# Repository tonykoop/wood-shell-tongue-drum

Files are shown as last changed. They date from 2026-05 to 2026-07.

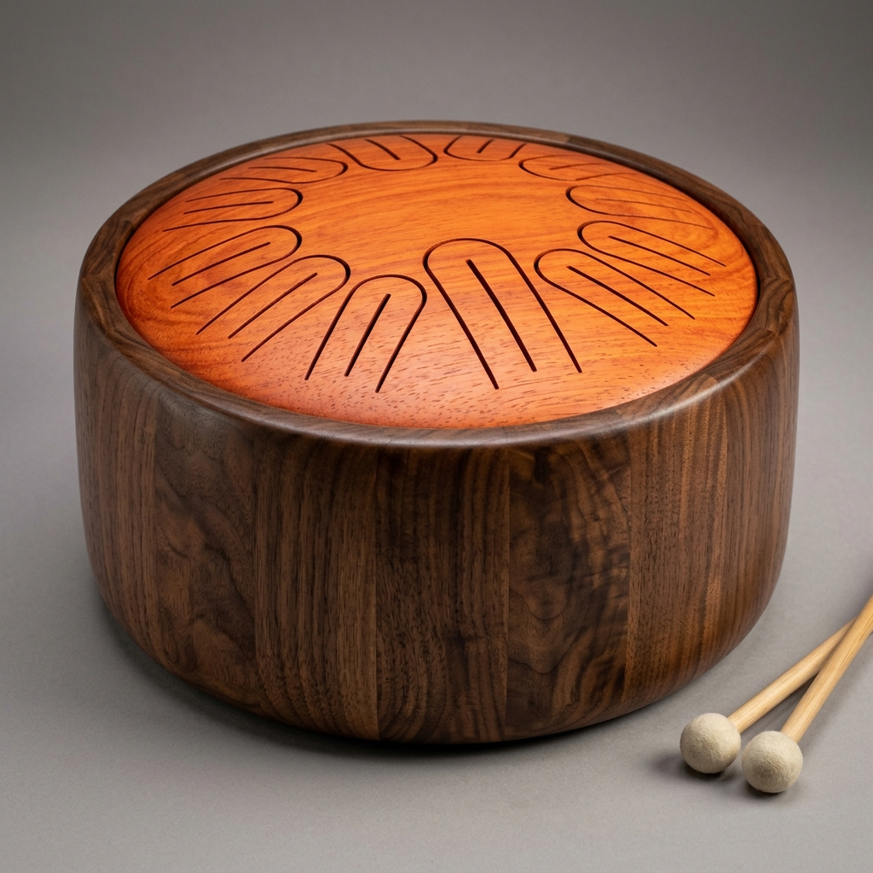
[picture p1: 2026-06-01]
images/hero-render.png

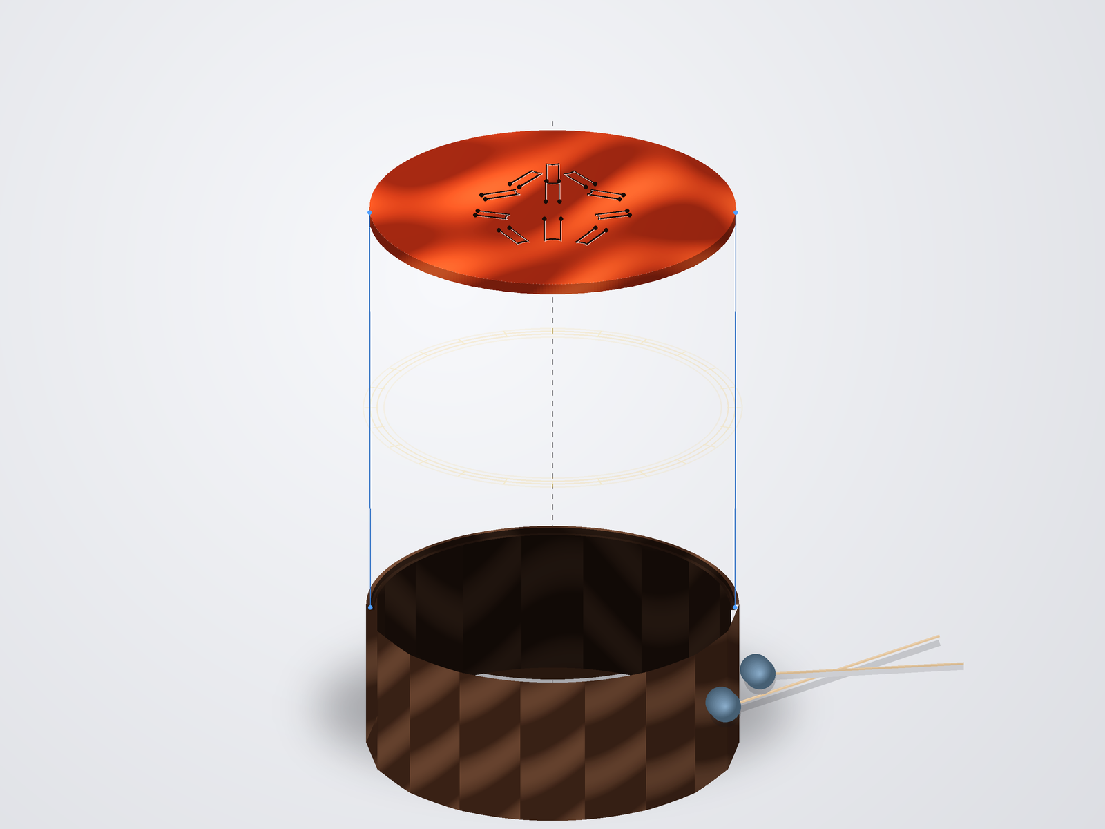
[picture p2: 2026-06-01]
images/exploded-diagram.png

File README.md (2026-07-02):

# Wood Shell Tongue Drum

Status: L2 V5 build-packet candidate

Slit-tongue idiophone with an enclosed wooden resonator. A round-body counterpart to the rectangular-prism wood tongue drum, with **Helmholtz cavity coupling** absent from open designs. Four geometric variants × three size envelopes, all parametric and traceable to a single design table.

Part of the [tonykoop/instrument-maker](https://github.com/tonykoop/instrument-maker) catalogue.

V1 Standard 16″ side section A-A

*V1 Cylinder + Flat Top, Standard 16″ — recommended first prototype. Black Walnut staves, Padauk soundboard, A Kurd 11-tongue field, gu port for Helmholtz tuning. The design table estimates `f_H = 194.6 Hz`, or 0.88 × the A3 ding (220 Hz), which targets the coupled regime but still requires Phase 1 measurement.*

**Current V5 status:** L2 V5 build-packet candidate with pending measurement authority. The design table, packet docs, print packet, and hero SVG are useful for review, but the repo is not build-ready or measured. Tongue tuning, Helmholtz coupling, Padauk material constants, shell response, CAD, DXF, and G-code all remain measurement- or calibration-gated. No Round 2 recovery work added fabricated CAD geometry, DXF coordinates, or new tuning frequencies. See [`v5-readiness.md`](v5-readiness.md), [`tuning-gates.md`](tuning-gates.md), [`validation-loop.csv`](validation-loop.csv), [`visual-output-register.csv`](visual-output-register.csv), and [`explorer.html`](explorer.html).

## What's new in this design

A round-body wood tongue drum with an enclosed cavity is not a commercial category at this depth. Three things distinguish it:

1. **Round body, not rectangular.** Tony's existing rectangular-prism wood tongue drum is the precursor; this design moves the same flat-cantilever physics onto a turned cylinder or hemisphere bowl.
2. **Enclosed Helmholtz cavity.** Open rectangular tongue drums waste cavity volume out the open ends. Closing the bowl puts a Helmholtz resonator under the tongue field — bass extension below the lowest tongue, tunable in the shop via the gu port.
3. **Premium tonewoods, manufacturable scope.** Padauk soundboard for the A4 reference; Black Walnut shell for the bowl. Four variants × three sizes laid out as a coordinated portfolio family rather than four bespoke pieces.

## The matrix

Four geometric variants × three size envelopes = twelve cells. Each cell carries its own chamber volume, Helmholtz frequency, tongue-fit verdict, and risk grade.

| Variant | Body | Top | Risk | Notes |
|---|---|---|---|---|
| V1 | Cylinder (ottoman silhouette) | Flat soundboard | ★★ | Lowest piece-count, most predictable tuning. **Start here.** |
| V2 | Cylinder | Shallow CNC-domed | ★★★ | Steel-tongue-drum aesthetic on a wooden body |
| V3 | Hemisphere bowl | Flat soundboard | ★★ | Tagine / Moroccan-pouf silhouette |
| V4 | Hemisphere bowl | Domed top | ★★★★ | Most steel-tongue-drum-adjacent silhouette in wood |

**Sizes:** Travel 12″ Ø · Standard 16″ Ø (Moroccan-ottoman scale) · Floor Pouf 20″ Ø.

The full Helmholtz/ding ratio matrix is in [`design.md`](design.md) §2.4. Current estimates put three cells in the target coupled band (V1 Standard, V1 Floor Pouf, V3 Standard); V2 cells need a larger-than-preset gu port or a lower cavity/neck correction to reach coupling; V1 Travel sits right at the upper edge of the band.

## Recommended first prototype

**V1 Cylinder + Flat Top, Standard 16″, A Kurd, A3 ding (220 Hz), 11 tongues.** Justification:

- Acoustic predictability — flat-cantilever physics has < 1 % empirical detuning on Tony's prior rectangular drums.
- Design-table Helmholtz ratio targets the coupled band at `f_H/f_ding = 0.88`, pending measured cavity response.
- All 11 A Kurd tongues fit within the 7″ radial cap with 8 % margin.
- Lowest piece-count: 16 staves + 1 disc = 17 wood pieces.
- Dual body-construction paths (stave or segmented) — pick the aesthetic, the physics is the same.
- Previously exercised workflow components — stave glue-up, lathe truing, CNC slit routing — from Tony's existing ashiko, conga, and tongue-drum repos.

Detailed prototype spec (dimensions, tongue length schedule, joint tolerances) in [`design.md`](design.md) §4.

## Acoustic model in one paragraph

The wood shell tongue drum is a 2-DOF coupled oscillator: the cantilever tongue is one resonator, the enclosed air cavity is another, and they share a common boundary (the soundboard). Tongues follow flat-cantilever Euler-Bernoulli `f = K · t / L²`, with `K ≈ 24,438` for Padauk. Domed tongues add a +2.5 % length correction (a starting estimate to be calibrated empirically on the first V2 build). The cavity follows the Helmholtz formula `f_H = (c/2π) · √(A_port / (V · L_neck))`; the gu port is the primary tuning knob — drilled last and step-bored in the shop while measuring `f_H`. Target: `f_H/f_ding ∈ [0.80, 1.20]`. See [`design.md`](design.md) §2 for the full derivation.

## Repo contents

| File / folder | Purpose |
|---|---|
| [`design.md`](design.md) | Governing model, variant blocks, recommended prototype |
| [`wood-shell-tongue-drum-design-table.xlsx`](wood-shell-tongue-drum-design-table.xlsx) | Parametric workbook (190 formulas, 1 sheet) |
| [`family-spec.csv`](family-spec.csv) | Twelve family rows spanning V1-V4 across Travel / Standard / Floor Pouf |
| [`v5-readiness.md`](v5-readiness.md) / [`tuning-gates.md`](tuning-gates.md) / [`validation-loop.csv`](validation-loop.csv) | V5 authority notes, tongue-tuning gates, and empirical validation loop |
| [`visual-output-register.csv`](visual-output-register.csv) / [`explorer.html`](explorer.html) | Visual authority register and root explorer dashboard |
| [`bom.csv`](bom.csv) / [`sourcing.csv`](sourcing.csv) / [`cut-list.csv`](cut-list.csv) / [`validation.csv`](validation.csv) | Manufacturing CSVs |
| [`assembly-manual.md`](assembly-manual.md) | 7-phase build instructions |
| [`supplier-rfq.md`](supplier-rfq.md) | Q2 2026 batch supplier RFQ |
| [`drawing-brief.md`](drawing-brief.md) / [`drawings/`](drawings/) | 9-sheet drawing spec + hero SVG |
| [`visual-bom-brief.md`](visual-bom-brief.md) / [`photo-shotlist.md`](photo-shotlist.md) | Photography briefs |
| [`risks.md`](risks.md) | Red-team pass with verification tests attached |
| [`joinery-configuration-matrix.md`](joinery-configuration-matrix.md) | Practical shell and soundboard joinery comparison for issue `instrument-maker#118` |
| [`resources.md`](resources.md) / [`jig-decision.md`](jig-decision.md) | Public-safe provenance, references, and fixture decisions |
| [`wolfram-starter.wl`](wolfram-starter.wl) | 3-DOF coupled-oscillator notebook starter |
| [`wolfram/`](wolfram/) / [`jigs/`](jigs/) / [`data/`](data/) | Starter folders for notebook notes, fixture docs, and future measurements |
| [`capstone-deck.md`](capstone-deck.md) / [`print-packet.md`](print-packet.md) | Recruiter-facing deck + shop-floor printable packet |
| [`cad/`](cad/) / [`cnc/`](cnc/) | Toolpath plans, jig decisions, laser templates, CAD staging; `cad/wood-shell-tongue-drum.scad` is a parametric shell+soundboard+tongue-layout envelope (`pending_measurement`); `cad/mcp-session-log.md` records provenance |
| [`cnc/jig-and-template-plan.md`](cnc/jig-and-template-plan.md) | Fixture choice matrix for the first prototype and later variants |
| [`site/index.html`](site/index.html) | Build-log static site |
| [`concepts/`](concepts/) | Original concept sheet (ideation, not manufacturable) |
| [`evolution/`](evolution/) | Evolution-pipeline Stage 0 intake: master manifest, design-intent, revision register (Gate A not yet run) |

## Build status

- ✅ Parametric design table (workbook + `design.md` packet)
- ✅ BOM, sourcing, cut list, validation CSVs
- ✅ Assembly manual, supplier RFQ, drawing brief, visual BOM brief, photo shot list
- ✅ Risks register (16 entries across acoustic, structural, ergonomic, supply, fit/finish)
- ✅ Family-spec row set, resources notes, tuning gates, and jig-decision adjuncts
- ✅ Wolfram notebook starter (3-DOF coupled oscillator)
- ✅ CNC/laser/jig decision plan for public review
- ✅ Build-log site (`site/index.html`)
- ✅ Hero side-section preview (`drawings/00-hero-v1-standard.svg`; derived preview only, not fabrication authority)
- ✅ V5 authority register and MCP-session-log stub
- ⏳ Phase 1 prototype: V1 Cylinder · Flat at 16″ Standard
- ⏳ SolidWorks CAD assembly (deferred until first-prototype calibration)
- ⏳ Auto-generated SVG sheets 01–09 from `scripts/generate_drawings.py`
- ✅ Capstone markdown and print-packet PDF generated from the repo sources
- ⏳ Capstone .pptx refresh (requires python-pptx in the local generator environment)

## Prototype Planning Boundary

For current V5 work, treat this repo as a prototype/planning packet: excellent
for design review and first-prototype planning, but not build-ready evidence.
The coupled cantilever-plus-Helmholtz plan is documented, yet the critical
values still need real prototype measurements: Padauk effective K, port end
correction, tongue pitch, chamber response, sustain, and seasonal joint
behavior.

The packet can advance only after the V1 Standard prototype has populated
`validation.csv` and `validation-report.md` with measured Hz, cents error,
Helmholtz response, tuning-pass notes, and post-rest drift.

## Highest-risk unknowns

To be retired by Phase 1 measurements:

1. Curved-cantilever multiplier for our specific dome rise (V2/V4 only; +2.5 % is a starting estimate).
2. Helmholtz end-correction term for slit ports vs circular ports (all variants).
3. Padauk K-constant for our specific stock vs the library value (24,438).
4. Bowl-top rabbet joint long-term durability under seasonal humidity cycling.
5. Player ergonomics on Floor Pouf 20″ (new size class for Tony's catalog).

Full risk register with mitigations and verification tests in [`risks.md`](risks.md).

## Sister repos

- [`tonykoop/tongue-drum`](https://github.com/tonykoop/tongue-drum) — rectangular-prism precursor, validates flat-cantilever physics
- [`tonykoop/steel-tongue-drum`](https://github.com/tonykoop/steel-tongue-drum) — steel cantilever cousin
- [`tonykoop/ceramic-tongue-drum`](https://github.com/tonykoop/ceramic-tongue-drum) — slip-cast cousin
- [`tonykoop/ashiko-drum-workshop`](https://github.com/tonykoop/ashiko-drum-workshop) — segmented bowl reference
- [`tonykoop/conga`](https://github.com/tonykoop/conga) — stave & segmented shell reference
- [`tonykoop/instrument-maker`](https://github.com/tonykoop/instrument-maker) — orchestrating skill, Master Catalog, validate_packet.py

## License

[CC BY 4.0](LICENSE) — see LICENSE for details. The design (workbook, drawings, narrative) is shared under CC BY 4.0; the maker should still apply their own judgment to material selection and shop safety.

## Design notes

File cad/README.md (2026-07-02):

# CAD — Wood Shell Tongue Drum

This folder holds the SolidWorks parametric assembly and any exported neutral-format files (STEP, IGES, STL) for the wood shell tongue drum family.

## Status

**Empty at first commit.** SolidWorks files are produced after the first prototype's measurements are folded back into the workbook so the CAD reflects calibrated, not estimated, dimensions.

**Update 2026-07-01:** `wood-shell-tongue-drum.scad` was added as a parametric
OpenSCAD *planning envelope* (shell + soundboard + tongue position/length
layout reference marks from design.md §4 and drawing-brief.md Sheet 03). It
is `pending_measurement`, does not model slit-routing cut geometry, and does
not replace the SolidWorks assembly plan below.

## Planned contents

```
cad/
├── README.md                    (this file)
├── wood-shell-tongue-drum.SLDASM        — top-level family assembly
├── parts/
│   ├── shell-cylinder.SLDPRT            — V1, V2 body
│   ├── shell-hemisphere.SLDPRT          — V3, V4 body
│   ├── soundboard-flat.SLDPRT           — V1, V3 top
│   ├── soundboard-domed.SLDPRT          — V2, V4 top
│   ├── stave-template.SLDPRT
│   ├── ring-segment-template.SLDPRT
│   └── gu-port-feature.SLDPRT
├── design-table/
│   └── wood-shell-tongue-drum-design-table.xlsx  — symlink to repo root
├── exports/
│   ├── v1-standard-16.step               — for KiCad/Fusion interop
│   ├── v1-standard-16.stl                — for 3D-print prototype shells
│   └── soundboard-tongue-field.dxf       — for laser-cut tongue layout templates
└── sw-reference/
    └── (Pack-and-Go bundles for derived family members)
```

## SolidWorks workflow

The assembly is **driven by the parametric workbook** (`wood-shell-tongue-drum-design-table.xlsx`) at the repo root. Per `references/solidworks-integration.md` in the parent instrument-maker skill, the workflow is:

1. Open `wood-shell-tongue-drum.SLDASM` in SolidWorks.
2. The design table is linked via External Reference. SolidWorks reads the size-preset block (rows 179–195) on rebuild.
3. Change a preset cell in the workbook; rebuild the assembly; geometry updates.
4. Run the `Extract_Dimensions.swp` macro (in `assets/solidworks/` of the parent skill) to dump every dimension to a CSV.
5. Run `python3 scripts/ingest_dimension_csv.py --csv ... --workbook ...` from the parent skill to validate SW dimensions vs Excel design table within ± 0.5 % tolerance.

A MasterLayout pattern (per Tony's standard) keeps geometry coherent across V1 → V4 by sharing the shell-OD, shell-height, and soundboard-thickness sketches.

## Why CAD is deferred

The first prototype is V1 Cylinder + Flat Top, Standard 16″ — a geometry that is fully specified by the workbook formulas and the cut-list dimensions. Stave geometry, lathe truing, and rabbet joint can all be built from the cut-list alone. CAD becomes load-bearing when:

1. We need 3D-surface toolpaths for V2/V4 dome work (fed to Fusion CAM).
2. We want to pre-visualize the segmented bowl ring stack for V3/V4.
3. The polychrome-segment aesthetic requires per-segment color planning.

Until then, the workbook drives the build and CAD ships when its leverage justifies its production cost.

## Cross-references

- Parametric source: [`../wood-shell-tongue-drum-design-table.xlsx`](../wood-shell-tongue-drum-design-table.xlsx)
- Drawing brief (what the SVGs will show): [`../drawing-brief.md`](../drawing-brief.md)
- CNC toolpath plan: [`../cnc/README.md`](../cnc/README.md)
- SolidWorks workflow reference: [`tonykoop/instrument-maker`](https://github.com/tonykoop/instrument-maker) → `references/solidworks-integration.md`

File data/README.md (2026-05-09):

# Data

Measured build data lands here once physical prototypes begin.

## Expected Artifacts

- First-strike pitch logs per tongue.
- Helmholtz port-step measurements.
- Kerf and thickness verification notes.
- Sustain / decay captures.
- Photos or scans of handwritten bench notes that support `validation.csv`.

## Current Status

No measured prototype data exists yet. Until then, `validation.csv` remains a prediction-and-plan surface rather than a completed results table.

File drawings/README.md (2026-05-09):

# Drawings

The current packet ships a single hero SVG and a detailed drawing brief. Full sheet generation is intentionally deferred until the workbook and first-prototype measurements stabilize the family dimensions.

## Present In Repo

- `00-hero-v1-standard.svg` - public-safe side-section hero for the recommended first prototype.

## Planned Sheet Set

- `01-variant-matrix.svg`
- `02-v1-standard-side-section.svg`
- `03-v1-standard-tongue-layout.svg`
- `04-shell-stave-template.svg`
- `05-shell-segment-template.svg`
- `06-rabbet-joint-detail.svg`
- `07-dome-toolpath.svg`
- `08-bowl-segment-stack.svg`
- `09-gu-port-tuning-progression.svg`

## Source Of Truth

See `../drawing-brief.md` for the required dimensions, datums, tolerances, and sheet intent.

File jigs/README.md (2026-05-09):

# Jigs

This folder tracks fixture intent without pretending the physical jigs are already built.

## Required Jigs

1. Stave bevel reference jig for 11.25 degree cylinder staves.
2. Shell glue-up support or caul that preserves roundness through cure.
3. Soundboard layout overlay and hold-down clearance template.
4. Temporary tuning / measurement support that does not damp the tongue field.

## Future Jigs

- Dome flip jig for V2 and V4.
- Hemisphere ring-stack centering fixture for V3 and V4.
- Gu-port drilling locator if repeated family builds justify it.

## Cross-Reference

See `../cnc/jig-and-template-plan.md` for the current decision matrix and validation gates.

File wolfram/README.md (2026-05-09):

# Wolfram

Wolfram-specific notes and future notebook derivatives live here.

## Current Source

- `../wolfram-starter.wl` - starter notebook source for the coupled tongue + cavity model.

## Planned Contents

- Exploratory notebooks for dome-multiplier back-solving.
- Helmholtz port-step plots from measured builds.
- Family comparison plots once Travel / Standard / Floor Pouf data exists.

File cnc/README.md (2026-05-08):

# CNC — Wood Shell Tongue Drum

This folder holds CNC toolpaths, post-processed G-code, fixture STLs, and tool-list files for the wood shell tongue drum family.

For the public review pass, the most important CNC deliverable is the setup logic rather than premature G-code. The first prototype can be built from the workbook, cut list, and manual CAM setup, while later V2/V4 dome work waits for calibrated CAD. The fixture and template choices are tracked in [`jig-and-template-plan.md`](jig-and-template-plan.md).

## Critical CNC operations

| Operation | Variants | Tool | Stock | Stepover / DOC |
|---|---|---|---|---|
| Soundboard tongue slits | All | 1/8″ upcut spiral, 1/4″ shank  | Padauk disc, 0.25″–0.5″ thick | full-depth single pass at 100 ipm feed |
| Soundboard OD profile cut | All | 1/4″ compression, 1/4″ shank | Padauk disc, oversize blank | 0.250″ DOC, multi-pass |
| Dome 3D surfacing — convex top| V2, V4 | 3/4″ ball-end, 1/2″ shank | Padauk glue-up blank, 1.5″ thick | 0.05″ stepover, 0.25″ DOC |
| Dome 3D surfacing — concave bottom | V2, V4  | 3/4″ ball-end, 1/2″ shank | flip-jig with datum pins | 0.05″ stepover, 0.25″ DOC |
| Bowl 3D surfacing — exterior  | V3, V4 (CNC alt) | 3/4″ ball-end, 1/2″ shank  | Black Walnut glue-up blank, 5″ thk | 0.05″ stepover, 0.50″ DOC |
| Bowl 3D surfacing — interior  | V3, V4 (CNC alt) | 3/4″ ball-end, 1/2″ shank  | flip-jig with datum pins | 0.05″ stepover, 0.50″ DOC |

## Tool list

All tools listed in `bom.csv` under tooling rows. Critical tools:

- `SLIT-BIT-UPCUT-1-8` — Amana 46202 1/8″ solid carbide upcut spiral. Buy 3 (one breaks per shell).
- `BALLEND-3-4` — Amana 46377 3/4″ ball nose, 1/2″ shank. One bit good for 3+ dome surfaces if kept clean.

## Laser/template plan

| Template | Tool | Material | Purpose | Public-review status |
|---|---|---|---|---|
| Soundboard tongue layout | Laser | 1/8″ MDF or chipboard | Physical overlay to verify tongue spacing before CNC routing | Required before first cut |
| Vacuum gasket / tape map | Laser | 1/16″ rubber sheet or kraft template | Keeps hold-down clear of slit kerfs and tongue tips | Required before first cut |
| Stave numbering labels | Laser or printer | Masking tape / paper | Keeps 16-stave grain order stable through glue-up | Nice-to-have |
| Gu-port tuning card | Laser or printer | Cardstock | Measurement log by port diameter; taped to the bench during step drilling | Required for validation |

## Tongue-slit toolpath spec

The tongue field on the recommended V1 Standard 16″ prototype has 11 slits in the A Kurd zigzag-ascending layout (see `drawing-brief.md` §03 for radial coordinates).

**Fixture:** soundboard disc held face-up on a 16″ MDF backing board with double-sided tape OR vacuum hold-down. Datum: disc center to spindle home.

**Cut order:** ding first (centered slit), then tongues 1, 2, 3, … in radial order. Cutting from inside-out minimizes stress accumulation.

**Cut depth:** through the soundboard thickness + 0.030″ to ensure clean break-through into the spoilboard. On 0.375″ Padauk: cut depth = 0.405″.

**Feed/speed:** 100 ipm feed at 18,000 RPM with 1/8″ upcut spiral. Validate on a poplar test cut first.

**Tongue-base relief:** the slit terminus is a 1/8″-radius half-circle at the tongue base (eyelet detail). This relieves stress concentration and gives a defined free length. The radius matches the bit diameter — single-axis plunge then retract.

**Slit width:** 1/8″ kerf (single pass with the 1/8″ bit). Holding ± 0.005″ kerf width is critical; verify with feeler gauge on a test cut.

## Dome 3D-surfacing toolpath spec (V2, V4)

Dome blank: 17″ × 17″ × 1.5″ Padauk glue-up, 3 plies of 0.5″.

**Coordinate system:** Z-zero on the top of the blank; X/Y origin at the blank center.

**Surface model:** parabolic dome with rise per size preset (Standard: 0.75″). Equation in Fusion / SolidWorks: `z = rise × (1 - (r/R)^2)` where `R = OD/2` and `r = sqrt(x² + y²)`.

**Stepover:** 0.05″. Adaptive scallop control around the rim where the slope is steepest.

**Two-sided machining:**
1. Machine convex top first; allow the bottom datum pins to remain unprofiled.
2. Flip-jig the blank into a fixture with three datum pins located 1″ inside the 16″ rim circle.
3. Machine concave bottom matching the rabbet rim profile.

**Surface finish target:** ≤ 32 µin Ra. Verify with a comparator block; if scallop steps are visible, reduce stepover to 0.03″.

## Pre-built G-code files

```
cnc/
├── README.md                    (this file)
├── tongue-slits-v1-standard.nc  — recommended first prototype slit field
├── tongue-slits-v1-travel.nc    — 12" Travel size
├── tongue-slits-v1-floor.nc     — 20" Floor Pouf size
├── soundboard-od-profile.nc     — disc cut to OD with rabbet allowance
├── dome-convex-v2-standard.nc   — V2 Standard 16" dome top
├── dome-concave-v2-standard.nc  — V2 Standard 16" dome bottom
├── dome-convex-v4-standard.nc   — V4 Standard 16" dome top (same as V2)
└── fixtures/
    ├── flip-jig-datum-pins.stl  — 3D-print fixture for dome flip
    ├── soundboard-vacuum-mat.dxf — laser-cut vacuum gasket pattern
    └── tongue-field-jig.stl     — workholding for tongue-tuning at the bench
```

## Status

**G-code files are intentionally deferred at first public review.** They are emitted from the SolidWorks / Fusion CAD models once the first prototype's measurements have calibrated the workbook formulas. Building the V1 Standard prototype from the cut list and manual CAM setup is the recommended fast-track to first measurements.

## Cross-references

- Tongue lengths: [`../design.md`](../design.md) §4
- Tool spec: [`../bom.csv`](../bom.csv) (tooling rows)
- CAD source: [`../cad/README.md`](../cad/README.md)
- Drawings: [`../drawing-brief.md`](../drawing-brief.md)

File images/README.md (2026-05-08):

# Images

Photographs of the wood shell tongue drum prototype, build process, and finished pieces. Populated against [`../photo-shotlist.md`](../photo-shotlist.md).

## Status

**Empty at first commit** — no physical prototype exists yet. The hero side-section drawing in `../drawings/00-hero-v1-standard.svg` carries the visual weight of the documentation until Phase 1 prototype photography begins.

## Naming convention

`<SHOT-ID>_<short-slug>.jpg` (e.g., `HERO-001_v1-std-finished.jpg`).

Shot IDs are defined in `../photo-shotlist.md`. As builds complete, each Required entry's Status is updated to Captured and the file path is dropped into the shot-list table.

## Resolution

- Capture: 4000 × 6000 minimum (≥ 24 MP).
- Web export (for `../site/index.html`): 2000 × 3000 JPEG, ~85 % quality.
- Print export (for `../print-packet.pdf`): full resolution, embedded via `../scripts/generate_capstone_docs.py`.

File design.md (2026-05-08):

# Wood Shell Tongue Drum — Parametric Design Sheet

**Owner:** Tony Koop · Heifer Zephyr Instruments
**Family:** Slit-tongue idiophone with enclosed wooden resonator (round-body)
**Members:** four geometric variants (V1–V4) × three size envelopes (Travel 12″, Standard 16″, Floor Pouf 20″)
**Status:** Design v1 — formulas parametric in `wood-shell-tongue-drum-design-table.xlsx`; no physical prototype yet
**Recommended first prototype:** **V1 Cylinder + Flat Top, Standard 16″, A Kurd**

---

## 1. Intent

This is the round-body counterpart to Tony's existing rectangular-prism wood tongue drum. A wooden shell — cylinder or hemisphere — capped by a tonewood soundboard with CNC-cut slit tongues, tuned to a chosen scale, is a modern instrument category that does not exist commercially in this round-body × dome-top × premium-tonewood format. The enclosed cavity adds **Helmholtz resonance** that an open rectangular tongue drum cannot offer — warm bass coupling beneath the lowest tongue.

The sheet treats this as a *family with four variants* rather than as four separate designs. All twelve cells (4 variants × 3 sizes) are driven by the same shared inputs: shell OD, shell height, soundboard thickness/wood, gu-port diameter, dome rise. Change one preset cell in the workbook and every dimension in the matrix updates.

| ID  | Body | Top | Notes |
|-----|---|---|---|
| V1  | Cylinder | Flat | Lowest piece-count, most predictable tuning. **Start here.** |
| V2  | Cylinder | Domed | Steel-tongue-drum aesthetic on a wooden body |
| V3  | Hemisphere bowl | Flat | Tagine / Moroccan-pouf silhouette; bowl as parabolic reflector |
| V4  | Hemisphere bowl | Domed | Most steel-tongue-drum-adjacent silhouette in wood; near-spherical |

| Size | OD (in) | Height (in) | Soundboard (in) | Tongue width (in) | Target ding | Ding f (Hz) |
|---|---|---|---|---|---|---|
| Travel | 12 | 5 | 0.250 | 1.00 | D4 (MIDI 62)| 293.66 |
| Standard | 16 | 8 | 0.375 | 1.25 | A3 (MIDI 57)| 220.00 |
| Floor Pouf | 20 | 10 | 0.500 | 1.50 | D3 (MIDI 50)| 146.83 |

(All values in this document are computed from the workbook formulas, not pasted by hand. If you change the workbook, regenerate the BOM and validation CSVs.)

---

## 2. Governing acoustic model

The wood shell tongue drum is a **two-degree-of-freedom coupled oscillator**: the cantilever tongue is one resonator, the enclosed air cavity is another, and they share a common boundary (the soundboard).

### 2.1 Tongue — flat cantilever (Euler–Bernoulli)

For a slit tongue of length `L` (in) and thickness `t` (in) in wood with cantilever K-constant `K` (imperial composite):

```
f = K · t / L²              (flat top, Variants 1 and 3)
L = √( K · t / f )
```

Tony's material library (workbook §A, rows 19–25) records measured / literature K-constants for shop tonewoods:

| Wood | E (GPa) | ρ (kg/m³) | K (cantilever) | Tone | Rating |
|---|---|---|---|---|---|
| Padauk | 11.0 | 745 | 24,438 | warm, rich, sustain| ★★★★★ |
| Wenge | 15.8 | 870 | 27,103 | bright, punchy | ★★★★★ |
| Cherry | 10.3 | 560 | 27,275 | balanced sweet mid | ★★★★  |
| Black Walnut  | 11.6 | 610 | 27,734 | full, mellow | ★★★★  |
| Hard Maple | 12.6 | 705 | 26,887 | bright sustain | ★★★★  |
| Mahogany | 10.1 | 590 | 26,314 | warm, full bass | ★★★★  |
| W. Red Cedar  |  7.7 | 370 | 29,013 | light, guitar-like | ★★★ |

Padauk K = 24,438 is the lowest in the library and therefore yields the longest tongues for a given pitch — the design defaults to Padauk because it is most permissive of fitting low pitches in a given shell radius.

### 2.2 Tongue — curved cantilever (V2, V4)

A tongue cut into a domed soundboard is stiffer than a flat tongue. To preserve pitch we apply an empirical length correction:

```
L_curved = L_flat · 1.025         (+2.5 % for shallow domes, dome rise ≤ 6 % of OD)
```

This is a **starting estimate**, not a measured constant. The dominant uncertainty in V2 and V4 is whether 1.025 holds for our specific dome rise. Validation protocol: tap-tune one tongue at the design length, measure with a tuner, back-solve the actual factor, then apply to the remaining ten tongues. Treat the +2.5 % multiplier as *the empirical-learning loop's first measurement*.

### 2.3 Cavity — Helmholtz resonator

For an enclosed chamber of volume `V` (in³) with port area `A_port` (in²) and effective neck length `L_neck` (in):

```
f_H = (c / 2π) · √( A_port / (V · L_neck) )           with c = 13,552 in/s
```

Chamber volume formulas, by variant:

| Variant | Body shape | Cavity volume formula |
|---|---|---|
| V1 | Cylinder, flat top | `V = π · r² · H` |
| V2 | Cylinder + dome | `V = π · r² · H + (2/3) · π · r² · h_dome` |
| V3 | Hemisphere, flat | `V = (2/3) · π · r³` |
| V4 | Hemisphere + dome  | `V = (2/3) · π · r³ + (2/3) · π · r² · h_dome` |

Effective neck length:

| Top type | `L_neck` |
|---|---|
| Flat | soundboard thickness `t` |
| Domed | `t + h_dome / 2` |

The **Helmholtz target** is `f_H ≤ f_ding` — the cavity should resonate at or below the lowest tongue, so it acts as a bass extension rather than a competing pitch. Coupling falls into one of three regimes:

- `f_H / f_ding < 0.8` — free bass extension; cavity reinforces below the ding (good for floor pouf).
- `0.8 ≤ f_H / f_ding ≤ 1.2` — coupled regime; cavity and ding share modal energy (the design target).
- `f_H / f_ding > 1.2` — cavity sits above the ding; cavity will fight the ding rather than support it. **Mistuned high** — lower `f_H` by reducing effective port area, adding a removable restrictor/liner, lengthening the neck, or increasing the chamber volume.

The **gu port diameter** is the primary tuning knob. Because `f_H ∝ sqrt(A_port)`, opening the port raises the Helmholtz frequency; reducing effective area or increasing neck length lowers it. The port is drilled last, deliberately undersized, and opened up incrementally with a step bit while measuring `f_H` (gentle puff at the port, microphone above). This is the same field-tuning method used on Hapi-style steel tongue drums.

### 2.4 Computed Helmholtz / ding ratios (current presets)

Each cell below is `f_H` (Hz) computed from the formulas above with the current size-preset inputs, and the ratio against `f_ding` for that size. Bold cells sit in the coupled regime (0.8 ≤ ratio ≤ 1.2) — that is the buildable matrix.

| Variant | Travel 12″ (D4 ding 293.66 Hz) | Standard 16″ (A3 ding 220.00 Hz) | Floor Pouf 20″ (D3 ding 146.83 Hz) |
|---|---|---|---|
| V1 | 321.5 Hz · ratio **1.09** (tight) | **194.6 Hz · ratio 0.88** | **144.7 Hz · ratio 0.99** |
| V2 | 220.1 Hz · ratio 0.75 | 133.5 Hz · ratio 0.61 (under-coup) | 99.1 Hz · ratio 0.67 (under-coup) |
| V3 | 359.5 Hz · ratio 1.22 (over) | **238.3 Hz · ratio 1.08** | 177.2 Hz · ratio 1.21 (over, edge)  |
| V4 | 244.2 Hz · ratio 0.83 | 161.1 Hz · ratio 0.73 | 119.5 Hz · ratio 0.81 |

Reading the matrix: **V1 Standard 16″ and V1 Floor Pouf 20″ are in the sweet spot**; V3 Standard 16″ is also coupled. V2 cells are systematically under-coupled because the dome adds neck length without proportional volume — they will need a *larger* effective gu port than the preset 2.5″, a shorter effective neck, or a revised dome cavity model to lift `f_H`. V1 Travel 12″ is right at the upper edge of the coupled band.

### 2.4.1 Gu-port tuning direction

| Condition | Field symptom | Corrective direction | First shop action |
|---|---|---|---|
| `f_H/f_ding < 0.80` | Cavity too low / under-coupled | Raise `f_H` | Enlarge gu port in 0.25″ steps; if already at structural max, reduce neck length or revise chamber volume |
| `0.80 ≤ f_H/f_ding ≤ 1.20` | Coupled | Hold | Stop drilling; record final port diameter and environment |
| `f_H/f_ding > 1.20` | Cavity too high | Lower `f_H` | Install removable restrictor/liner, lengthen neck with a port sleeve, or increase chamber volume on the next build |

For the Standard 16″ V2 preset, the 2.5″ port predicts 133.5 Hz (`0.61 × ding`). A first-order diameter solve puts the lower coupled edge near 3.3″ and the `0.95 × ding` target near 3.9″, so the V2/V4 validation build should treat the port as a measured design variable, not a fixed decorative hole.

These values are **derived estimates**, not measured. They will shift once the first prototype is tuned and the per-family corrections database is populated.

### 2.5 Tongue-fit cap

For each size, the longest tongue (the ding) cannot exceed the radial fit cap:

```
L_cap = OD/2 − 1″                  (1″ reserved for ding-strike clearance and rim)
```

| Size | Cap (in) | V1/V3 ding length (in) | V2/V4 ding length (in) | Verdict |
|---|---|---|---|---|
| Travel 12″  | 5.00 | 4.56 (D4) | 4.68 (D4) | Fits — 9 % margin |
| Standard 16″| 7.00 | 6.45 (A3) | 6.62 (A3) | Fits — 8 % margin |
| Floor Pouf  | 9.00 | 9.12 (D3) | 9.35 (D3) | **Doesn't fit** |

Floor Pouf D3 ding overhangs by 0.12″ on flat tops and 0.35″ on domed tops. **Mitigation:** raise the ding to D♯3 (one semitone, MIDI 51, 155.6 Hz → flat L = 8.86″, fits with 0.14″ margin) OR thin the soundboard from 0.5″ → 0.4375″ (drops L to 8.53″, clean 0.47″ margin) OR substitute Cedar (K = 29,013 → flat L = 8.34″, 0.66″ margin). Cedar is the recommended fix because the soundboard span across 20″ wants stiffness against deflection, and Cedar's lower density lets the same thickness still bear the span.

---

## 3. Variant blocks — manufacturing and acoustic notes

Each block extends the workbook's §C–§F by spelling out the *manufacturing path* implied by the geometry.

### V1 — Ottoman Cylinder, Flat Top  ★ RECOMMENDED FIRST BUILD

**Body construction:** stave-built or segmented cylinder. The two paths are equally valid:

- **Stave shell**: 16 staves at 11.25° miter (180/16). Rip from 4/4 stock, joint edges, band-clamp glue-up around an MDF cylinder mold. Lathe-true OD/ID after cure (≥ 24 h). Wall thickness after turning: 5/8″–3/4″.
- **Segmented shell** (used when polychrome inlay is desired): 8 rings × 12 segments at 15° miter. Stack rings on a lazy-susan jig for glue-up. Diamond pattern with Walnut + Maple + Cherry accents reads beautifully on the Ottoman 16″ size.

**Top construction:** flat tonewood disc, CNC-cut to OD and edge-rabbeted ¼″ deep into the shell rim. Slits routed *before* glue-up so the tongues vibrate without router stress. Disc diameter = shell OD; thickness from preset.

**Tongue physics:** standard flat cantilever. Empirical detuning ≤ 1 % observed on Tony's prior rectangular drums — trust the model.

**Risk / Difficulty:** ★★ — proven flat-cantilever physics + well-trodden stave/segmented bowl method. Lowest risk in the matrix.

### V2 — Ottoman Cylinder, Domed Top

**Body construction:** same as V1.

**Top construction:** glue-up blank (3 plies × ~0.5″ = 1.5″ thick), flatten on jointer, then 3D-surface a parabolic dome (rise = preset 0.75″ on Standard) on the CNC. Bottom contour matches OD rim. Tongue slits cut afterward in one of two ways: (a) 1/8″ upcut spiral on a B-axis sled that tracks the dome curvature (preferred — preserves the dome face) or (b) flatten a sacrificial fixture under the dome to support tongue ends, then route slits with a regular 3-axis pass.

**Tongue physics:** curved cantilever stiffer than flat. The +2.5 % length correction is built into the workbook. Validate empirically: tap-tune ONE tongue and back-fit the multiplier *before* cutting all 11.

**Risk / Difficulty:** ★★★ — adds dome-surfacing risk and curved-cantilever uncertainty. Prototype the dome in poplar before committing Padauk.

### V3 — Hemisphere Bowl, Flat Top

**Body construction:** segmented (ring-stack of decreasing diameters approximating a hemisphere) or thick-glue-up CNC-carved hemisphere. Either path requires lathe-true rim flatness — the bowl-to-soundboard joint is acoustically critical.

**Top construction:** flat soundboard disc (same as V1). The shell rim must be precisely circular and planar — turn the rim true on the lathe *after* segment glue-up. Rabbet for the board is ¼″ deep.

**Tongue physics:** same flat cantilever as V1. The bowl shape doesn't affect tongue physics, only the Helmholtz coupling and projection pattern (the bowl acts as a parabolic reflector, projecting tongue energy upward through the slits).

**Risk / Difficulty:** ★★ — bowl turning is straightforward at 12–16″; > 18″ needs a lathe with ≥ 10″ swing over bed.

### V4 — Hemisphere Bowl, Domed Top

**Body construction:** glued bowl (segmented or stave) + glue-up dome blank, both 3D-surfaced on the CNC. Half-lap or rabbet joinery at the rim. Final assembly clamps with a custom radius caul.

**Top construction:** same dome workflow as V2.

**Tongue physics:** curved cantilever +2.5 % correction (same as V2). The flat → curved physics shift is the dominant uncertainty in V4; budget extra prototype tongues.

**Risk / Difficulty:** ★★★★ — highest piece-count + highest empirical tuning risk. Most beautiful result; **build last**.

---

## 4. Recommended first prototype — V1 Cylinder + Flat Top, Standard 16″

This is the **strongly recommended starting build**. Justification:

1. **Acoustic predictability.** Flat-cantilever physics has < 1 % empirical detuning on Tony's prior rectangular drums; the dome correction in V2/V4 is unmeasured.
2. **Helmholtz already coupled.** Standard 16″ V1 sits at `f_H / f_ding = 0.88` — inside the coupled band by design, with the gu port (2.5″) as the in-shop tuning knob if the measured ratio drifts.
3. **All 11 tongues fit cleanly.** Longest tongue (A3 ding) = 6.45″ vs the 7″ radial cap → 8 % margin. No risk of running out of soundboard.
4. **Lowest piece-count.** 16 staves + 1 disc = 17 wood pieces. Compare V4 segmented-bowl-plus-dome at 96+ pieces.
5. **Dual-path body construction.** If staves don't inspire the maker, the same shell can be built segmented for polychrome aesthetics (see V1 body construction notes).
6. **Validated workflow components.** Stave glue-up, lathe truing, CNC slit routing — all are skills exercised on Tony's existing ashiko, conga, and tongue-drum repos.

**Specific prototype build configuration:**

| Parameter | Value |
|---|---|
| Shell OD | 16.00″ |
| Shell height | 8.00″ |
| Shell wood | Black Walnut, 4/4 stock, 16 staves at 11.25° miter |
| Wall thickness | 0.625″ finished (after lathe truing) |
| Soundboard wood | Padauk (K = 24,438) |
| Soundboard thk | 0.375″ (3/8″) |
| Disc diameter | 16.00″ (rabbet ¼″ deep × ⅜″ wide into shell rim) |
| Scale | A Kurd (A3, B3, C4, D4, E4, F4, G4, A4, B4, C5, D5) |
| Ding | A3 (220.00 Hz), centered |
| Number of tongues | 11 (1 ding + 10 in zigzag-ascending pattern) |
| Slit kerf width | 0.125″ (1/8″ CNC upcut spiral) |
| Tongue width | 1.25″ |
| Gu port Ø | 2.5″ initial; final size set by Helmholtz tuning |
| Predicted f_H | 194.6 Hz (0.88 × ding) |

**Tongue length schedule** (Padauk 0.375″, A Kurd transposed from workbook §A reference scale):

| # | Note | MIDI | Freq (Hz) | L (in) | L (mm) |
|---|---|---|---|---|---|
| Ding | A3 | 57 | 220.00 | 6.454  | 163.93 |
| 1 | E4 | 64 | 329.63 | 5.273  | 133.93 |
| 2 | F4 | 65 | 349.23 | 5.123  | 130.12 |
| 3 | G4 | 67 | 392.00 | 4.835  | 122.81 |
| 4 | A4 | 69 | 440.00 | 4.564  | 115.92 |
| 5 | B4 | 71 | 493.88 | 4.308  | 109.41 |
| 6 | C5 | 72 | 523.25 | 4.185  | 106.30 |
| 7 | D5 | 74 | 587.33 | 3.950  | 100.33 |
| 8 | E5 | 76 | 659.26 | 3.728  |  94.70 |
| 9 | G5 | 79 | 783.99 | 3.419  |  86.84 |
| 10 | A5 | 81 | 880.00 | 3.227  |  81.97 |

(These are *cut lengths* of the slit, not the kerf. The CNC pocketing geometry — radial slit + perpendicular tongue-base relief — is detailed in `drawing-brief.md` and `cnc/README.md`.)

---

## 5. Build sequence — phases across the family

Phases are designed so each one produces a finished, playable instrument *and* a measurement that informs the next phase. This is the empirical-learning loop running across the four-variant matrix.

| Phase | Build | What it teaches |
|---|---|---|
| 1 | **V1 Standard 16″** ★ HERE | Shell stave construction, soundboard rabbet joint, gu-port tuning, Helmholtz coupling — all in one go. Confirms `f_H` model against measurement. |
| 2 | V2 Standard 16″ (same shell) | Curved-cantilever +2.5 % correction. Reuse Phase-1 cylinder shell — only the soundboard changes. Quantifies the dome correction factor. |
| 3 | V3 Standard 16″ | Hemisphere-bowl construction independent of dome work. Now we know flat-top + bowl independently. |
| 4 | V4 (Standard 16″ or Floor 20″) | Combine learnings. Premium tonewoods, signature Heifer Zephyr finish. |
| 5 | V1 Travel 12″ | Tightest tongue-fit margins; build last when the formulas are calibrated to your shop. |

This sequence delivers four distinct portfolio instruments while progressively retiring acoustic risk. Each phase's measurements feed back into `validation.csv` and the per-family corrections in the workbook.

---

## 6. Critical joints and tolerances

| Joint | Tolerance | Why |
|---|---|---|
| Shell rim flatness | ± 0.005″ TIR | Bowl-to-soundboard joint is the primary air seal (Helmholtz Q) |
| Soundboard rabbet fit | 0.005″ slip-fit  | Tight enough for PVA bond, loose enough to avoid prying |
| Stave miter angle | 11.25° ± 0.1° | A 0.5° error compounds over 16 staves to a 8° total deviation |
| Slit kerf width | 0.125″ ± 0.005″  | Wider kerfs lower tongue Q (energy leaks through the kerf) |
| Tongue length (per cut) | + 0.030″ initial | Cut long; file to pitch with a sanding bar (file shortens → raises pitch) |
| Gu port concentricity | ± 0.025″ | Off-center port shifts effective neck length and `f_H` |
| Wall thickness uniformity  | ± 0.030″ | A wedge-shaped wall makes the cavity asymmetric — kills bass |

---

## 7. Open questions and assumptions (red-team flagged in `risks.md`)

The design table is parametric, but the following are **derived estimates** that need first-prototype measurements to harden:

- **Padauk K = 24,438** is from the workbook's material library, derived from textbook E and ρ values. Not measured on Tony's specific stock.
- **Curved-cantilever +2.5 %** correction is a starting estimate from cylinder-shell theory at small radii. The actual factor for our specific dome rise (0.75″ on Standard) is unmeasured.
- **Wall thickness** of 0.625″ is conventional but un-tuned — Helmholtz Q depends on wall stiffness.
- **Bowl-top joint type.** Three options compete (rabbet flush, lap step, cork gasket). Rabbet flush is the working assumption; the others are validation B/C plans if the rabbet leaks.
- **Slit kerf cap of 50 % of soundboard area** is a structural rule of thumb, not a measured failure threshold.
- **Effective neck length on V1 = soundboard thickness alone.** This ignores the air "plug" oscillating just below the slit. The end correction is small for tongue-drum kerfs (kerfs are slits, not circular ports), and we're absorbing the error into the 0.88-ratio safety margin. If `f_H` measures 5–10 % low on first prototype, this is the likely cause.

---

## 8. Cross-references

- **Workbook**: [`wood-shell-tongue-drum-design-table.xlsx`](wood-shell-tongue-drum-design-table.xlsx) — single sheet, 249 rows, 190 formulas. Blue cells are inputs; everything else recomputes.
- **Concept sheet**: [`concepts/round-body-variants_concept-sheet.png`](concepts/round-body-variants_concept-sheet.png) — visual layout of all twelve cells.
- **BOM, sourcing, cut list, validation**: see the four CSVs at repo root.
- **Risks**: see [`risks.md`](risks.md) for the red-team pass with verification tests attached.
- **Wolfram exploration**: see [`wolfram-starter.wl`](wolfram-starter.wl) for the 3-DOF coupled oscillator (tongue + shell + air cavity) starter.
- **Sister repos**: [`tongue-drum/`](https://github.com/tonykoop/tongue-drum) (rectangular-prism precursor) · [`steel-tongue-drum/`](https://github.com/tonykoop/steel-tongue-drum) (steel cantilever cousin) · [`ceramic-tongue-drum/`](https://github.com/tonykoop/ceramic-tongue-drum) (slip-cast cousin) · [`ashiko-drum-workshop/`](https://github.com/tonykoop/ashiko-drum-workshop) (segmented bowl reference) · [`conga/`](https://github.com/tonykoop/conga) (stave & segmented shell reference).
- **Catalog**: [`tonykoop/instrument-maker`](https://github.com/tonykoop/instrument-maker) — orchestrating skill and Master Catalog.

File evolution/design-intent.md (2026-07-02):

# Design Intent — wood-shell-tongue-drum rev A

- Master CAD: `cad/wood-shell-tongue-drum.scad` (sha256: d701a846f44329a595398b690165ab07ec964187416711c5692dd0064e37fa7a), driven by `wood-shell-tongue-drum-design-table.xlsx` (sha256: 411ed770bbc4f5b99388d1c6949b29f59cefa4d90490531f7d634721a3a819e8)
- Function: V1 Cylinder + Flat Top, Standard 16" — a slit-tongue idiophone with an enclosed wooden resonator (Black Walnut stave shell, Padauk soundboard). A two-DOF coupled oscillator: 11 A-Kurd cantilever tongues (flat-cantilever Euler-Bernoulli, `f = K·t/L^2`) coupled to a Helmholtz cavity (`f_H = (c/2pi)*sqrt(A_port/(V*L_neck))`) via the gu port, targeting `f_H/f_ding ∈ [0.80, 1.20]` (design.md §2, §4).
- Environment: indoor idiophone; struck tongues, seasonal wood movement affects the rabbet joint and cavity behavior (risks.md).
- Target qty: 1 (prototype, first of a 4-variant x 3-size family). Deadline: TBD. Budget/unit ceiling: TBD.

## Critical dimensions (carry tolerances)

| Feature | Nominal | Tolerance | Why critical | Source |
| --- | --- | --- | --- | --- |
| Shell OD / height | 16.00 in / 8.00 in | ± 0.020 in default | sets cavity volume for Helmholtz coupling | design.md §4 build table |
| Wall thickness (finished) | 0.625 in | after lathe truing, 0.625-0.75 in range | cavity volume, structural rigidity | design.md §4 / §5.15 |
| Soundboard thickness | 0.375 in (Padauk) | rabbet 0.005 in slip-fit | tongue stiffness (K=24,438 for Padauk), soundboard resonance | design.md §4 |
| Tongue lengths (11, A Kurd schedule) | 6.454 in (ding) down to 3.227 in | slot-cut, caliper-checked pre-glue-up | sets each tongue's pitch | design.md §4 tongue length schedule |
| Tongue position grid (r, theta) | zigzag-ascending, r ≤ 6.5 in | "derived estimates," refined by SolidWorks placement | ergonomic two-handed reach, ≥1.0 in wall clearance on 16in shell | drawing-brief.md Sheet 03 position grid |
| Gu port diameter | 2.5 in initial | tuned in shop via step-drill | primary Helmholtz tuning knob | design.md §4 (position not yet specified — TBD) |

## Incidental (free for DFM)

- Shell finish/patina, stave vs. segmented construction choice (aesthetic-equivalent per README "dual body-construction paths"), brand mark placement.

## Must-nots (DFM may never violate)

- Do not cut tongue slits before the CNC pocketing geometry (slit + tongue-base relief) is reviewed against drawing-brief.md/cnc/README.md — cut geometry is explicitly out of scope of the current CAD envelope.
- Gu port must be drilled LAST, deliberately undersized, then step-bored while measuring f_H in shop (design.md) — never pre-drilled to a fixed size.
- Do not treat the +2.5% domed-tongue length correction (V2/V4) as validated — it is a starting estimate pending Phase 1 calibration (design.md "Highest-risk unknowns" #1).
- Soundboard rabbet fit (0.005 in slip-fit) and gu port concentricity (±0.025 in) are load-bearing tolerances for tuning accuracy — do not loosen without re-deriving f_H sensitivity (design.md §5 tolerance table).

## Material intent

- Shell: Black Walnut, 4/4 stock, 16 staves at 11.25° miter.
- Soundboard: Padauk (K ≈ 24,438), 3/8 in.
- Acceptable subs: none recorded for the V1 Standard prototype (spec-first).
- Forbidden: none recorded.

## Stage status

Stage 0 intake complete 2026-07-01. Gate A (Alpha shop compile) NOT yet run — no concessions logged, nothing presented as shippable.

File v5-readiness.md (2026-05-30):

# V5 Readiness Notes - Wood Shell Tongue Drum

Current status: `L2 V5 build-packet candidate`.

Authority is limited to review and prototype planning until measurement closes the gates below. The repo contains useful packet material, a workbook, a hero SVG, print/capstone outputs, and planning folders, but it does not contain measured prototype evidence, calibrated CAD, fabrication DXF, or released G-code.

Do not describe this repo as build-ready, measured, validated, repeatable, or L3 until the Phase 1 prototype data is captured and folded back into the packet. Round 2 recovery did not add fabricated CAD geometry, DXF coordinates, or tuning frequencies.

## Authority Chain

| Artifact | Role | Authority posture |
| --- | --- | --- |
| `wood-shell-tongue-drum-design-table.xlsx` | parametric design source | `pending_measurement`; unmeasured design-table scaffold |
| `design.md` | governing model and first-prototype rationale | design intent and derived estimates |
| `family-spec.csv` | variant matrix | planning matrix; every row says no measured prototype data |
| `validation.csv` | target and measurement protocol | measurement plan; measured fields are empty |
| `drawings/00-hero-v1-standard.svg` | hero side-section preview | derived preview, not fabrication release |
| `concepts/round-body-variants_concept-sheet.png` | concept sheet | concept-only visual support |
| `cad/README.md` | CAD staging plan | CAD deferred until measurements |
| `cad/mcp-session-log.md` | external-tool provenance stub | records that no MCP/CAD authoring session exists yet |
| `cnc/README.md` | CNC and G-code staging plan | G-code deferred until measurements |
| `tuning-gates.md` | L1/L2 tuning gate surface | measurement plan; no added target frequencies |

## Measurement-Required Claims

- Padauk K constant for the specific stock.
- First tongue pitch and back-solved material correction.
- V1 Standard A Kurd tongue field tuning, including cents error and environment.
- Helmholtz cavity response, gu-port end correction, and coupling ratio.
- Shell rim flatness, wall thickness uniformity, and air seal.
- Slit kerf width, tongue Q/sustain, and stress-relief performance.
- Seasonal movement at the bowl-top rabbet joint.
- Player ergonomics for the 20 inch Floor Pouf size.

## V5 Blockers

| Gate | Needed evidence | Current status |
| --- | --- | --- |
| Phase 1 prototype | V1 Standard build with measured tongue/cavity data | missing |
| CAD authority | SolidWorks/STEP/STL derived from calibrated workbook | deferred |
| Fabrication DXF | tongue layout and fixture DXF tied to calibrated CAD/design table | deferred |
| G-code | machine-specific files generated from calibrated CAD/CAM | deferred |
| Visual authority register | concept/preview artifacts recorded as non-authority or pending measurement | added |
| MCP/CAD provenance | `cad/mcp-session-log.md` says whether external tools created artifacts | stubbed; no tool sessions |
| Explorer | root HTML dashboard for current gates | added |

## Promotion Rule

The current safe promotion is L2 only. L3 requires `validation.csv` and `validation-loop.csv` to contain Phase 1 measurements, then CAD/DXF/CNC files must be regenerated from the calibrated workbook and recorded in `visual-output-register.csv` with fabrication authority.

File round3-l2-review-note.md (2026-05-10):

# Round 3 L2 Review Note

This repo already contains a validator-clean root-mode packet. Round 3 keeps it
at L2 because the core coupled-resonator claims still need measured prototype
data:

- Padauk tongue K behavior for the actual stock.
- Helmholtz frequency after the real shell, gu port, and end correction exist.
- Tongue/cavity coupling strength and sustain.
- Finish and humidity movement after rest.

Acoustic basis: `instrument-maker-v4/references/new-instruments-v4.md` section
`Wood Shell Tongue Drum` defines the governing model as cantilever tongue plus
Helmholtz shell chamber and gives the 0.85 to 1.15 coupling target. The same
packet cites `references/acoustic-models.md` for cantilever and Helmholtz
formulas.

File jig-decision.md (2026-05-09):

# Jig Decision

## Decision

Use a staged jig package that matches the recommended first prototype:

1. A stave-bevel reference jig for the 16-stave cylinder shell.
2. A shell glue-up and lathe-truing support path that keeps the rim round and measurable.
3. A laser-cut tongue-layout overlay plus spoilboard hold-down template for the Padauk soundboard.
4. A gu-port logging card and optional three-pin dome flip jig for later V2/V4 work.

## Why

The first public-safe upgrade pass needs reviewable setup logic without pretending that finished CAM or calibrated CAD already exist. The jig set above keeps the V1 Standard build low-risk while still feeding measurements forward into the later dome and hemisphere variants.

## Required Fixtures

- Stave bevel jig referenced from the stave centerline so both bevels stay symmetric.
- MDF cylinder caul or equivalent glue-up support that keeps the shell round within the tolerance band in `validation.csv`.
- Soundboard spoilboard and hold-down clearance template that avoid tape or vacuum under moving tongues.
- Temporary measurement support that leaves the gu port and underside accessible during puff-test and tuning.

## Deferred Fixtures

- Three-pin dome flip jig becomes mandatory only after the V1 shell and flat-top tuning loop are measured.
- Hemisphere ring-stack centering fixtures are useful for V3/V4, but they are not the first blocker for close-ready packet quality.

## Rejected Options

- Publishing build-ready G-code before the first Padauk test cut and kerf check.
- Freehand port drilling without the measurement log card.
- Treating the dome multiplier as fixed before a single dome tongue is back-solved from measured pitch.

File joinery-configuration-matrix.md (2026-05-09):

# Joinery Configuration Matrix

Practical joinery comparison for tongue-drum shells and shell-to-top interfaces. This is a focused planning document for `tonykoop/instrument-maker#118`, using the wood-shell tongue drum family as the most relevant testbed.

## Scope

Tongue drums ask two different joinery questions:

1. How should the shell body itself be built?
2. How should the vibrating top or soundboard be captured without killing the acoustic seal or making service impossible?

The table below compares joinery types against those two jobs, not just generic woodworking aesthetics.

## Matrix

| Joint | Best fit in tongue-drum work | Tooling level | Strength | Airtight-seal potential | Serviceability | Curve / shell compatibility | Recommended use in this family | Notes |
| --- | --- | --- | --- | --- | --- | --- | --- | --- |
| Butt joint | Fast rectangular box shells, temporary prototypes, internal-block builds | low | low by itself | low unless backed up | medium | poor for curved shells | only for quick box-drone or sacrificial test bodies | Too dependent on fasteners or internal cleats to be a public-ready main shell strategy. |
| Rabbeted butt joint | Box shells, end-cap capture, shell-to-top seat | low to medium | medium | high when fit is controlled | medium | good for top capture, weak for curved wall segmentation | **primary top-capture strategy** for `wood-shell-tongue-drum` | Best balance of manufacturability and airtight seal for the soundboard interface. |
| Finger / box joint | Rectangular wooden tongue drums, laser/CNC flat-pack bodies | medium | high | medium | low | poor for round shells | best for `tongue-drum`, not for the round-body shell here | Excellent for orthogonal box bodies; awkward and visually noisy on stave cylinders. |
| Through dovetail | Premium rectangular shells, heirloom box builds | high | high | medium | low | poor for curved shells | showcase-only option for rectilinear tongue-drum variants | Strong and beautiful, but slower and less parameter-friendly than finger joints for repeated packet builds. |
| Sliding dovetail | Captured divider, rail, or removable ring in a straight-walled body | high | high | medium | medium | poor to medium | niche use for internal baffle or rail, not main shell closure | More relevant if a tongue drum gains an internal removable shelf or rail system. |
| Splined miter | Premium polygon shells, decorative rectangular shells, clean external corners | medium to high | medium to high | medium | low | medium for segmented polygon shells | secondary option for segmented shell experiments | Better visual polish than finger joints, but less forgiving than staves for a first round-body prototype. |
| Dowel / Domino / floating-tenon reinforced butt joint | Panel shells, ring laminations, hidden reinforcement in box or polygon bodies | medium | medium to high | medium | low | medium | useful reinforcement path for polygonal or faceted experimental shells | Good when you want cleaner exterior lines than finger joints but easier setup than dovetails. |
| Tongue-and-groove panel capture | Capturing a backer, removable panel, or floating non-vibrating panel | medium | medium | medium to high | high if designed removable | medium | useful for service panels, not the vibrating top in this family | Better for removable access or non-primary panels than for a tuned soundboard. |

## Read by shell type

| Shell type | Best joinery candidates | Why |
| --- | --- | --- |
| Rectangular wood tongue drum | finger / box joint, rabbeted butt, splined miter | Orthogonal panels reward repeatable edge joinery and easy clamping. |
| Stave cylinder | edge-beveled stave glue-up plus rabbeted top capture | The wall is really a many-sided coopered shell; the top joint is the separate load-bearing question. |
| Segmented bowl / hemisphere | ring stack or segmented shell plus rabbeted top capture | Bowl geometry wants ring/segment logic; the top still benefits from an airtight captured seat. |
| Experimental polygon shell | splined miter or floating-tenon reinforced butt | Clean external faces with moderate repeatability, if the maker wants a more faceted look. |

## Recommendation for `wood-shell-tongue-drum`

For the current family, keep the shell and top decisions separate:

- Shell body: stave cylinder for V1 and V2, segmented bowl or ring-stack for V3 and V4.
- Vibrating top capture: rabbeted butt-style seat at the rim remains the first-prototype default.

That split is why the packet keeps returning to the rabbet joint. The top joint has to do more than hold parts together; it has to preserve cavity seal, locate the soundboard repeatably, and survive tuning vibrations without adding a complicated service burden.

## Practical shortlist

If Tony wants one joinery path per tongue-drum family for first builds:

- `tongue-drum` rectangular family: finger / box joint
- `wood-shell-tongue-drum` round-body family: stave or segmented shell plus rabbeted top capture
- premium later experiment: splined-miter polygon shell or hidden floating-tenon shell

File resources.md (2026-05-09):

# Resources

## Local Packet Sources

- `wood-shell-tongue-drum-design-table.xlsx` - workbook source for the 4-variant x 3-size family.
- `design.md` - governing model, family matrix, and recommended prototype logic.
- `validation.csv` - predicted targets plus the measurement plan that retires the current unknowns.
- `drawing-brief.md` and `cnc/jig-and-template-plan.md` - manufacturable review surface before full CAD exists.

## Instrument-Maker References Used

- `instrument-maker/skills/v4/instrument-maker-v4/references/new-instruments-v4.md` - family definition for the wood shell tongue drum.
- `instrument-maker/skills/v4/instrument-maker-v4/references/acoustic-models.md` - cantilever and Helmholtz formulas plus empirical-correction guard rules.
- `instrument-maker/skills/v4/instrument-maker-v4/references/manufacturing-and-cnc.md` - router, lathe, fixture, and shop-planning guidance.
- `instrument-maker/skills/v4/instrument-maker-v4/references/sourcing-and-production.md` - BOM, RFQ, validation, and packet-language standards.
- `instrument-maker/skills/v4/instrument-maker-v4/references/solidworks-integration.md` - honest SolidWorks handoff expectations for when CAD becomes load-bearing.

## Sister Repos

- `tongue-drum` - canonical cantilever-idiophone reference and DoE tuning precedent.
- `steel-tongue-drum` - steel cantilever cousin with the same broad tuning workflow but different material constants.
- `ceramic-tongue-drum` - vessel-style cousin that shares the cavity-coupling logic while changing the material pipeline.
- `conga` and `ashiko-drum-workshop` - shell-construction references for stave and segmented drum bodies.

## Public-Safe Notes

- This repo is planning-grade documentation, not a claim of a measured or commercially proven product.
- Current Helmholtz ratios, dome multipliers, and K constants should be read as derived estimates until prototype data lands in `data/` and `validation.csv`.
- Supplier facts, prices, and stock should be re-checked at purchase time.

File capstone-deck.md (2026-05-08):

# Wood Shell Tongue Drum Capstone
- Public-ready design packet for a round-body wooden slit-tongue idiophone
- Repo: `wood-shell-tongue-drum`
- Refreshed: 2026-05-08

---

# Project Intent
- Build a reviewable public repo for a wood-shell tongue drum family before the first physical prototype.
- Stress idiophone tuning, Helmholtz coupling, CNC/laser planning, jig decisions, and measured validation.
- Recommended first build: V1 Cylinder + Flat Top, Standard 16 in, A Kurd, A3 ding.

---

# Why This Is A Strong Candidate
- It extends Tony's rectangular `tongue-drum` work into a round enclosed resonator.
- The first prototype is practical: 16 walnut staves, one Padauk soundboard disc, CNC tongue slits, step-drilled gu port.
- The later V2/V4 dome variants create a visible portfolio story after V1 calibrates the physics.

---

# Governing Model
- Tongues: fixed-free cantilever, `f = K * t / L^2`.
- Default soundboard: Padauk, `K = 24438`, 0.375 in thick on the Standard 16 in build.
- Cavity: Helmholtz resonator, `f_H = (c / 2pi) * sqrt(A_port / (V * L_neck))`.
- Target coupling: `0.80 <= f_H/f_ding <= 1.20`.

---

# Prototype Tuning
- Scale: A Kurd, 11 tongues from A3 through A5.
- A4 is the sanity check: if measured A4 misses by more than 5 cents, back-solve the actual Padauk K constant.
- Tongues are cut 0.030 in long, then tuned by tip filing while logging cents error.
- Success target: all tongues within +/- 5 cents after settling and finish.

---

# Helmholtz Coupling
- V1 Standard predicts `f_H = 194.6 Hz`, or `0.88 * A3 ding`.
- Opening the gu port raises `f_H`; a restrictor/liner or longer neck lowers it.
- V2 Standard is under-coupled at the 2.5 in preset, so its validation build treats port size as a measured variable.
- Every port diameter step gets logged in `validation.csv`.

---

# CNC And Laser Plan
- CNC: 1/8 in upcut spiral for tongue slits; 1/4 in compression for OD profile; 3/4 in ball-end for later dome surfacing.
- Laser templates: tongue overlay, vacuum/tape clearance map, stave labels, gu-port log card.
- Public review artifact: `cnc/jig-and-template-plan.md` explains fixture choices before G-code exists.
- G-code is intentionally deferred until V1 measurements calibrate the workbook and hold-down strategy.

---

# Jig Decisions
- Shell: 16-stave walnut cylinder with 11.25 degree bevels.
- Glue-up: MDF cylinder caul plus band clamp.
- Lathe: waste-block faceplate plus soft expansion plug.
- Soundboard: MDF spoilboard, laser-cut hold-down clearance template, CNC center datum.
- Dome variants: three-pin flip jig only after V1 validates the flat model.

---

# Manufacturing Packet
- `design.md`: model, variant matrix, recommended prototype, tongue schedule.
- `bom.csv`, `sourcing.csv`, `cut-list.csv`: materials, suppliers, rough/final stock.
- `assembly-manual.md`: seven-phase build sequence and tuning loop.
- `drawing-brief.md`: nine-sheet drawing target, including gu-port tuning progression.

---

# Validation Plan
- Pitch: Korg OT-120 or cents-resolution tuner for every tongue.
- Cavity: microphone + REW/Spectroid puff test at each gu-port step.
- Geometry: rim TIR, wall thickness, soundboard thickness, kerf width, port concentricity.
- Finish drift: re-measure A4 after oil/wax to catch finish bleed into kerfs.

---

# Risk Register
- Acoustic: domed-tongue multiplier and Helmholtz end correction are unmeasured.
- Structural: stave miter drift, rim leaks, and seasonal soundboard movement can reduce sustain.
- Ergonomic: Floor Pouf 20 in is a floor instrument, not a lap instrument.
- Fit/finish: chipped slit edges and oil bleed can move pitch by audible cents.

---

# Public Repo Readiness
- README, design sheet, CSVs, assembly manual, RFQ, risks, Wolfram starter, and site are present.
- Print packet PDF has been regenerated from the current sources.
- `validation-report.md` records the public-readiness pass and remaining human-owned work.
- Remaining blocker for full portfolio polish: physical prototype photos/audio and refreshed PPTX export when python-pptx is available.

---

# Next Build Step
- Cut the V1 Standard soundboard test in poplar or MDF.
- Measure kerf width and A4 predicted pitch behavior.
- Build the walnut shell, seal-test the rim, and step-drill the gu port while logging `f_H`.
- Feed measurements back into `validation.csv` before generating final CAD/G-code.

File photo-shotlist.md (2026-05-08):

# Photo Shot List — Wood Shell Tongue Drum

Generated: 2026-05-07

This shot list feeds the build-log site (`site/index.html`), the printable shop packet, and any future capstone-deck refresh. Real photographs replace SVG placeholders as builds complete. Until prototypes exist, the SVG drawings carry the visual weight of the documentation.

## Required hero and overview

| Shot ID  | Subject | Purpose | Status |
|---|---|---|---|
| HERO-001 | V1 Standard 16″ finished, 3/4 angle, on neutral backdrop | README hero, build-log site cover | Needed |
| HERO-002 | All four variants (V1–V4) at Standard 16″ in a row, soundboards facing camera | Family lineup; print packet cover | Needed (after Phase 4) |
| HERO-003 | Three-size ladder (Travel + Standard + Floor Pouf) of V1 only | Size-progression catalog shot | Needed (after Phase 5) |
| HERO-004 | V1 Standard in-hand with mallets, top-down | Scale and ergonomics | Needed |

## Construction process — V1 Standard (recommended first prototype)

| Shot ID | Subject | Purpose | Status |
|---|---|---|---|
| BUILD-101  | 16 stave blanks rough-cut, fanned out | Stock prep | Needed |
| BUILD-102  | Stave on tilting-arbor jig with 11.25° bevel cut | Miter setup | Needed |
| BUILD-103  | Staves taped flat, edges glued, ready to roll into cylinder | Stave glue-up Phase 1A.3 | Needed |
| BUILD-104  | Cylinder under three ratchet straps, squeeze-out beading | Glue-up clamp | Needed |
| BUILD-105  | Shell mounted on lathe, OD truing pass | Phase 1A.4 | Needed |
| BUILD-106  | Rim rabbet detail, ¼″ × ⅜″, dial indicator showing TIR | Critical-tolerance shot | Needed |
| BUILD-107  | Padauk soundboard disc on CNC, 1/8″ upcut spiral routing tongue slits | Phase 2A; cite slit kerf 0.125″ | Needed |
| BUILD-108  | Slit field complete on soundboard, top-down | Tongue layout reference | Needed |
| BUILD-109  | Rabbet joint dry-fit, soundboard half-engaged | Air-seal demonstration | Needed |
| BUILD-110  | Rabbet joint glued and clamped with cauls | Phase 3.1 | Needed |
| BUILD-111  | Gu-port step-drilling with mic + Korg in frame | Phase 4 — Helmholtz tuning | Needed |
| BUILD-112  | Tongue tuning with sanding bar, Korg OT-120 reading | Phase 5 — final tuning | Needed |

## Domed-top variant (V2 Standard) — additional shots

| Shot ID | Subject | Purpose | Status |
|---|---|---|---|
| DOME-201 | Poplar test blank with dome surfacing complete | De-risk shot | Needed |
| DOME-202 | Padauk dome blank in flip-jig, datum pins visible | CNC workholding | Needed |
| DOME-203 | Domed Padauk top, raking light to show 0.75″ rise | Profile reference | Needed |
| DOME-204 | First-tongue calibration cut, single tongue, before mass-cutting | Curved-cantilever validation | Needed |
| DOME-205 | Korg + tap test on the calibration tongue | Multiplier measurement | Needed |

## Hemisphere-bowl variants (V3, V4) — additional shots

| Shot ID | Subject | Purpose | Status |
|---|---|---|---|
| BOWL-301 | Graduated rings stacked but unglued, showing decreasing-dia profile  | Segmented bowl construction | Needed |
| BOWL-302 | Single ring closed and glued on lazy-susan jig | Per-ring closure | Needed |
| BOWL-303 | Stacked bowl on lathe, profile-truing pass | Lathe-truing the spherical exterior | Needed |
| BOWL-304 | Finished bowl rim with planar TIR check | Rim flatness verification | Needed |

## Detail and material shots

| Shot ID | Subject | Purpose | Status |
|---|---|---|---|
| DETAIL-401 | Stave miter close-up against digital protractor | 11.25° angle reference | Needed |
| DETAIL-402 | Tongue slit terminus geometry, extreme close-up | Slit corner relief | Needed |
| DETAIL-403 | Padauk grain detail on finished soundboard | Material identification | Needed |
| DETAIL-404 | Black Walnut shell exterior with Watco Danish Oil finish, raking | Finish quality | Needed |
| DETAIL-405 | Buna-N O-ring installed in finished gu port | Optional Hapi-style detail | Needed |

## Ergonomic / play context

| Shot ID | Subject | Purpose | Status |
|---|---|---|---|
| PLAY-501 | Player seated, V1 Standard on lap, two-mallet position | Lap-play ergonomics | Needed |
| PLAY-502 | Player at floor with Floor Pouf, both hands striking outer tongues | Floor-play reach | Needed |
| PLAY-503 | Side-by-side: player hands on Standard vs Floor Pouf | Size comparison for ergonomics | Needed |

## Audio reference

Not photo, but live audio recordings should accompany the build-log site:

| Track ID  | Subject | Purpose | Status |
|---|---|---|---|
| AUDIO-001 | Single ding strike, decay to silence | Sustain T60 measurement | Needed |
| AUDIO-002 | Full A Kurd scale played up | Tuning verification | Needed |
| AUDIO-003 | A vs B vs C vs D — same scale, four variants | Variant tonal comparison | Needed (after Phase 4) |
| AUDIO-004 | Cavity puff test recording with visible f_H peak | Helmholtz validation evidence | Needed |

## Status legend

- **Needed** — not yet captured; SVG or sketch placeholder until then.
- **Captured** — file path replaces this entry; image embedded in `site/index.html`.
- **Reshoot** — captured but rejected on quality / framing; queued.

## Photography conventions

- **Backdrop:** kraft butcher paper or off-white seamless for hero shots; raw shop bench OK for build-process shots.
- **Lighting:** one diffused softbox 45° camera-left for hero/detail; ambient shop light + tripod-stable shutter for process.
- **Format:** all photographs landscape 3:2 unless explicitly portrait. Hero is portrait 4:5.
- **Resolution:** 4000 × 6000 minimum at capture; export 2000 × 3000 web JPEG for the site.
- **Naming:** `images/<SHOT_ID>_<short-slug>.jpg` (e.g., `images/HERO-001_v1-std-finished.jpg`).

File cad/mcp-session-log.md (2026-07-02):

# MCP Session Log

Status: provenance stub for V5 L2 recovery.

No MCP, CAD, image, measurement, Illustrator, Photoshop, Blender, OpenSCAD, Fusion, SolidWorks, or physical measurement tool session was available during Round 2 recovery. No CAD geometry, DXF coordinates, tuning frequencies, renders, or measured outputs were generated in this pass.

| session_id | tool | input_authority | outputs | role | authority_result | review_status | notes |
| --- | --- | --- | --- | --- | --- | --- | --- |
| none-2026-05-29-r2 | none | `README.md`; `design.md`; `v5-readiness.md`; `validation.csv`; `validation-loop.csv`; `visual-output-register.csv`; V5 standard reference | none | provenance_stub | pending_measurement | unreviewed | Records absence of external-tool work; future CAD/render sessions must add rows before any artifact claims authority. |
| fable-v5-refresh-2026-07-01 | claude-code (Fable 5) + OpenSCAD CLI | design.md §4 build table, drawing-brief.md Sheet 03 position grid | cad/wood-shell-tongue-drum.scad | cad_authoring | pending_measurement | self_checked | Parametric shell + soundboard envelope, tongue position/length layout reference marks from the 11-tongue A Kurd schedule. Slit-routing cut geometry and gu port placement intentionally out of scope (no cut-path/position source). OpenSCAD render check: pass (openscad -o STL, exit 0). |
| fable-v5-refresh-2026-07-01 | claude-code (Fable 5) | wolfram/wood-shell-tongue-drum-wolfram-model.wl (pre-existing, merged via PR #8) | visual-output-register.csv | packet_refresh | derived_preview | unreviewed | Added missing register row (WL-002) for the pre-existing Wolfram model; source-only, not executed by this pass. |

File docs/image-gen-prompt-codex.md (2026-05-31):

# Wood Shell Tongue Drum Image-Gen Prompts

Concept visualization only; not fabrication authority. Do not infer tongue
lengths, port dimensions, joinery tolerances, or tuning from these prompts.

## Hero Prompt

Photorealistic 3/4 product photograph of a finished round-body wood shell tongue drum, the recommended first prototype: an ottoman-like black walnut stave cylinder with a flat padauk soundboard, a centered ding tongue and surrounding A Kurd style tongue field cut cleanly into the top, and a discreet gu port visible near the lower side or underside. The instrument should feel premium and handmade, with warm walnut staves, reddish padauk top, a crisp rabbeted rim, satin oil finish, and small rubber feet or a low stand for scale. Clean studio background, soft directional product lighting, 50mm lens, high detail, photorealistic.

## In-Context Prompt

Photorealistic scene of the wood shell tongue drum being played in a quiet woodworking studio: the round walnut body sits on a low bench or floor cushion while a player uses soft mallets on the padauk tongue field. Nearby are a tuner, sanding block, wood offcuts, and a small inspection mirror for the gu port, suggesting prototype measurement and tuning without showing labels. Natural window light, warm wood tones, believable hand spacing, calm intimate atmosphere.

## Detail / Macro Prompt

Photorealistic macro close-up of the padauk soundboard tongue field: clean CNC-routed slit tongues with smooth eased edges, a central ding tongue, alternating tongue shapes around the circular top, and the walnut shell rim just visible at the edge. Show fine wood grain, slight end-grain contrast inside the kerfs, a satin finish, and no pitch markings. High-detail macro, shallow depth of field.

## Negative / Avoid

No text, logos, watermarks, steel handpan dimples, impossible tongue cuts, extra mallets, distorted hands, fake note labels, or cutaway dimensions.

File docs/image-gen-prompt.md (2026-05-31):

# Image-Gen Prompts

Concept image only; not fabrication authority. Do not include cut-ready dimensions, hole locations, or toolpaths.

## Hero Prompt

A finished round-body wooden tongue drum standing on a clean neutral studio sweep, photographed at a 3/4 product-photography angle with a ~50mm lens. The body is a turned cylindrical shell with an ottoman silhouette — a stout, low drum roughly the proportions of a small footstool, built from richly figured Black Walnut staves whose vertical grain lines wrap the side wall, finished in a warm hand-rubbed oil-and-wax sheen. The flat circular soundboard cap is a contrasting glowing orange-red Padauk disc, seated flush into the shell rim. The signature feature reads instantly: a field of eleven slim slit-cut tongues routed into the soundboard, one larger central ding tongue surrounded by ten progressively shorter tongues fanned outward left and right in a zigzag-ascending arrangement, each tongue a clean narrow kerf in the wood face. A pair of soft mallets rests beside it for scale, conveying a tabletop / lap-sized instrument. Soft directional studio light rakes gently across the soundboard to catch the tongue slits and the wood grain. High detail, photorealistic, no text labels.

## In-Context Prompt

The same round walnut-and-Padauk tongue drum staged in a warm woodworker's studio, sitting on a workbench among soft natural window light, with a band-clamped stave glue-up, a lathe, and curls of shavings softly blurred in the background. A player's hands hover with mallets just above the orange-red Padauk soundboard, mid-strike on the tongue field, suggesting a calm seated lap-play session. Shallow depth of field isolates the drum, environmental storytelling of a small one-maker shop, golden ambient light. Concept visualization only.

## Detail Prompt

Macro close-up of the soundboard tongue field: the glowing orange-red Padauk top filling the frame, showing the narrow CNC-routed slit kerfs that define the cantilever tongues, the rounded slit-terminus relief at each tongue base, and the tight grain of the tonewood. The central ding tongue and the inner edges of the neighboring fanned tongues are visible, with the flush rabbet seam where the Padauk cap meets the dark walnut shell rim along one side. Raking side light skims across the surface to throw the slit edges into crisp relief and reveal fine surface texture. High detail, no measurements.

## Negative / Avoid

No text, logos, watermarks, or fake maker marks; no dimension callouts or measurement lines; no impossible mechanisms, metal tongues, or steel hand-pan dimpling; anatomically plausible hands if a player is shown.

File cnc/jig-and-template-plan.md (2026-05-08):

# Wood Shell Tongue Drum — Jig And Template Plan

This file makes the manufacturing choices reviewable before CAM exists. The V1 Standard 16 in prototype is deliberately a low-CAD build: flat soundboard, stave shell, laserable templates, and measurements that calibrate the later V2/V4 dome work.

## Decision Matrix

| Build feature | Recommended first-prototype choice | Why | Validation checkpoint |
|---|---|-----|---|
| Shell construction | 16-stave Black Walnut cylinder | Lowest piece count; matches ashiko/conga stave skills; easy to true on lathe | Dry-clamp 4-stave arc; full ring closes within 1/16 in before glue |
| Stave bevel jig | Tilting-arbor table-saw jig referenced from stave centerline | Keeps both bevels symmetric; avoids compounded miter drift | 11.25 deg +/- 0.1 deg per edge; ring closes without clamp force spikes |
| Glue-up form | MDF cylinder caul with band clamp | Stabilizes OD while preserving an open interior for squeeze-out cleanup | Shell remains round within +/- 0.030 in after cure |
| Lathe mount | Waste-block faceplate + soft expansion plug | Keeps shell supported without crushing the rim | Rim TIR <= 0.005 in after truing |
| Soundboard hold-down | MDF spoilboard + laser-cut vacuum/tape clearance template | Keeps tape/vacuum away from tongue free ends and slit kerfs | No tape under moving tongue regions; test pass clears template |
| Tongue routing | CNC 1/8 in upcut spiral, through-cut +0.030 in | Directly controls kerf, tongue length, and stress-relief radius | Kerf 0.125 in +/- 0.005 in on poplar test disc |
| Tongue layout verification | Laser-cut MDF overlay | Cheap check before cutting Padauk; catches radial crowding and rim collisions | Overlay confirms longest A3 tongue has rim clearance |
| Gu-port tuning | Step-drill from pilot while logging f_H at every 0.25 in | Port area is the Helmholtz knob; measured curve validates the model | Stop at 0.80 <= f_H/f_ding <= 1.20; record final diameter |
| V2/V4 dome flip | Three-pin flip jig | Needed only after V1 validates the flat model | Datum repeatability <= 0.010 in on poplar dome blank |

## Laser Outputs

| File to emit | Size | Material | Notes |
|---|---|---|---|
| `soundboard-tongue-overlay-v1-standard.dxf` | 16 in OD | 1/8 in MDF | Shows center datum, rim keep-out, all 11 tongue centerlines, slit endpoints |
| `vacuum-gasket-v1-standard.dxf` | 16 in OD | 1/16 in rubber or kraft template | Hold-down clearance around every tongue and the ding strike area |
| `stave-label-strip.svg` | 16 labels | paper / masking tape | Labels staves 01-16 in grain order before beveling |
| `gu-port-log-card.svg` | 4 x 6 in | cardstock | Port diameter, measured f_H, ratio, environment, action |

## CAM Readiness Gates

- The CNC setup sheet must name machine, controller/post, work coordinate origin, spoilboard strategy, and hold-down.
- Every toolpath must include tool ID, diameter, flute direction, RPM, feed, depth of cut, stepover, and final pass allowance.
- Run a poplar or MDF soundboard test before Padauk; measured slit kerf and A4 pitch prediction go into `validation.csv`.
- Do not publish G-code as build-ready until it has been dry-run above the spoilboard and the first cut photos exist.

## Public Review Notes

The repo is intentionally public-reviewable before final G-code: the review surface is the design table, cut list, fixture logic, drawing brief, and validation plan. G-code becomes public only after the V1 prototype confirms the K constant, Helmholtz end correction, and practical hold-down strategy.

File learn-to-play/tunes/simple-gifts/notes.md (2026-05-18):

# Notes: Simple Gifts (Wood-Shell Tongue Drum)

**Provenance:** Elder Joseph Brackett, Shaker hymn (1848). PD.
Copland's arrangement is NOT used.

**Range check:** E4–D5. The wood drum's warm tone suits the flowing, arching phrase shape.

**Practice tips:**
1. The wood shell creates a shorter sustain than steel — use clean attacks to compensate.
2. The arch shape (ascending then descending) benefits from slight crescendo going up,
   diminuendo coming down.
3. The Bb (b in K:F) will sound especially warm through the wood vessel.

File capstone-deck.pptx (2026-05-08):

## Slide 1

Wood Shell Tongue Drum Capstone

Musical instrument documentation capstone
Build packet: wood-shell-tongue-drum
Generated: 2026-05-07

Wood Shell Tongue Drum Capstone | Slide 1 of 12

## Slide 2

Project Intent

• **Owner:** Tony Koop · Heifer Zephyr Instruments
**Family:** Slit-tongue idiophone with enclosed wooden resonator (round-body)
**Members:** four geometric variants (V1–V4) × three size envelopes (Travel 12″, Standard 16″, Floor Pouf 20″)
**Status:** Design v1 — formulas parametric in `wood-shell-tongue-drum-design-table.xlsx`; no physical prototype yet
**Recommended first prototype:** **V1 Cylinder + Flat Top, Standard 16″, A Kurd**

Wood Shell Tongue Drum Capstone | Slide 2 of 12

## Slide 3

How To Use This Packet

• Start with design.md for intent and assumptions.
• Use bom.csv, sourcing.csv, and cut-list.csv before buying or cutting.
• Use drawing-brief.md and CAD/CNC folders before machining.
• Print the packet for shopping, shop work, and validation.

Wood Shell Tongue Drum Capstone | Slide 3 of 12

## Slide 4

File Map

• design.md: Project intent, catalog metadata, assumptions, and validation plan.
• bom.csv: Starter bill of materials with part categories, quantities, drawing refs, and notes.
• sourcing.csv: Supplier/search tracker with specs, price/date fields, lead time, substitutes, and risks.
• cut-list.csv: Rough/final stock sizes, material, grain/orientation, operations, yield, and offcuts.
• drawing-brief.md: Manufacturing drawing and technical product sketch brief.
• assembly-manual.md: Shop-facing sequence, tools, fixtures, safety, tuning, finishing, and maintenance notes.
• validation.csv: Target/measured values, tolerance, environment, result, and tuning/build action log.
• supplier-rfq.md: Supplier email/request-for-quote starter.

Wood Shell Tongue Drum Capstone | Slide 4 of 12

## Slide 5

Build Workflow

• Design and assumptions
• Source materials and hardware
• Prepare stock, fixtures, and CNC/laser/lathe setup
• Assemble, tune, finish, and validate

Wood Shell Tongue Drum Capstone | Slide 5 of 12

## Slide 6

Sourcing And BOM

• BOM gives part categories and drawing references.
• Sourcing tracks search terms, supplier candidates, price/date, lead time, substitutions.
• Visual BOM brief turns the parts list into a presentation-ready image board.

Wood Shell Tongue Drum Capstone | Slide 6 of 12

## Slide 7

Shop Packet

• Cut list for lumber/sheet/blank planning.
• Assembly manual for away-from-keyboard work.
• Validation sheet for measured dimensions, tuning, pass/fail checks.

Wood Shell Tongue Drum Capstone | Slide 7 of 12

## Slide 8

Drawings, CAD, CNC

• drawing-brief.md defines required views, dimensions, datums, sketch intent.
• cad/ holds models and design tables.
• cnc/ holds CAM, toolpaths, setup sheets, dry-run notes.
• drawings/ holds PDFs, SVGs, DXFs, drawing exports.

Wood Shell Tongue Drum Capstone | Slide 8 of 12

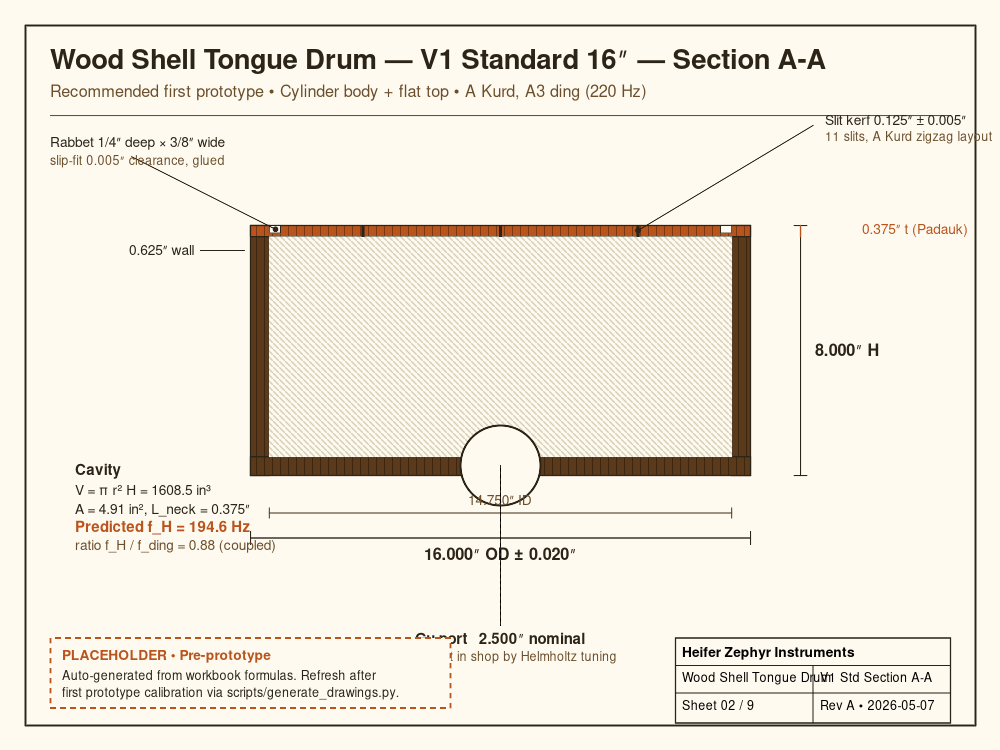
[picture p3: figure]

00-hero-v1-standard.png

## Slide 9

Images And Screenshots

• Add hero render/photo, visual BOM, shop screenshots, drawing previews, validation photos in images/.

Wood Shell Tongue Drum Capstone | Slide 9 of 12

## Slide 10

Validation Plan

• A4 = 440 Hz reference check.
• Tuning targets logged in validation.csv.
• Critical dimensions verified against design sheet and CAD.
• Photos and revision notes after each major step.

Wood Shell Tongue Drum Capstone | Slide 10 of 12

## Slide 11

Open Risks / Decisions

• TBDs in design sheet and BOM.
• Supplier price/availability not yet verified.
• Generated images marked as concept placeholders.
• Empirical corrections await measured prototype data.

Wood Shell Tongue Drum Capstone | Slide 11 of 12

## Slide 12

Next Actions

• Replace TBDs with measured/source-backed values.
• Verify live supplier price and availability before buying.
• Export final drawings and visual BOM images.
• Regenerate this deck and print packet after final edits.

Wood Shell Tongue Drum Capstone | Slide 12 of 12

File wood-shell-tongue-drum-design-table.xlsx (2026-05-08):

Wood Shell Tongue Drum — Hybrid: Wooden Bowl + Cantilever Tongues + Helmholtz Resonance
Combines segmented/stave bowl construction with flat tonewood soundboard · CNC-cut tongue slits · Enclosed chamber for Helmholtz sustain
SHARED DESIGN INPUTS
Shell Outer Diameter (in) | 12.0 | ≈ 30 cm; matches common tongue drum size
Shell Height / Depth (in) | 5.0 | Bowl depth below soundboard rim
Soundboard Thickness (in) | 0.375 | 3/8" — standard for wooden tongue drums
Soundboard Wood | Padauk
Soundboard K (cantilever) | 24438 | From material library below; Padauk = 24,438
Slit Kerf Width (in) | 0.125 | 1/8" CNC upcut spiral bit
Tongue Width (in) | 1.0 | Width affects volume, NOT pitch
Number of Tongues | 11
Scale | D Kurd
Gu Port Diameter (in) | 2.5 | Bottom of bowl; controls Helmholtz bass
Bowl Wood | Black Walnut | Bowl is NOT the soundboard — any attractive hardwood works
SOUNDBOARD MATERIAL LIBRARY — Cantilever K Values (from Tongue Drum sheet)
Wood | E (GPa) | ρ (kg/m³) | K (cantilever) | Tone Character | Rating
Padauk | 11 | 745 | 24438 | Warm, rich, excellent sustain | ★★★★★
Wenge | 15.8 | 870 | 27103 | Bright, punchy attack | ★★★★★
Cherry | 10.3 | 560 | 27275 | Balanced, sweet midrange | ★★★★
Black Walnut | 11.6 | 610 | 27734 | Full, mellow | ★★★★
Hard Maple | 12.6 | 705 | 26887 | Bright, long sustain | ★★★★
Mahogany | 10.1 | 590 | 26314 | Warm, full bass | ★★★★
Western Red Cedar | 7.7 | 370 | 29013 | Light, resonant, guitar-like | ★★★
HELMHOLTZ RESONANCE (Enclosed Bowl Chamber)
Chamber Volume (in³) |  | ≈ 2/3 × π × r² × h (hemisphere)
Port Area (in²)
Neck Length (in)
Helmholtz Freq (Hz) |  | ← Should be below the lowest tongue note for warm bass coupling
Nearest Note
TONGUE LENGTH CALCULATOR — Cantilever: f = K × t / L² → L = √(K × t / f)
Max Tongue Length (in) |  | ← radius minus 1" Ding clearance
# | Note | MIDI | Freq (Hz) | Tongue Length (in) | Length (mm) | Cut Length (in) | Position | Fits?
Ding | D3 | 50 |  |  |  |  | Center
1 | A3 | 57 |  |  |  |  | Center
2 | Bb3 | 58 |  |  |  |  | Center
3 | C4 | 60 |  |  |  |  | Center
4 | D4 | 62 |  |  |  |  | Center
5 | E4 | 64 |  |  |  |  | Center
6 | F4 | 65 |  |  |  |  | Center
7 | G4 | 67 |  |  |  |  | Center
8 | A4 | 69 |  |  |  |  | Center
9 | C5 | 72 |  |  |  |  | Center
10 | D5 | 74 |  |  |  |  | Center
FIT ANALYSIS — Tongue Length vs Shell Radius
Wood tongues are MUCH longer than steel at same pitch. D3 Kurd won't fit any practical shell. Solutions:
Config | D3 Tongue (in) | Max (in) | Tongues Fit | Verdict
D3 Kurd, 3/8" Padauk, 12" | 7.9 | 5 | 2026-04-11 | ❌
D3 Kurd, 3/8" Padauk, 16" | 7.9 | 7 | 2026-07-11 | ⚠️
D4 Kurd, 3/8" Padauk, 12" | 5.6 | 5 | 2026-10-11 | ✅
D4 Kurd, 3/8" Padauk, 14" | 5.6 | 6 | ALL 11 | ✅✅
D4 Kurd, 1/4" Cedar, 12" |  | 5 | ALL 11 | ✅✅
RECOMMENDED: D4 Kurd + 3/8" Padauk + 14" shell (all 11 fit with margin)
KEY INSIGHT: Wood K (~24k) vs Steel K (~32k) means wood tongues are ~30% longer at same pitch.
CONCEPT A: Segmented Bowl + Flat CNC Soundboard
Description | Segmented ring-stack bowl (like Ashiko/Conga) turned on lathe + flat tonewood disc glued on top with CNC-cut tongues
Bowl: Rings | 8 | rings
Bowl: Segments/Ring | 12
Bowl: Miter Angle
Bowl: Total Pieces
Bowl: Wall Thickness | 0.750 | After turning
Bowl: Ring Thickness | 0.750
Soundboard Disc |  | in diam flat disc; glue to bowl rim
Pros | Proven technique (you've built 3 segmented drums); beautiful multi-wood patterns; reliable cantilever physics on flat top
Cons | 96 segments to cut; lathe turning required; heavy
Tools | Table saw + miter sled (segments), wood lathe (turning), CNC router (tongue slits), drill press (Gu port)
CONCEPT B: Stave Shell + Flat CNC Soundboard
Description | Vertical staves ripped at miter angle, glued edge-to-edge around form, turned on lathe + flat tonewood soundboard
Staves: Count | 16
Staves: Miter Angle
Stave Width at Rim |  | in — widest point
Stave Height |  | in — bowl depth + 1" rim overshoot
Stave Thickness | 1.0 | in — turns down to ~3/4" wall
Pros | Only 16 pieces; continuous grain = better acoustics; faster than 96 segments; elegant look
Cons | Each stave must taper from rim width to narrow base; needs interior form or faceplate for turning
Tools | Table saw (rip staves at miter), wood lathe + faceplate, band clamp (glue-up), CNC router (tongue slits)
CONCEPT C: Full Sphere — CNC Carved Hemispheres with Curved Tongues
Description | Two hemispheres CNC-carved from thick glue-ups (split-blank style). Tongue slits CNC-cut or laser-cut into curved top shell.
Top Blank |  | in square glue-up, min 4" thick
Bottom Blank |  | in square glue-up, min 3" thick
CNC Strategy | 3D surfacing: 3/4" ball-end for exterior convex, flip-jig with datum pins for interior concave
Tongue Cutting | CNC with 1/8" upcut spiral on curved surface; OR laser-cut after flattening (experimental)
Wall Thickness | 3/8" at tongue fields; can taper thicker at rim for strength
Tuning Note | Cantilever formula assumes FLAT beam. Curved tongues vibrate differently — expect empirical tuning (file to pitch)
Pros | Closest to steel tongue drum appearance; fully enclosed sphere; most visually striking
Cons | MOST challenging: curved tongue physics are unpredictable; massive CNC time (3D surfacing both sides); waste material
Tools | CNC router (3D surfacing + flip jig + tongue slits), jointer/planer (glue-up prep), flexible epoxy (join halves)
Risk Level | ⚠️ HIGH — Prototype first. Use cheap wood (poplar) for initial test. Tuning will require extensive filing.
CONCEPT COMPARISON
 | A: Segmented | B: Stave | C: CNC Sphere
Difficulty | ★★☆ (proven) | ★★☆ (moderate) | ★★★ (experimental)
Piece Count | 96 segments + 1 disc | 16 staves + 1 disc | 2 blanks (glue-ups)
Lathe Required? | Yes (exterior) | Yes (exterior) | No (CNC only)
CNC Required? | Yes (tongue slits) | Yes (tongue slits) | Yes (everything)
Tuning Reliability | High (flat cantilever) | High (flat cantilever) | Low (curved — empirical)
Est. Material Cost | $40-80 | $30-60 | $60-120
Build Time | 12-16 hours | 8-12 hours | 20-30 hours
Visual Impact | Beautiful patterns | Clean grain | Most striking
Recommendation | ⭐ Start here | Great 2nd build | Ambitious prototype
DESIGN NOTES
1. Wood tongue drums need D4+ Ding on 12-14" shells. D3 Ding requires 16"+ shell or impractically thick soundboard.
2. Thicker soundboard = LONGER tongues (L grows with sqrt of t). Use thinner board with higher-K wood for compact design.
3. The enclosed bowl adds Helmholtz resonance your rectangular box tongue drums don't have — expect noticeably more sustain and bass warmth.
4. For Concepts A & B, the soundboard-to-bowl joint is critical. Use tight-fitting rabbet joint + wood glue for best acoustic transfer.
5. CNC tongue slit layout: use same radial pattern as steel tongue drums (zigzag ascending). Program in SolidWorks parametric table.
6. Gu port: drill through thickest part of bowl bottom. Fit with rubber O-ring (same as Handpan sheet).
7. Concept C: If curved tongues don't produce reliable pitches, consider hybrid — CNC sphere with a FLAT inset panel for tongues.
8. The bowl acts as a parabolic reflector — sound projects upward through the tongue slits. Player hears clear attack; audience hears full resonance.
9. Weight: segmented bowl ~3-5 lbs + soundboard ~1 lb = total 4-6 lbs. Stave = lighter. CNC sphere = heaviest.
10. This is an ORIGINAL DESIGN — no commercial wood shell tongue drums exist at this level. Document everything for your portfolio.
WOLFRAM CLOUD NOTEBOOK SPEC — WOOD SHELL TONGUE DRUM
Hybrid: wooden cylindrical shell + steel tongue plate top — combines wood resonance with steel tongue clarity.
§1 — Origin & Etymology
Hybrid design: combines steel tongue drum (Hapi-style, ~2007) with stave-built wooden shell. Original/contemporary maker scene.
Wolfram items: TimelinePlot[{ancient log drums, 2007 Hapi, 2010s artisan hybrids}].
§2 — Physics
Tongues: steel cantilever, f = K·t/L² with K_steel >> K_wood (steel ~6× higher K). Shorter tongues for same pitch as wood.
Wood shell: resonant cylinder + Helmholtz cavity. Adds warmth, sustain, bass.
Coupling between steel tongue and wood shell: steel modes drive shell modes through clamped boundary.
Wolfram functions: NDEigensystem cantilever steel; NDSolve cylinder modes; cross-spectrum analysis.
§3 — Geometry & Construction
Shell: stave-built or segmented cylinder (similar to ashiko/conga construction but smaller).
Steel top plate with cut tongues bolted/glued onto shell. Plate steel ~2–3 mm thick.
Wolfram items: Manipulate plate thickness + tongue lengths + shell dims → frequencies.
§4 — Animations
Tongue mode Animate on flat steel plate.
Shell-cavity coupling visualization: see how plate vibration drives air column inside shell.
§5 — Executable Cells
kSteel := (1.875^2/(2 π)) Sqrt[200 10^9 /(12·7850)] / 0.0254
fTongueSteel[t_,L_]:=kSteel t / L^2
fShellHelm[A_,V_,Lneck_]:=(c/(2 π)) Sqrt[A/(V Lneck)]
§6 — Wolfram Functions
NDEigensystem, NDSolve, Manipulate, Animate, Periodogram, CloudDeploy, FormFunction.
WOLFRAM EXPLORATIONS — WOOD SHELL TONGUE DRUM
Roadmap-inspired notebook ideas mapped to this instrument.
Coupled physics
→ Helmholtz + Tongue Coupling + Shell Modes (roadmap)
3-DOF coupled oscillator: steel tongue + wood shell + air cavity. Eigenvalue split shows how the wood shell adds a third mode that boosts sustain.
Compare to all-steel tongue drum (Steel Tongue Drum sheet) — same scale, different shell material; which is more sustained?
Design optimization
→ Optimal Shell Size Finder (roadmap: NMinimize)
Given pentatonic scale + steel plate K, find min shell diameter that fits all tongues + leaves room for bolt pattern.
Sound synthesis
AudioGenerator: synthesize wood-shelled vs steel-shelled vs ceramic-shelled tongue drums for the same scale; spectrogram comparison.
ROUND-BODY VARIANT MATRIX — Cylinder × Hemisphere × Flat × Dome × Three Sizes
Extends Concepts A/B/C above with explicit round-body design candidates. Four geometric variants × three size presets = 12 design candidates. Each variant carries its own chamber-volume formula, Helmholtz coupling, and tongue-fit verdict. All values are formulas tied to the SIZE PRESETS block below — change a preset cell and the entire matrix updates.
§B. SIZE PRESETS
Parameter | Travel (12") | Standard (16") | Floor Pouf (20") | Notes
Outer Diameter (in) | 12 | 16 | 20 | Travel matches steel-pan size; Standard ≈ Moroccan ottoman; Floor Pouf ≈ tall lounge piece
Shell Height (in) | 5 | 8 | 10 | Cylinder body height (rim to floor)
Soundboard Thickness (in) | 0.250 | 0.375 | 0.500 | Travel 12 in uses 1/4 in for fit; Standard 16 in 3/8 in; Floor Pouf 20 in 1/2 in for stiffness across span
Soundboard Wood | Padauk | Padauk | Padauk | Cedar (K≈29,013) shortens tongues — use on tight-fit configs
Cantilever K (from library) | 24438 | 24438 | 24438 | Padauk K = 24,438 (see library row 19). Update if wood changes.
Slit Kerf Width (in) | 0.125 | 0.125 | 0.125 | 1/8" CNC upcut spiral — same on all sizes
Tongue Width (in) | 1.000 | 1.250 | 1.500 | Wider tongues = more volume; pitch unchanged
Number of Tongues | 11 | 11 | 11 | Standard 11-note (1 ding + 10 chromatic above) on all sizes
Scale | D Kurd | A Kurd | D Kurd | Match scale to ding fitness — see Variant blocks below
Target Ding Note | D4 | A3 | D3 | Anchor pitch; 12" too small for D3 in wood
Ding MIDI # | 62 | 57 | 50 | D4=62, A3=57, D3=50
Ding Frequency (Hz) |  |  |  | Computed from MIDI #
Bowl/Shell Wood | Black Walnut | Black Walnut | Black Walnut | Bowl is structural — pick attractive hardwood
Gu Port Diameter (in) | 2.000 | 2.500 | 3.000 | Bottom port. Larger Ø → higher Helmholtz freq; tune to lowest tongue.
Dome Rise (in, top variants) | 0.500 | 0.750 | 1.000 | Crown height for Variants 2 & 4. ≈ 4–6% of diameter.
Min Tongue Length Cap (in) |  |  |  | Radial fit cap: radius − 1" Ding-area clearance
§C. VARIANT 1 — Ottoman Cylinder, Flat Top
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

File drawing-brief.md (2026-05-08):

# Drawing Brief — Wood Shell Tongue Drum

The `drawings/` folder ships dimensioned SVGs for the matrix. Each SVG follows Heifer Zephyr's standard title block (lower-right) with: drawing name, sheet number, scale, units, project (Wood Shell Tongue Drum), date, revision, drafter (Tony Koop). All dimensions in inches unless noted; metric equivalents in brackets where helpful.

## Required drawings

| File | Sheet | Title | Notes |
|---|---|---|---|
| `01-variant-matrix.svg` | 1/9 | Variant Matrix V1–V4 × Three Sizes (top-down + side profiles) | Twelve-cell layout matching `concepts/round-body-variants_concept-sheet.png` with overlaid critical dims |
| `02-v1-standard-side-section.svg` | 2/9 | V1 Standard 16″ — Side Section A-A | Recommended first prototype. Shell, soundboard, rabbet joint, cavity, gu port |
| `03-v1-standard-tongue-layout.svg` | 3/9 | V1 Standard 16″ — Tongue Field (A Kurd 11-note) | Top-down soundboard view. Slit centerlines, lengths, position numbering |
| `04-shell-stave-template.svg` | 4/9 | Stave Template — All Sizes (full-size cutting layout) | One stave per size; bevel callouts at 11.25°; centerline marked |
| `05-shell-segment-template.svg` | 5/9 | Segment Template — All Sizes (alt body construction) | 15° miter, 12-per-ring; 8 rings on Std, 6 on Travel, 10 on Floor |
| `06-rabbet-joint-detail.svg` | 6/9 | Bowl-Top Rabbet Joint — Section B-B (3× scale) | ¼″ × ⅜″ rabbet; soundboard slip-fit; glue line; air-seal callout |
| `07-dome-toolpath.svg` | 7/9 | V2/V4 Dome Surfacing — CNC Toolpath Schematic | Convex top + concave bottom; 0.05″ stepover; flip-jig datum pins |
| `08-bowl-segment-stack.svg` | 8/9 | V3/V4 Hemisphere Bowl — Ring Stack Section | 8 rings of decreasing dia; lathe-true profile overlay |
| `09-gu-port-tuning-progression.svg` | 9/9 | Gu Port Tuning — Step-Drill Progression | 0.25″ pilot → step increments → final size; f_H expected at each step |

## Drawing conventions

- **Datums:** shell bottom plane = primary horizontal datum (Z=0); axis of revolution = primary vertical datum.
- **Tolerances:** ± 0.020″ default; tighter where called out (rim flatness ± 0.005″, slit kerf width ± 0.005″, miter angle ± 0.1°).
- **Cross-section hatching:** oak-grain pattern at 45° for wood; cross-hatch at 90° for void/cavity.
- **Title block size:** 4″ × 1.5″ at 1:1 scale.
- **Critical dimensions:** bold, with leader lines pointing to the dimensioned feature. Helmholtz-driving dimensions (cavity volume parameters) are double-boxed.
- **Material color cues** (when polychrome): Walnut = warm brown fill, Maple = pale cream, Cherry = pink-brown, Padauk = orange-red. Used in sheet 5 segment-stack diagrams for the diamond pattern.

## Critical dimensions (must appear on the drawings)

| Dimension | Drawing | Value (Standard 16″ V1) | Tolerance |
|---|---|---|---|
| Shell OD | 02 | 16.000″ | ± 0.020″ |
| Shell ID | 02 | 14.750″ | ± 0.030″ |
| Shell wall thickness | 02 | 0.625″ | ± 0.030″ |
| Shell height | 02 | 8.000″ | ± 0.030″ |
| Soundboard OD | 02, 03  | 16.000″ | ± 0.010″ |
| Soundboard thickness | 02, 03  | 0.375″ | ± 0.005″ |
| Rabbet depth | 02, 06  | 0.250″ | ± 0.005″ |
| Rabbet width | 02, 06  | 0.375″ | ± 0.005″ |
| Tongue length (ding A3) | 03 | 6.454″ | + 0.030″ initial |
| Tongue width | 03 | 1.250″ | ± 0.020″ |
| Slit kerf width | 03 | 0.125″ | ± 0.005″ |
| Gu port diameter (final) | 02, 09  | 2.500″ nominal | tuned in shop |
| Stave miter angle | 04 | 11.25° | ± 0.1° |

## Sheet 03 — tongue layout details

The 11-tongue A Kurd field uses a **zigzag-ascending** pattern: ding centered, then tongues 1, 2, 3, … alternating left and right at progressively greater radii from the ding. This matches steel-tongue-drum convention and gives the player an ergonomic two-handed reach.

Position grid (radial coords, ding = origin):

| # | Note | r (in from ding centerline) | θ (deg) | length (in) |
|---|---|---|---|---|
| Ding | A3 | 0 | — | 6.454 |
| 1 | E4 | 4.0 | 60 | 5.273 |
| 2 | F4 | 4.0 | -60 | 5.123 |
| 3 | G4 | 5.5 | 90 | 4.835 |
| 4 | A4 | 5.5 | -90 | 4.564 |
| 5 | B4 | 6.5 | 120 | 4.308 |
| 6 | C5 | 6.5 | -120 | 4.185 |
| 7 | D5 | 6.0 | 30 | 3.950 |
| 8 | E5 | 6.0 | -30 | 3.728 |
| 9 | G5 | 6.5 | 150 | 3.419 |
| 10 | A5 | 6.5 | -150 | 3.227 |

(These radial coords are derived estimates for the layout drawing; SolidWorks parametric placement against shell radius will refine them. The radii are kept ≤ 6.5″ to leave wall clearance ≥ 1.0″ on the 16″ shell.)

## Status

These SVG files are listed in this brief as the *intended* drawing set. The repo currently ships the brief and the source workbook; SVGs are emitted by `scripts/generate_drawings.py` (in the parent `instrument-maker` skill) reading the workbook as its parametric source. Per the v4 deliverable list, drawings are auto-generated and refreshed when the workbook changes — they are not hand-drawn artifacts.

A placeholder hero drawing — `drawings/00-hero-v1-standard.svg` — ships in this repo at first commit so cross-references resolve. It is replaced in production by sheet 02 above.

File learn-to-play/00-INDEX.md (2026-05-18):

# Wood-Shell Tongue Drum — Starter Songbook

Your wood-shell tongue drum uses a **Ding** center note (D) with tongue fields arranged
around a resonating wood vessel. Size variants:
- **Travel** (12" OD): D4 ding
- **Standard** (16" OD): A3 ding
- **Floor Pouf** (20" OD): D3 ding

This songbook is written for the **Standard** tuning (A3 ding). If you built a different
size, transpose the exercises to match your ding note.

## Recommended scale (D natural minor, A3 ding)
A3 — B3 — C4 — D4 — E4 — F4 — G4 — A4 — and the D ding

The tongue fields follow a D natural minor (Aeolian) arrangement, providing
a rich, warm tone with the wooden shell adding natural warmth.

## Difficulty key
- ★☆☆ — Beginner: ding + nearby fields, slow patterns
- ★★☆ — Intermediate: cross-tongue patterns, wider range
- ★★★ — Advanced: full range, complex rhythmic patterns

## Tunes in this songbook
1. `tunes/ding-patterns/` ★☆☆ — Ding drone exercises and meditation patterns
2. `tunes/forest-walk/` ★★☆ — Forest Walk (original, D minor)
3. `tunes/scarborough-fair/` ★★☆ — Scarborough Fair (D dorian adaptation)
4. `tunes/simple-gifts/` ★★☆ — Simple Gifts (F major, Brackett 1848)
5. `tunes/river-reed-waltz/` ★★★ — River Reed Waltz (original, 3/4, D minor)

## Wood tone note
The wood shell produces a warmer, more muted tone than steel tongue drums.
Let each note bloom fully before moving to the next — the sustain is shorter
than steel, so clean attacks matter more.

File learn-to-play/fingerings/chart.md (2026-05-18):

# Wood-Shell Tongue Drum Layout Reference

The tongue fields are arranged in a circular pattern on the drum head.
The exact layout depends on the builder's configuration, but a typical arrangement:

```
Standard 16" (A3 ding) suggested layout:

        Top (highest fields)
            ┌─────────────┐
          A4            G4
        ┌──────────────────┐
       F4                 E4
        └──────────────────┘
          D4            C4
            └─────────────┘
              Bb3   B3
                ┌─────┐
                │ A3  │  ← DING (center, bottom dome)
                └─────┘

Travel (12", D4 ding): All fields shifted up a fourth
Floor Pouf (20", D3 ding): All fields shifted down an octave
```

## Playing technique (wood vs. steel)
- **Softer mallets work better** on wood than on steel — the wood absorbs harder impacts
  without producing the bright ring of steel.
- **Lower striking force** needed — wood resonates more readily than steel drums.
- **Shorter sustain** — wood damps faster; play each note at the moment you want it heard.
- The ding dome (center) is struck more gently than the tongue fields — a glancing blow
  rather than a full mallet stroke.

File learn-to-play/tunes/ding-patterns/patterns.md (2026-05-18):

# Ding Drone Patterns ★☆☆

Use the ding as a sustained anchor point. Strike it, then add tongue-field notes above it.

## Pattern 1: Ding + fifth (for A3 ding, the fifth is E4)
```
Strike: A (ding)
Wait 2 beats
Strike: E
Wait 2 beats
Repeat
```

## Pattern 2: Ding + scale walk
```
Strike: A (ding)
Then slowly walk up: B C D E F G A
Pause at each note to hear the ding's resonance blend with it
Walk back down
```

## Pattern 3: Call and response
Strike the ding (A3). Listen. Then answer with a single higher note.
Let the ding fade before answering. This is meditation practice, not rhythm.

**Tip:** The ding is not just the lowest note — it is the spiritual anchor of the drum.
In handpan tradition, you return to the ding after each phrase. Use the same concept here.

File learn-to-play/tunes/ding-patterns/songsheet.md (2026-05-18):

# Ding Drone Patterns — Songsheet

**Tempo:** Free  **Meter:** Free  **Difficulty:** ★☆☆

## Three meditative patterns
1. Ding → 5th (A→E): strike ding, wait, play E. Repeat 8×.
2. Ding → scale walk: ding + ascending D minor scale up and down.
3. Call and response: ding "asks," single high note "answers."

**Duration:** 5–10 minutes (as long as feels right)

These patterns are not tunes — they are listening exercises.
The goal is to hear the wood vessel resonate, not to play a melody.

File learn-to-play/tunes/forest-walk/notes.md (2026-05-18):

# Notes: Forest Walk

**Composition:** Original tune written for the wood-shell tongue drum songbook.
MIT licensed — part of the Heifer Zephyr collection.
Designed for A3 ding (Standard 16" model); adapt if using Travel or Floor Pouf sizes.

**Range check:** A3 (ding)–E5 (high field). Uses the full range of the Standard model.

**Practice tips:**
1. Begin alone with the ding pickup — establish the tonal center before the melody starts.
2. Each 4-bar phrase is self-contained: learn them individually before connecting.
3. The D minor arpeggio in phrase 4 (A D F A) can be played as block chords for a final flourish.

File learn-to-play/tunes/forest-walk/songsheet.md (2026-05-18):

# Forest Walk — Songsheet

**Key:** D natural minor  **Tempo:** ♩= 76  **Meter:** 4/4  **Difficulty:** ★★☆
**Range:** A3–E5  **License:** MIT (original — Heifer Zephyr)

## Music
```
X:2 T:Forest Walk M:4/4 L:1/4 Q:1/4=76 K:Dmin
A, | A, C D E | F2 E D | C D E F | D4 |
E F G A | G2 F E | D E F G | A4 |
A c d e | d2 c A | G F E D | A,4 |
A, | A, D F A | c2 A F | D E F D | A,4 |
```

## Character
Four phrases that gradually ascend and return. The opening A3 ding pickup sets a grounded
pace; each phrase rises a step higher before returning to earth. The final phrase is
a D minor arpeggio (A D F A) that resolves back to the ding.

## Notes
- The pickup A3 (A,) is the ding — start with a single confident ding stroke.
- The gradual ascent (phrases 1→3) builds energy; phrase 4 is the resolution.
- At ♩= 76, this should feel like a moderate walking pace — unhurried but forward.

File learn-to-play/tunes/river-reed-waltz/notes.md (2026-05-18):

# Notes: River Reed Waltz

**Composition:** Original waltz for the wood-shell tongue drum, MIT licensed — Heifer Zephyr.
Designed for A3 ding (Standard 16" model). The 3/4 meter suits the gentle rocking of the
wooden vessel's natural sustain.

**Range check:** A3–D5. Full range of the Standard model.

**Practice tips:**
1. The waltz should sway — count 1-2-3 with a slightly emphasized 1 (downbeat).
2. Each phrase ends with a long dotted half note — use this as your breathing point.
3. The transition from phrase 3 (high) to phrase 4 (descending) is the emotional center —
   don't rush the G6 in bar 12; let the audience settle before the descent.

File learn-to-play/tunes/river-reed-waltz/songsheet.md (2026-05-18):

# River Reed Waltz — Songsheet

**Key:** D Aeolian (natural minor)  **Tempo:** ♩= 84  **Meter:** 3/4  **Difficulty:** ★★★
**Range:** A3–D5  **License:** MIT (original — Heifer Zephyr)

## Music
```
X:5 T:River Reed Waltz M:3/4 L:1/8 Q:1/4=84 K:Dmin
A,2 | D4 F2 | A4 G2 | F4 E2 | D6 |
E4 F2 | G4 A2 | c4 A2 | G6 |
A4 c2 | d4 c2 | A4 G2 | F6 |
G4 F2 | E4 D2 | A,4 D2 | D6 |
```

## Character
A gentle waltz in three: rise, peak, resolve. The opening A3 ding provides the bass anchor;
the melody ascends to D5 at the emotional peak, then spirals back to D below.
The 3/4 waltz suits the wood drum's natural lilt and sustain.

## Notes
- Pickup: two-eighth-note A3 (ding) before bar 1 — a gentle greeting.
- The dotted half notes (D6, G6, F6) = 3 beats; let them ring through the full waltz count.
- The "peak" phrase (bars 9–12): A→C→D→C→A→G — the highest point of the piece.

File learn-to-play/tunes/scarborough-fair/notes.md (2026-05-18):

# Notes: Scarborough Fair (Adaptation)

**Provenance:** Traditional English ballad, PD. This is an adaptation for D Aeolian —
the traditional melody is D dorian (with B natural, not Bb). The Bb substitution creates
a subtly different modal character while keeping the melody recognizable.

**Range check:** C4–D5. Well within the Standard model's range.

**Practice tips:**
1. The 3/4 waltz pulse should breathe — never rush the spaces between notes.
2. The pickup A (bar 1) enters gently — don't overpower the opening.
3. The Bb substitution (for dorian B natural) is heard most clearly in bars 2 and 10.

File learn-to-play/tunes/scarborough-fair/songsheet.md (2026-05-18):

# Scarborough Fair — Songsheet (Wood-Shell Tongue Drum)

**Key:** D natural minor  **Tempo:** ♩= 72  **Meter:** 3/4  **Difficulty:** ★★☆
**Range:** C4–D5  **Source:** Traditional English, PD

## Music
```
X:3 T:Scarborough Fair (D Aeolian) M:3/4 L:1/4 Q:1/4=72 K:Dmin
A | d A F | D3/2 E/ F | E2 C | D3 |
F G A | c2 A | G2 F | A3 |
(repeat for each verse)
```

## Adaptation note
The traditional Scarborough Fair is in D dorian (with B natural). This arrangement
adapts it to D natural minor (with Bb where B would appear), which fits the D Aeolian
wood tongue drum. The modal shift makes the tune slightly darker and more melancholic —
appropriate for the instrument's warm wooden tone.

**Provenance:** Traditional English ballad, public domain. Freshly arranged for D Aeolian —
no Simon & Garfunkel arrangement rights used.

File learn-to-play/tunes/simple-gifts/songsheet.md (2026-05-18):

# Simple Gifts — Songsheet (Wood-Shell Tongue Drum)

**Key:** F major  **Tempo:** ♩= 84  **Meter:** 4/4  **Difficulty:** ★★☆
**Range:** E4–D5  **Source:** Elder Joseph Brackett, Shaker hymn (1848), PD

## Music
```
X:4 T:Simple Gifts M:4/4 L:1/8 Q:1/4=84 K:F
f4 f2 g2 | a4 f4 | a4 b2 c'2 | d'8 |
d'2 c'2 a2 c'2 | d'4 f4 | c'4 a2 f2 | g8 |
(Bb = b in K:F)
```

## Notes
- F major shares all notes with D natural minor — perfectly suited to this drum.
- The warm, woody tone of the instrument suits the simple, humble character of this Shaker hymn.
- The tied final note (f8-) should bloom for 4 full beats.

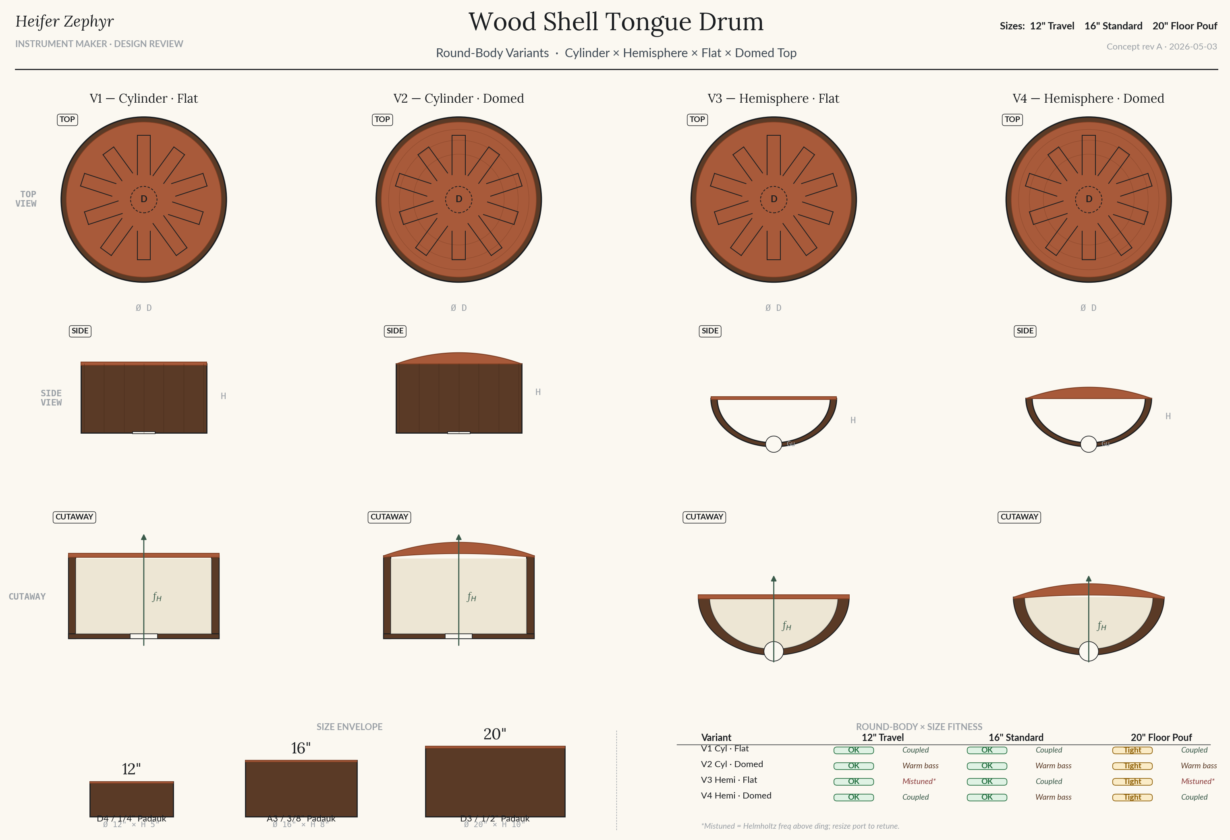
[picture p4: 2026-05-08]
concepts/round-body-variants_concept-sheet.png

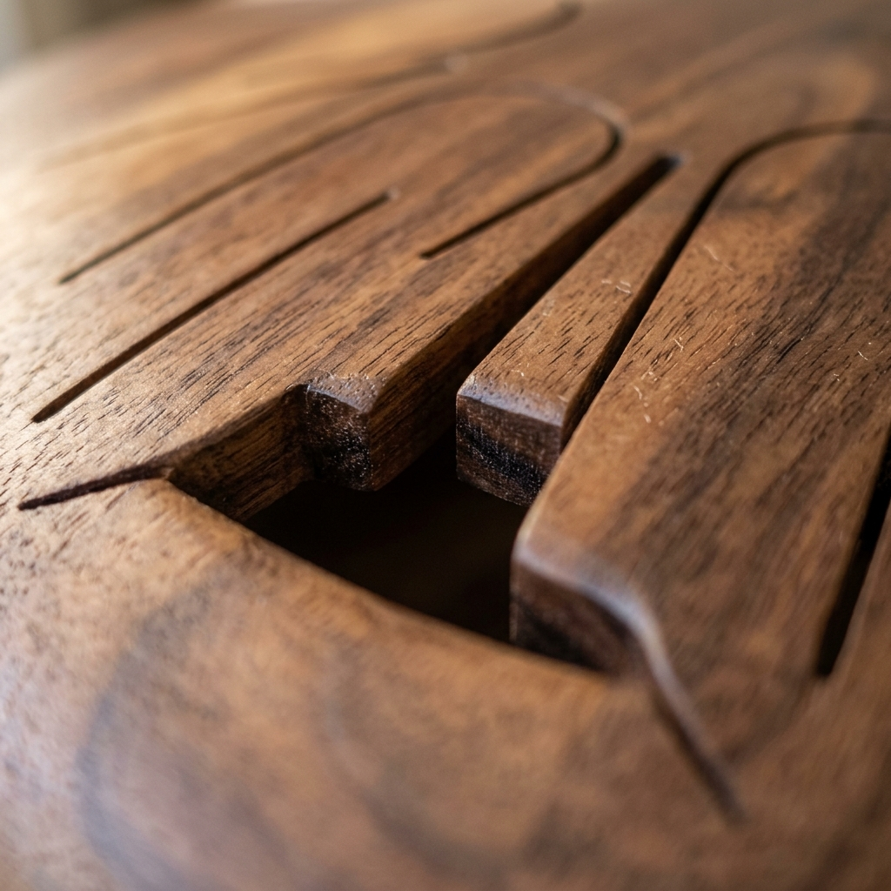
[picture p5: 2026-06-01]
images/macro/tongue-field.png

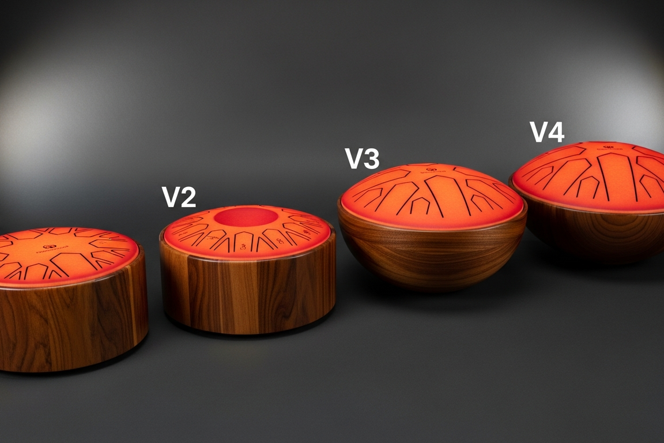
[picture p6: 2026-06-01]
images/family-group.png

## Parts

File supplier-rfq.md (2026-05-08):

# Supplier RFQ — Wood Shell Tongue Drum (Q2 2026 batch)

Heifer Zephyr Instruments is producing a wood shell tongue drum series across four manufacturing variants (V1–V4) and three sizes (Travel 12″, Standard 16″, Floor Pouf 20″). The recommended first prototype is **V1 Cylinder + Flat Top, Standard 16″** — that build is the priority for this RFQ. Variants V2–V4 are queued for sequential phases and should be quoted alongside but not necessarily shipped together.

Verified pricing date for all line items: **2026-05-07**. All prices are starting-point estimates; supplier confirmation requested before commit.

## Lumber

| Need | Quantity (per drum) | Specification |
|---|---|---|
| Black Walnut, 4/4, S2S, FAS | ~3 BdFt (Standard 16″) | Edge-jointable for stave glue-up; clear grain |
| Black Walnut, 4/4, S2S, FAS | ~5 BdFt (segmented bowl) | Bulk segment grade; 12-segment ring stack |
| Padauk, 4/4 or 1/2, S4S | ~1 BdFt | Soundboard thickness controls tongue length — hold 3/8″ ± 1/64″ on Standard. Quartersawn preferred for bend stability. |
| Padauk, 4/4 boards (3 ea, glue-up) | ~3 BdFt (V2/V4 dome only)  | For glue-laminated dome blank; 1.5″ total thickness |
| Western Red Cedar, 1/2 quartersawn | ~1 BdFt (Floor Pouf alt) | Soundboard alternate for D3 ding fit on Floor Pouf 20″ |
| Poplar, 1× boards | ~3 BdFt (V2/V4 prototype)  | Cheap test stock for dome surfacing rehearsal |

**Preferred suppliers:** Bell Forest Products (primary), Cook Woods (segment blanks). Local pickup acceptable if equivalent grade.

## Tooling

For shop and CNC tooling. Most are one-time buys; the 1/8″ upcut spirals are consumables (one breaks per shell).

| Item | Qty | Source |
|---|-----|---|
| Solid carbide upcut spiral 1/8″ × 1/4″ shank | 3 | Amana 46202 (preferred) |
| Ball-end mill 3/4″ × 1/2″ shank (V2/V4 dome surfacing) | 1 | Amana 46377 |
| Rabbeting bit set with bearing kit, 1/4″ shank | 1 | Rockler |
| Step drill bit, 1/4″–3″ in 1/4″ increments | 1 | Irwin Unibit (Amazon) |

## Hardware and consumables

| Item | Qty (per drum) | Notes |
|---|---|---|
| Titebond III wood glue, 16 oz | 1 (shared 2 drums) | Waterproof; 4000 psi shear |
| Watco Danish Oil, natural, qt | 1 (shared 4 drums) | 3-coat finish |
| Renaissance Wax, 65 ml | 1 (shared 4 drums) | Final shell finish |
| Sandpaper assortment 80/120/220/320/400/600 grit | 1 set | Local hardware store |
| Buna-N O-ring (sized to gu port) | 1 | Optional Hapi-style port lining |
| Adhesive felt floor-protection pads, 1″ dia | 4 | Local hardware |
| Hemp rope, 1/2″, 4 ft | 1 (Std/Floor)  | Optional carry handle |

## Skin/heads

**N/A** — this is a slit-tongue idiophone, not a membrane drum. No skins required. (Distinguishes this design from the conga and ashiko families which use mule or LP heads.)

## Acoustic test gear (one-time shop equipment)

These are workshop instruments, not per-drum consumables. Listed for budget transparency.

| Item | Qty | Notes |
|---|-----|---|
| Korg OT-120 wide-range chromatic tuner | 1 | Already owned |
| Microphone + REW software for Helmholtz | 1 | Phone + free Spectroid app acceptable |

## Lead-time summary

| Category | Typical lead time |
|---|---|
| Lumber (Bell Forest) | 5 days |
| Lumber (Cook Woods) | 4 days |
| Tooling (Amana, Rockler)| 2–3 days |
| Hardware (McMaster) | 2 days |
| Local hardware | same-day |

Critical path for first prototype: lumber + slit bits. Order both at start of Phase 1; tooling can be ordered immediately on project kickoff.

## Quote request

Please confirm:

1. Current per-board-foot price on Black Walnut 4/4 FAS (we want clear, edge-jointable stock — figured grade is *not* required for this design and adds cost without acoustic benefit).
2. Padauk availability in 3/8″ thickness *as a stock item*. If only 4/4 is stocked, we will glue / resaw — quote both options.
3. Lead-time guarantees for Q2 2026.
4. Volume-discount thresholds — we may run multiple drums (V1 first, V2 reuses the same shell) over the next 12 months.

Heifer Zephyr Instruments
Tony Koop
[github.com/tonykoop/wood-shell-tongue-drum](https://github.com/tonykoop/wood-shell-tongue-drum)

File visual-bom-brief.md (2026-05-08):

# Visual BOM — Photo shotlist for the BOM hero plate

A Visual BOM lays out every part for one drum on a flat surface against a clean backdrop and labels the parts with quantities, IDs, and final cost. The result is a single hero-style photograph that serves as the cover image for the build-log site, the printable shop packet, and the recruiter-facing deck.

## Hero shot — V1 Standard 16″ (recommended first prototype)

**Frame:** top-down, 4:5 portrait orientation, shop-tabletop or seamless butcher-paper backdrop (warm neutral — kraft or off-white).

**Lighting:** one diffused softbox at 45° camera-left, slight bounce-fill from camera-right.

**Layout** (top-down grid, parts arranged left-to-right by build phase):

```
Row 1 — Body
  [16 stave blanks fanned in a circle]   [shell after lathe-turning, set on rim]   [rabbet detail close-up]

Row 2 — Soundboard
  [Padauk disc with slit pattern routed]  [1/8" upcut spiral bit]  [tongue length schedule card]

Row 3 — Tuning hardware (sparse)
  [step drill bit]  [Buna-N O-ring]  [Korg OT-120 tuner]

Row 4 — Finish + accessory
  [Watco Danish Oil]  [Renaissance Wax]  [pair of mallets]  [felt foot pads]
```

Caption: `Wood Shell Tongue Drum — V1 Cylinder + Flat Top, Standard 16″ — Heifer Zephyr Instruments — Total BOM ~$XXX`. Plug the actual rolled-up sum from `bom.csv` extended_cost column for V1+Standard rows.

## Detail shots — shared across variants

1. **Stave miter** — close-up of one stave edge showing 11.25° bevel against a digital protractor. Side-lit to emphasize the angle.
2. **Tongue slit** — extreme close-up of one slit-and-tongue, top-down, showing kerf width and the slit terminus geometry. Side-lit.
3. **Rabbet joint** — section view of the rabbet with the soundboard half-engaged. Highlights the air-seal surfaces.
4. **Gu port** — bottom view of the shell with the step-drilled port; ruler in frame for scale.
5. **Bowl ring stack** (V3/V4 only) — one of the graduated rings photographed flat against the backdrop, showing 12-segment construction with the 15° miters.
6. **Domed soundboard** (V2/V4 only) — 3/4 angle showing the dome rise on the Padauk blank after CNC surfacing; light raking across the curve to show the parabolic profile.

## Variant comparison shot (after Phases 1–4)

After all four variants are built, one final group shot:

- V1, V2, V3, V4 in a row at Standard 16″ size, soundboards facing camera, 3:2 landscape orientation.
- Backdrop: dark-gray seamless or wood floor.
- Lighting: two softboxes at 45° each side, slightly above eye level.
- Caption: `Heifer Zephyr Wood Shell Tongue Drum — V1 → V4 Family — All Standard 16″, A Kurd`.

This becomes the hero on the build-log site (`site/index.html`) once all four variants ship.

## Process / progression montage

A 4 × 2 grid of in-shop process shots illustrating the build sequence:

1. Stave glue-up under ratchet straps
2. Lathe-truing the OD
3. CNC routing the tongue slits in Padauk soundboard
4. Rabbet joint assembly with cauls
5. Gu-port step-drilling with mic + tuner in frame
6. Tongue tuning with sanding bar and Korg
7. Final finish — Danish Oil application
8. Hero shot of the finished V1 Standard

This montage anchors the build-log site mid-page and serves as the printable packet's "build workflow" foldout.

## Constraints

- All photographs must show **the actual instrument and parts**, not concept renders. The concept sheet in `concepts/` is for ideation; the BOM hero is for documentation.
- Dimensions in caption text must match `bom.csv` and `cut-list.csv` exactly. Any drift is a packet-validation failure.
- No props that aren't part of the BOM. Parts should look like a clean inventory, not a styled lifestyle shot.
- Shot list updates: as builds complete, replace each Required cell with a real path (`images/IMG-XXXX.jpg`) and mark Status = Captured.

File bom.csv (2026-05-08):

part_id | description | variant | size | quantity | unit | unit_cost_usd | extended_cost_usd | critical | notes
SHELL-STAVE-WALNUT-T | Black Walnut stave, 4/4 stock, 6.5in length | V1+V2 | Travel 12in | 16 | each | 3.00 | 48.00 | Y | Rip from 4/4; bevel 11.25 deg both edges; sand inside to 220
SHELL-STAVE-WALNUT-S | Black Walnut stave, 4/4 stock, 9.5in length | V1+V2 | Standard 16in | 16 | each | 4.50 | 72.00 | Y | Rip from 4/4; bevel 11.25 deg both edges. Recommended first prototype.
SHELL-STAVE-WALNUT-F | Black Walnut stave, 4/4 stock, 11.5in length | V1+V2 | Floor Pouf 20in | 16 | each | 5.50 | 88.00 | Y | Rip from 4/4; bevel 11.25 deg both edges
SHELL-SEG-WALNUT-T | Black Walnut segment blank, 4/4 stock, 4 in piece | V1+V2 (alt) | Travel 12in | 96 | each | 0.50 | 48.00 | N | Alt body: 8 rings x 12 segments, 15 deg miter. Skip if building stave.
SHELL-SEG-WALNUT-S | Black Walnut segment blank, 4/4 stock, 5 in piece | V1+V2 (alt) | Standard 16in | 96 | each | 0.65 | 62.40 | N | Alt body: 8 rings x 12 segments. Skip if building stave.
SHELL-SEG-WALNUT-F | Black Walnut segment blank, 4/4 stock, 6 in piece | V1+V2 (alt) | Floor Pouf 20in | 96 | each | 0.80 | 76.80 | N | Alt body: 10 rings x 12 segments. Skip if building stave.
BOWL-SEG-WALNUT-T | Black Walnut segment blank, 4/4 stock (graduated rings) | V3+V4 | Travel 12in | 72 | each | 0.55 | 39.60 | N | 6 rings of decreasing dia for hemisphere
BOWL-SEG-WALNUT-S | Black Walnut segment blank, 4/4 stock (graduated rings) | V3+V4 | Standard 16in | 96 | each | 0.65 | 62.40 | N | 8 rings of decreasing dia for hemisphere
BOWL-SEG-WALNUT-F | Black Walnut segment blank, 4/4 stock (graduated rings) | V3+V4 | Floor Pouf 20in | 120 | each | 0.80 | 96.00 | N | 10 rings of decreasing dia for hemisphere
BOWL-BLANK-WALNUT-T | Black Walnut glue-up blank for CNC bowl, 13x13x4 in | V3+V4 (alt) | Travel 12in | 1 | each | 85.00 | 85.00 | N | Alt body: 4x 1in plies. CNC 3D-surface inside and outside.
BOWL-BLANK-WALNUT-S | Black Walnut glue-up blank for CNC bowl, 17x17x5 in | V3+V4 (alt) | Standard 16in | 1 | each | 140.00 | 140.00 | N | Alt body: 5x 1in plies. CNC 3D-surface inside and outside.
BOWL-BLANK-WALNUT-F | Black Walnut glue-up blank for CNC bowl, 21x21x6 in | V3+V4 (alt) | Floor Pouf 20in | 1 | each | 210.00 | 210.00 | N | Alt body: 6x 1in plies. CNC 3D-surface inside and outside.
SOUNDBOARD-PADAUK-T | Padauk soundboard disc, 12.25 in OD, 0.25 in | V1+V3 | Travel 12in | 1 | each | 42.00 | 42.00 | Y | CNC-cut to OD. Slits routed before glue-up.
SOUNDBOARD-PADAUK-S | Padauk soundboard disc, 16.25 in OD, 0.375 in | V1+V3 | Standard 16in | 1 | each | 68.00 | 68.00 | Y | CNC-cut to OD. Slits routed before glue-up. Recommended first prototype.
SOUNDBOARD-PADAUK-F | Padauk soundboard disc, 20.25 in OD, 0.5 in | V1+V3 | Floor Pouf 20in | 1 | each | 98.00 | 98.00 | Y | CNC-cut to OD. Slits routed before glue-up. Consider Cedar substitute for D3 fit margin.
SOUNDBOARD-CEDAR-F-ALT | Western Red Cedar soundboard disc, 20.25 in OD, 0.5 in | V1+V3 alt | Floor Pouf 20in | 1 | each | 55.00 | 55.00 | N | Alternate to Padauk for tight D3 ding fit (K=29013 shortens tongues)
DOMEBLANK-PADAUK-T | Padauk dome glue-up blank, 13x13 in, 1.5 in thick (3 plies x 0.5) | V2+V4 | Travel 12in | 1 | each | 75.00 | 75.00 | Y | 3D-surface 0.5 in dome rise on CNC; +2.5% tongue length correction
DOMEBLANK-PADAUK-S | Padauk dome glue-up blank, 17x17 in, 1.5 in thick (3 plies x 0.5) | V2+V4 | Standard 16in | 1 | each | 125.00 | 125.00 | Y | 3D-surface 0.75 in dome rise on CNC; +2.5% tongue length correction
DOMEBLANK-PADAUK-F | Padauk dome glue-up blank, 21x21 in, 1.5 in thick (3 plies x 0.5) | V2+V4 | Floor Pouf 20in | 1 | each | 180.00 | 180.00 | Y | 3D-surface 1 in dome rise on CNC; +2.5% tongue length correction
DOMEBLANK-POPLAR-S | Poplar dome blank for prototype validation, 17x17 in, 1.5 in | V2+V4 proto | Standard 16in | 1 | each | 32.00 | 32.00 | N | Cheap test blank to dial in dome surfacing before Padauk
GUE-TITEBOND3 | Titebond III wood glue, 16oz | All | All | 2 | bottle | 18.00 | 36.00 | Y | Waterproof; 4000 psi shear. Rated for tongue-drum service.
RABBET-BIT-RBR | Rabbeting router bit set with bearing kit, 1/4 in shank | V1+V3 build | All | 1 | set | 42.00 | 42.00 | N | For shell rim rabbet. One-time tooling buy.
SLIT-BIT-UPCUT-1-8 | Solid carbide upcut spiral bit, 1/8 in, 1/4 in shank | All | All | 3 | each | 16.00 | 48.00 | Y | For tongue slits. Buy 3 (one breaks per shell). 1/4 in shank for CNC router collet.
BALLEND-3-4 | Ball-end mill, 3/4 in, 1/2 in shank | V2+V4 | All | 1 | each | 38.00 | 38.00 | Y | For dome 3D-surfacing on CNC
GU-STEPBIT-3 | Step drill bit, 1/4 to 3 in, 1/4 in increments | All | All | 1 | each | 28.00 | 28.00 | Y | For incremental gu-port enlargement during Helmholtz tuning
ORING-RUBBER-25 | Rubber O-ring, 2.5 in ID, 1/8 in cross-section | V1+V3 | Standard 16in | 1 | each | 2.50 | 2.50 | N | Optional gu-port lining for cleaner tone (Hapi-style)
ORING-RUBBER-30 | Rubber O-ring, 3 in ID, 1/8 in cross-section | V1+V3 | Floor Pouf 20in | 1 | each | 3.00 | 3.00 | N | Optional gu-port lining
ORING-RUBBER-20 | Rubber O-ring, 2 in ID, 1/8 in cross-section | V1+V3 | Travel 12in | 1 | each | 2.00 | 2.00 | N | Optional gu-port lining
FELT-FOOT-PADS | Adhesive felt floor-protection pads, 1 in dia | All | All | 4 | each | 0.50 | 2.00 | N | Mount under bowl/cylinder bottom edge
HANDLE-ROPE-S | Hemp rope, 0.5 in, for carry handle | All | Standard 16in+ | 4 | ft | 2.50 | 10.00 | N | Pass through two 0.5 in holes drilled in bowl side; knot inside
FINISH-DANISH-OIL | Watco Danish Oil, natural, qt | All | All | 1 | each | 28.00 | 28.00 | N | 3 coats, 24h between
FINISH-WAX-CARNAUBA | Renaissance Wax, 65ml | All | All | 1 | each | 18.00 | 18.00 | N | Final coat on shell exterior
SANDPAPER-SET | Sandpaper assortment 80/120/220/320/400/600 grit | All | All | 1 | set | 32.00 | 32.00 | N
TUNER-KORG-OT120 | Korg OT-120 wide-range tuner | All | All | 1 | each | 180.00 | 180.00 | N | Shop tool. Already owned in Tony's shop. Listed for cost transparency.
MALLET-SET | Tongue drum mallets, soft rubber heads, pair | All | All | 1 | set | 18.00 | 18.00 | N | Player accessory, included with finished drum

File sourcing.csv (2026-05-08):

part_id | supplier | supplier_url | sku_or_search | lead_time_days | moq | verified_price_date | price_volatility | required_spec | search_terms | notes
SHELL-STAVE-WALNUT-S | Bell Forest Products | bellforestproducts.com | black walnut 4/4 S2S FAS | 5 | 1 BdFt | 2026-05-07 | low | 4/4 S2S FAS black walnut, edge-jointable | black walnut 4/4 turning blanks | Recommended supplier for shell stock
SHELL-STAVE-WALNUT-T | Bell Forest Products | bellforestproducts.com | black walnut 4/4 S2S FAS | 5 | 1 BdFt | 2026-05-07 | low | 4/4 S2S FAS black walnut | black walnut 4/4
SHELL-STAVE-WALNUT-F | Bell Forest Products | bellforestproducts.com | black walnut 4/4 S2S FAS | 5 | 1 BdFt | 2026-05-07 | low | 4/4 S2S FAS black walnut | black walnut 4/4
SHELL-SEG-WALNUT-S | Cook Woods | cookwoods.com | black walnut 4/4 turning blanks | 4 | 1 | 2026-05-07 | low | Bulk segment-grade walnut blanks | walnut turning blanks 4/4 | Alt source for segmented body
BOWL-SEG-WALNUT-S | Cook Woods | cookwoods.com | black walnut 4/4 turning blanks | 4 | 1 | 2026-05-07 | low | Graduated-diameter ring blanks | walnut turning blanks 4/4
BOWL-BLANK-WALNUT-S | Cook Woods | cookwoods.com | black walnut 8/4 thick stock | 10 | 1 | 2026-05-07 | medium | 5x 1in plies for CNC bowl glue-up | walnut 8/4 thick | CNC bowl alt path; verify thickness availability
SOUNDBOARD-PADAUK-S | Bell Forest Products | bellforestproducts.com | padauk 3/8 figured S4S | 5 | 1 BdFt | 2026-05-07 | medium | Padauk 3/8 in thickness, FAS, edge-quartersawn preferred | padauk 4/4 S4S | Critical: thickness controls tongue length. Verify 3/8 in. Quartersawn improves bend stability.
SOUNDBOARD-PADAUK-T | Bell Forest Products | bellforestproducts.com | padauk 1/4 S4S | 5 | 1 BdFt | 2026-05-07 | medium | Padauk 1/4 in thickness, FAS | padauk thin stock
SOUNDBOARD-PADAUK-F | Bell Forest Products | bellforestproducts.com | padauk 1/2 S4S | 5 | 1 BdFt | 2026-05-07 | medium | Padauk 1/2 in thickness, FAS | padauk 1/2 in
SOUNDBOARD-CEDAR-F-ALT | Old Growth Music | oldgrowthmusic.com | western red cedar soundboard 1/2 quartersawn | 7 | 1 | 2026-05-07 | medium | WRC 1/2 in quartersawn, A grade | western red cedar soundboard 1/2 | Alt for D3 ding fit on Floor Pouf
DOMEBLANK-PADAUK-S | Bell Forest Products | bellforestproducts.com | padauk 4/4 boards (3 boards required) | 5 | 1 BdFt | 2026-05-07 | medium | 3x 1/2in boards, edge-jointable | padauk 4/4 S4S | Glue 3 plies to make dome blank thicker than 1.5 in
DOMEBLANK-POPLAR-S | Lowe's | lowes.com | poplar 1x12 board (3 boards) | 1 | 1 | 2026-05-07 | low | 3x poplar boards 1x12x18in | poplar 1x12 | Cheap test stock for dome surfacing rehearsal
GUE-TITEBOND3 | Rockler | rockler.com | Titebond III 16oz | 2 | 1 | 2026-05-07 | low | PVA wood glue, waterproof, 4000 psi shear | Titebond III
RABBET-BIT-RBR | Rockler | rockler.com | rabbeting router bit set with bearing kit | 2 | 1 | 2026-05-07 | low | 1/4 in shank, multi-bearing rabbet kit | rabbeting bit set
SLIT-BIT-UPCUT-1-8 | Amana Tool | amanatool.com | 46202 1/8in upcut spiral | 3 | 1 | 2026-05-07 | low | Solid carbide, 1/8 in, 1/4 in shank, upcut spiral | Amana 46202 1/8 upcut
BALLEND-3-4 | Amana Tool | amanatool.com | 46377 3/4 ball nose | 3 | 1 | 2026-05-07 | low | 3/4 in ball nose, 1/2 in shank, solid carbide | Amana 46377 3/4 ball nose
GU-STEPBIT-3 | Amazon | amazon.com | Irwin Unibit step drill 1/4 to 3 in | 2 | 1 | 2026-05-07 | low | Step bit covering 0.25 to 3 in in 1/4 in increments | step drill bit 1/4 to 3 in
ORING-RUBBER-25 | McMaster-Carr | mcmaster.com | 9452K42 Buna-N O-ring 2-1/2 ID 1/8 thick | 2 | 1 | 2026-05-07 | low | Buna-N O-ring 2.5 ID, 1/8 cross | O-ring 2.5 in ID 1/8
ORING-RUBBER-20 | McMaster-Carr | mcmaster.com | 9452K38 Buna-N O-ring 2 ID 1/8 thick | 2 | 1 | 2026-05-07 | low | Buna-N O-ring 2 ID, 1/8 cross | O-ring 2 in ID 1/8
ORING-RUBBER-30 | McMaster-Carr | mcmaster.com | 9452K46 Buna-N O-ring 3 ID 1/8 thick | 2 | 1 | 2026-05-07 | low | Buna-N O-ring 3 ID, 1/8 cross | O-ring 3 in ID 1/8
HANDLE-ROPE-S | Knot and Rope Supply | knotandrope.com | hemp rope 1/2 in 25 ft hank | 3 | 1 | 2026-05-07 | low | Natural hemp rope, 1/2 in dia | hemp rope 1/2 in
FELT-FOOT-PADS | Hardware store | local | felt floor-protection pads | 1 | 1 | 2026-05-07 | low | Adhesive 1 in felt circles | felt furniture pads 1 in
FINISH-DANISH-OIL | Rockler | rockler.com | Watco Danish Oil natural quart | 2 | 1 | 2026-05-07 | low | Penetrating oil finish, natural color | Watco Danish Oil natural quart
FINISH-WAX-CARNAUBA | Rockler | rockler.com | Renaissance Wax 65ml | 2 | 1 | 2026-05-07 | low | Microcrystalline wax for final finish | Renaissance Wax
SANDPAPER-SET | Hardware store | local | sandpaper assortment 80-600 grit | 1 | 1 | 2026-05-07 | low | Mixed grits 80/120/220/320/400/600 | sandpaper assortment
MALLET-SET | Hapi Drum | hapidrum.com | silicone tongue drum mallet pair | 5 | 1 | 2026-05-07 | low | Soft rubber/silicone heads, 8 in shaft | tongue drum mallets pair

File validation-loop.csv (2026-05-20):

check_id | packet_artifact | readiness_before | prediction_source | target | tolerance | method | measured_result | status | next_action | evidence | source_status
vl001 | wood-shell-tongue-drum-design-table.xlsx | L1_packet | design table formulas | parametric family inputs drive tongue lengths shell dimensions and Helmholtz estimates | formula/source audit required | Audit workbook cells against design.md and family-spec.csv before CAD release | TBD | measurement_required | Re-run formula audit before deriving CAD/DXF/G-code | design.md | needs_current_check
vl002 | validation.csv | L1_packet | design.md section 4 | V1 Standard A Kurd tongue field lands within tuning band after first build | +/- 30 cents per tongue | Measure each tongue with Korg OT-120 or equivalent and record cents error | TBD | measurement_required | Build V1 Standard prototype and populate measured_value/cents_error/environment fields | validation.csv | measurement_required
vl003 | validation.csv | L1_packet | Padauk library K constant | actual Padauk K for the selected stock matches or updates 24438 | +/- 5 percent | Cut calibration tongue then back-solve K_actual = f * L^2 / t | TBD | measurement_required | Measure the A4 calibration tongue before cutting the remaining tongue field | design.md | measurement_required
vl004 | validation.csv | L1_packet | Helmholtz formula in design.md | V1 Standard cavity response stays in coupled regime f_H/f_ding 0.80-1.20 | 0.80-1.20 ratio | Port puff or swept-sine microphone test above the soundboard | TBD | measurement_required | Record measured f_H and final gu-port diameter after step drilling | validation.csv | measurement_required
vl005 | design.md | L1_packet | derived dome correction | V2/V4 curved-cantilever multiplier is calibrated before cutting all domed tongues | measured multiplier required | Tap-test one domed prototype tongue and back-fit multiplier | TBD | measurement_required | Do not cut a full V2/V4 tongue field until multiplier is measured | risks.md | measurement_required
vl006 | cad/README.md | L1_packet | CAD staging plan | CAD assembly reflects calibrated workbook values | file required after calibration | Compare CAD dimensions to workbook after Phase 1 measurements | TBD | blocked | Generate SolidWorks/STEP/STL only after Phase 1 calibration | cad/README.md | missing_artifact
vl007 | cnc/README.md | L1_packet | CNC staging plan | DXF/G-code is derived from calibrated CAD/CAM, not concept imagery | file required after calibration | Review CAM source and machine-specific post before release | TBD | blocked | Defer DXF/G-code release until CAD and measurement calibration exist | cnc/README.md | missing_artifact
vl008 | drawings/00-hero-v1-standard.svg | L1_packet | design table derived preview | hero SVG remains documented as preview and not hidden fabrication authority | register passes | Run validate_visual_authority.py on visual-output-register.csv | TBD | measurement_required | Keep visual register current when drawings or concept images change | visual-output-register.csv | needs_current_check
vl009 | assembly-manual.md | L1_packet | shop build plan | shell rim flatness wall thickness and air seal meet the measurement gates | measurement_required | Dial indicator, calipers, and low-pressure leak/smoke test | TBD | measurement_required | Measure shell before final soundboard glue-up | validation.csv | measurement_required
vl010 | risks.md | L1_packet | seasonal movement risk | rabbet joint survives humidity cycling without leaks or pitch drift | cycle test required | Rest/tune/recheck after humidity cycle and record drift | TBD | measurement_required | Add Phase 1 post-rest drift notes to validation-report.md | risks.md | measurement_required

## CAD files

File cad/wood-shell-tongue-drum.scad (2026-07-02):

// Wood Shell Tongue Drum parametric master — V1 Cylinder + Flat Top,
// Standard 16" envelope: shell + soundboard + tongue LAYOUT reference marks.
//
// Authority: pending_measurement. NOT fabrication authority until reviewed
// against a measured prototype (see visual-output-register.csv CAD-001 and
// cad/mcp-session-log.md). This is a planning envelope: cad/README.md
// explains CAD is deliberately deferred until Phase 1 measurements are
// folded back into the workbook.
//
// SCOPE BOUNDARY (per instrument-maker skill "hand-refined, tuning-sensitive
// regions" rule): this models the shell/soundboard ENVELOPE and the tongue
// POSITION/LENGTH layout (thin reference marks on the soundboard) from the
// design.md position grid. It does NOT model the actual slit-routing cut
// geometry (kerf path, tongue-base relief pocket, U-shaped slot) — that is
// explicitly out of scope until CNC pocketing geometry is reviewed
// (drawing-brief.md Sheet 03, cnc/README.md). The gu port is a documented
// parameter only; design.md does not give a (r, theta) position for it in
// the schedule, so it is NOT placed geometrically here (would be an invented
// dimension) — see gu_port_dia_in comment below.
//
// Dimension sources (do not edit values without updating the source record):
//   - shell OD/height/wall thickness, soundboard thickness/diameter, gu port
//     diameter: design.md §4 "Recommended first prototype" build table
//   - tongue count/lengths, radial position grid (r, theta): design.md §4
//     tongue length schedule + drawing-brief.md Sheet 03 position grid
//     ("derived estimates for the layout drawing" per drawing-brief.md —
//     SolidWorks parametric placement against shell radius will refine them)
//   - tongue width, slit kerf width: design.md §4 build table
//
// Units: inches (packet's native shop unit for this build table).

/* [Shell] */
shell_od_in         = 16.00;  // design.md §4 "Shell OD"
shell_height_in     = 8.00;   // design.md §4 "Shell height"
wall_thickness_in   = 0.625;  // design.md §4 "Wall thickness" (finished, after lathe truing)
floor_thickness_in  = wall_thickness_in; // ASSUMPTION: bottom floor equals wall thickness; not
                                          // separately specified in design.md (stave + lathe-turned
                                          // closed bowl construction — "16 staves + 1 disc = 17 pieces").

/* [Soundboard] */
soundboard_dia_in   = 16.00;  // design.md §4 "Disc diameter" (= shell OD)
soundboard_thk_in   = 0.375;  // design.md §4 "Soundboard thk"
rabbet_depth_in     = 0.25;   // design.md §4 "rabbet ¼in deep"
rabbet_width_in     = 0.375;  // design.md §4 "× ⅜in wide"

/* [Gu port — parameter only, NOT placed: no (r,theta) in design table] */
gu_port_dia_in      = 2.5;    // design.md §4 "Gu port Ø" — initial; final size set by Helmholtz tuning in shop

/* [Tongue field — A Kurd, 11 tongues, zigzag-ascending] */
tongue_width_in     = 1.25;   // design.md §4 "Tongue width"

/* [Render quality] */
$fn = 96;

// ---------------------------------------------------------------------------
// Tongue position/length schedule — drawing-brief.md Sheet 03 position grid
// [id, note, r_in, theta_deg, length_in]
// theta measured from the ding centerline per drawing-brief.md; ding itself
// has no theta (r=0, centered) so it is handled as a special case below.
// ---------------------------------------------------------------------------

tongue_schedule = [
    ["Ding", "A3", 0.0,   0,   6.454],
    ["1",    "E4", 4.0,  60,   5.273],
    ["2",    "F4", 4.0, -60,   5.123],
    ["3",    "G4", 5.5,  90,   4.835],
    ["4",    "A4", 5.5, -90,   4.564],
    ["5",    "B4", 6.5, 120,   4.308],
    ["6",    "C5", 6.5,-120,   4.185],
    ["7",    "D5", 6.0,  30,   3.950],
    ["8",    "E5", 6.0, -30,   3.728],
    ["9",    "G5", 6.5, 150,   3.419],
    ["10",   "A5", 6.5,-150,   3.227],
];

// ---------------------------------------------------------------------------
// Derived geometry
// ---------------------------------------------------------------------------

shell_or_in   = shell_od_in / 2;
shell_ir_in   = shell_or_in - wall_thickness_in;
soundboard_r_in = soundboard_dia_in / 2;

// ---------------------------------------------------------------------------
// Shell — hollow stave cylinder, closed floor (lathe-turned bowl form)
// ---------------------------------------------------------------------------

module shell() {
    difference() {
        cylinder(h = shell_height_in, r = shell_or_in);
        translate([0, 0, floor_thickness_in])
            cylinder(h = shell_height_in, r = shell_ir_in); // open cavity above the floor
    }
}

// ---------------------------------------------------------------------------
// Soundboard — flat disc, rabbet-seated on the shell rim
// ---------------------------------------------------------------------------

module soundboard() {
    translate([0, 0, shell_height_in - rabbet_depth_in])
        cylinder(h = soundboard_thk_in, r = soundboard_r_in);
}

// ---------------------------------------------------------------------------
// Tongue layout reference marks — position + length ONLY, not cut geometry.
// Rendered as thin raised bars on top of the soundboard so the layout is
// visually distinct from the (unmodeled) actual routed slit.
// ---------------------------------------------------------------------------

marker_thickness_in = 0.03; // visual reference only, not a real dimension

module tongue_marker(r_in, theta_deg, length_in) {
    // Marker's near end sits at radius r_in from center, extending outward
    // along the radial (theta) direction by length_in.
    rotate([0, 0, theta_deg])
        translate([r_in, -tongue_width_in / 2, shell_height_in - rabbet_depth_in + soundboard_thk_in])
            cube([length_in, tongue_width_in, marker_thickness_in]);
}

module tongue_field() {
    for (t = tongue_schedule) {
        note = t[0];
        r_in = t[2];
        theta_deg = t[3];
        length_in = t[4];
        if (note == "Ding") {
            // Ding is centered at the soundboard origin; drawn along theta=0.
            translate([-length_in / 2, -tongue_width_in / 2, shell_height_in - rabbet_depth_in + soundboard_thk_in])
                cube([length_in, tongue_width_in, marker_thickness_in]);
        } else {
            tongue_marker(r_in, theta_deg, length_in);
        }
    }
}

// ---------------------------------------------------------------------------
// Top-level assembly
// ---------------------------------------------------------------------------

module wood_shell_tongue_drum_master() {
    shell();
    soundboard();
    tongue_field();
}

wood_shell_tongue_drum_master();

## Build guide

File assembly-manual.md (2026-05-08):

# Wood Shell Tongue Drum — Assembly Manual

Covers all four manufacturing variants (V1, V2, V3, V4) across three sizes (Travel 12″, Standard 16″, Floor Pouf 20″). Steps shared across variants are written once with branching notes where they diverge. Read `design.md` first — this manual assumes you have the parametric workbook open for size-specific dimensions and the recommended first prototype is **V1 Cylinder + Flat Top, Standard 16″, A Kurd**.

---

## Phase 0 — Shop preparation

1. Acclimate stock 2 weeks in the shop (60–70 °F, 40–55 % RH). Padauk and Black Walnut both move with seasonal humidity; soundboard cup or warp will scrap a tongue field that was previously in tune.
2. Joint and plane stock to nominal dimensions ± 0.005″.
3. Verify your saw kerf width with a test cut. The cut-list assumes a known kerf — measure yours before sizing rough stock.
4. Check the lathe — main spindle runout < 0.003″ TIR, tailstock alignment within 0.005″. A round shell amplifies any mounting wobble.
5. Verify CNC router calibration: a stock-thickness probe and tool-length probe both within ± 0.002″. Tongue slits depend on consistent depth.

---

## Phase 1A — Cylinder shell (V1, V2)

The cylinder is the *recommended* body for the first prototype. Two construction paths share Phases 1A.4 onward.

### 1A.1 Stave path (preferred for first build)

1. Rough-cut 16 staves to outline + 1/8″ on each side. Stock dimensions per `cut-list.csv` (Standard 16″: 9.5″ × 3.5″ × 0.875″).
2. Bevel both edges to 11.25° using a tilting-arbor jig referenced off the stave centerline (NOT off either edge — the stave is symmetric only when freshly ripped). Test on a sacrificial board first; verify the assembled circle closes by dry-clamping 4 staves and checking the included angle.
3. Sand the inside face to 220 grit. The inside is permanent and not turnable after glue-up.

### 1A.2 Segmented path (alternative for polychrome aesthetic)

1. Rough-cut 96 segments (8 rings × 12 segments) at 15° miter on a table-saw miter sled.
2. Stack rings on a lazy-susan jig for sequential glue-up. Each ring closes independently before stacking.
3. Diamond / 5-10-5 species patterns (Walnut + Maple + Cherry) read beautifully on 16″ Ottoman size — see `drawing-brief.md` §08 for layout templates.

### 1A.3 Stave glue-up (path A)

1. Lay all 16 staves flat on a tarp, edges touching, in their final order. Tape across all joints with strong masking tape.
2. Roll the assembly into a tube. Apply a thin even bead of Titebond III to every edge.
3. Re-roll, close to a full cylinder.
4. Wrap with three nylon ratchet straps OR run two large hose clamps. Do not over-tighten — squeeze-out should bead, not gush.
5. Stand the tube on a flat plate (¾″ MDF works) and check for end-square with a framing square. Adjust strap tension to pull any out-of-round into round.
6. Cure 24 hours.

### 1A.4 Lathe truing (both paths converge)

1. Mount a faceplate to a 3″ waste block. Glue the waste block to a ¼″ ply disk slightly larger than the shell ID.
2. Slide the shell over the disk; insert a soft-rubber expansion plug at the open end with the tailstock for support.
3. Turn the OD true to the design diameter (e.g., 16.00″ for Standard). Wall thickness target: 0.625″ finished.
4. Reverse-mount and turn the rim end. The rim must be planar (± 0.005″ TIR) — this is the airtight bond surface for the soundboard.
5. Cut a ¼″-deep × ⅜″-wide rabbet in the inside of the rim, sized to receive the soundboard disc (see `cut-list.csv` row S-DISC-01 for the disc dimensions).

---

## Phase 1B — Hemisphere bowl (V3, V4)

Pick one of two construction paths. Segmented is recommended for the first hemisphere build.

### 1B.1 Segmented bowl path

1. Rough-cut graduated rings per `cut-list.csv` rows S-BOWL-RING-01 through S-BOWL-RING-08 (Standard 16″: 8 rings of decreasing diameter from 16″ at the rim to ~3″ at the apex).
2. Glue each ring closed on the lazy-susan jig before stacking.
3. Stack rings with a centering jig (a vertical dowel through ring centers) and glue with Titebond III. Cure 24 h between layers.
4. Mount the assembled bowl on a faceplate with a thick waste block.
5. Lathe-true the outside to a parabolic profile (within 1/16″ of true sphere is acceptable — the lathe finishes any micro-step). Lathe-true the rim flat (± 0.005″ TIR).

### 1B.2 CNC-carved bowl path (alternative; high material waste)

1. Glue up a thick blank: 5 plies of 1″ Black Walnut for Standard 16″.
2. CNC 3D-surface the outside convex profile with a ¾″ ball-end bit; 0.05″ stepover for ≤ 32 µin surface finish.
3. Flip-jig the blank with datum pins; 3D-surface the inside concave profile.
4. Trim rim flat on a router table or lathe; verify ± 0.005″ TIR.

---

## Phase 2 — Soundboard (variant-dependent)

### 2A — Flat soundboard (V1, V3)

1. Cut Padauk disc to OD per `cut-list.csv` (Standard 16″: 16.25″ rough → 16.00″ final).
2. Mark the tongue layout on the *inside* face of the disc. Use the layout template in `cnc/README.md`.
3. CNC-route the tongue slits with a 1/8″ upcut spiral. Cut from inside face. Tongue lengths from `design.md` §4 — cut LONG by 0.030″ for tuning margin.
4. Sand the soundboard to 320 grit. **Do not break the slit edges** — chip damage causes pitch shifts that are difficult to recover.
5. Apply Watco Danish Oil to the *outside* face only. Three coats, 24 h between. Inside cavity stays unfinished (sealing the cavity damps the bass).

### 2B — Domed soundboard (V2, V4)

1. Glue up a 3-ply blank per `cut-list.csv` row S-DOME-BLANK (Standard 16″: 3 × 0.5″ Padauk = 1.5″ thick × 17″ × 17″).
2. **Rehearse on poplar first.** Cut a poplar test blank with the same dome profile (S-DOME-CNC-PROTO). Verify the toolpath produces a clean parabolic surface with no scallop steps before committing the Padauk blank.
3. 3D-surface the convex top with a ¾″ ball-end bit, 0.05″ stepover. Dome rise per size preset (Standard: 0.75″).
4. Flip the blank into a flip-jig with datum pins. 3D-surface the concave underside (matches OD rim for clean rabbet seat).
5. **Validate the curved cantilever multiplier.** Cut ONE tongue at the predicted length × 1.025 multiplier. Tap-test, measure pitch with a Korg OT-120. Back-solve the actual multiplier (`L_measured² × f / (K × t)` returns the new multiplier). Apply this measured multiplier to the remaining 10 tongue layouts before any further cutting.
6. Cut the remaining 10 tongues with the validated multiplier. Cut LONG by 0.030″ for tuning margin.
7. Sand and finish per Phase 2A steps 4–5.

---

## Phase 3 — Bowl-top assembly

The bowl-to-soundboard joint is **acoustically critical**: an air leak here destroys the Helmholtz Q. Any of three joint geometries can work; the rabbet is the working assumption.

### 3.1 Rabbet joint (preferred)

1. Verify the shell rim rabbet (cut in Phase 1A.4 / 1B): ¼″ deep × ⅜″ wide, ± 0.005″.
2. Verify the soundboard slip-fits into the rabbet with 0.005″ clearance — tight enough for a PVA bond, loose enough that you don't pry the rim apart on insertion.
3. Apply a uniform thin bead of Titebond III in the rabbet. Drop the soundboard in flush.
4. Apply two cauls (top and bottom) with band clamps OR a vacuum bag. Cure 24 h.

### 3.2 Lap step joint (backup)

If the rabbet leaks under puff-test (Phase 6), step-lap a thin (1/16″) Padauk veneer overlapping the rabbet seam from inside. Glue with Titebond III.

### 3.3 Cork gasket (last-resort backup)

If both rabbet and lap-step leak, install a 1/16″ cork ring in the rabbet under the soundboard. Compresses for an airtight seal but adds compliance that may damp the Helmholtz Q.

---

## Phase 4 — Gu-port tuning

The gu port is your primary Helmholtz tuning knob. It is drilled **last** and **deliberately undersized**, then opened up incrementally while measuring `f_H`. Opening the port raises `f_H`; adding a restrictor/liner or lengthening the port neck lowers `f_H`.

1. Drill a ¼″ pilot hole through the shell/bowl bottom, centered (verify ± 0.025″).
2. Place a small microphone above the port. Puff gently across the port edge (like blowing across a bottle top). Record the resonance frequency in REW or Spectroid.
3. Use a step-drill to enlarge the port in ¼″ increments. Re-measure `f_H` at each step. Stop when `f_H ≈ 0.88 × f_ding` (Standard 16″ V1: target ≈ 195 Hz).
4. **If the cavity is high** (ratio > 1.2 before the port reaches the target diameter): stop drilling. Lower `f_H` with a removable restrictor, port sleeve, longer effective neck, or revised chamber volume on the next build.
5. **If the cavity is low** (ratio < 0.8 even at the maximum safe port diameter): the chamber/neck model is under-predicting the port area required. Document the measured curve, do not keep enlarging into the rim margin, and re-evaluate the V2/V4 cavity model.

Optional: install a Buna-N O-ring in the finished port (BOM rows ORING-RUBBER-*) for a Hapi-style cleaner tone. Not required.

---

## Phase 5 — Tongue tuning

Tongues are cut LONG. Each one is tuned by filing the tongue tip (which shortens the effective length, *raising* the pitch). You cannot lower a tongue's pitch by filing — if a tongue measures sharp of target by more than 50 cents at first cut, that tongue is scrap.

1. Set up the drum on a soft surface (foam, blanket).
2. Strike each tongue at its tip with a soft mallet. Record pitch with a Korg OT-120 (or a phone tuner with cents resolution).
3. Compare to `validation.csv` predicted column.
4. For tongues > 5 cents flat: do nothing yet (let the tongue settle for 48 h after cutting before tuning).
5. For tongues > 5 cents sharp: file the tongue tip with a flat sanding bar (320 grit). Test pitch every 3–4 strokes. Each 0.030″ removed from the tip raises pitch by ~10–15 cents.
6. For tongues > 30 cents flat after 48 h settling: file the *underside* of the tongue at the base (thinning the cantilever lowers stiffness, which lowers pitch). This is a recovery move; ideally tongues are cut long enough to never need it.
7. Final tuning: ± 5 cents of target on all 11 tongues.
8. Document final measurements in `validation.csv`.

---

## Phase 6 — Validation and acceptance

Run the full validation loop before declaring the build complete:

| Check | Tool | Acceptance band |
|---|---|---|
| All 11 tongues to target | Korg OT-120 | ± 5 cents per tongue |
| Helmholtz coupling ratio | mic + spectrum | 0.80 ≤ f_H/f_ding ≤ 1.20 |
| Bowl-top airtight seal | smoke or vacuum test | no visible leakage at rabbet |
| Bearing-edge planarity | dial indicator | ± 0.005″ TIR |
| Wall thickness uniformity | calipers, 8 points | ± 0.030″ from nominal |
| Soundboard thickness uniformity| calipers, 9-pt grid | ± 0.005″ |
| Slit kerf width | feeler gauge, 5-pt | 0.125″ ± 0.005″ |
| Sustain T60 | REW software | 1.5 s ≤ T60 ≤ 4.0 s |
| A4 = 440.0 Hz sanity | tongue 4 measurement | within 5 cents of 440 Hz |

Record measured values in `validation.csv`. If A4 measures off > 5 cents, back-compute the actual K-constant of your specific stock (`K_actual = f × L² / t`) and update the per-family corrections database.

---

## Phase 7 — Finish and presentation

1. Apply 3 coats Watco Danish Oil to the shell exterior (24 h between coats).
2. Apply Renaissance Wax to the shell exterior (final coat, buffed).
3. Apply 3 coats Watco Danish Oil to the soundboard *outside* face only.
4. Adhere felt foot pads to the shell bottom (4 pads at 90° spacing).
5. Optional: install hemp carry handle (Standard size and above).
6. Photograph per `photo-shotlist.md`.
7. Tag the drum with maker plate (interior) and update the catalog entry in the master workbook.

---

## Branching summary

| Phase | V1 (Cyl + Flat) | V2 (Cyl + Dome) | V3 (Hemi + Flat) | V4 (Hemi + Dome) |
|---|---|---|---|---|
| 1 | 1A — cylinder | 1A — cylinder | 1B — bowl | 1B — bowl |
| 2 | 2A — flat | 2B — dome | 2A — flat | 2B — dome |
| 3 | 3.1 rabbet | 3.1 rabbet | 3.1 rabbet | 3.1 rabbet |
| 4 | 2.5″ port | larger measured port or sleeve experiment | 2.5″ port | larger measured port or sleeve experiment |
| 5 | flat tuning | flat + dome correction | flat tuning | flat + dome correction |
| 6 | full validation | full validation + dome multiplier check | full validation | full validation + dome multiplier check |
| 7 | standard finish | standard finish | standard finish  | standard finish  |

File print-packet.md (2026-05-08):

# Wood Shell Tongue Drum Capstone Print Packet

Generated: 2026-05-08
Packet folder: `wood-shell-tongue-drum`

## File Map

| File | Purpose |
| --- | --- |
| `design.md` | Project intent, catalog metadata, assumptions, and validation plan. |
| `bom.csv` | Starter bill of materials with part categories, quantities, drawing refs, and notes. |
| `sourcing.csv` | Supplier/search tracker with specs, price/date fields, lead time, substitutes, and risks. |
| `cut-list.csv` | Rough/final stock sizes, material, grain/orientation, operations, yield, and offcuts. |
| `drawing-brief.md` | Manufacturing drawing and technical product sketch brief. |
| `assembly-manual.md` | Shop-facing sequence, tools, fixtures, safety, tuning, finishing, and maintenance notes. |
| `validation.csv` | Target/measured values, tolerance, environment, result, and tuning/build action log. |
| `supplier-rfq.md` | Supplier email/request-for-quote starter. |
| `visual-bom-brief.md` | Art direction for an image-forward visual BOM. |
| `wolfram-starter.wl` | Wolfram starter for physics, optimization, visualization, and validation. |
| `README.md` | Project artifact. |
| `photo-shotlist.md` | Project artifact. |
| `risks.md` | Project artifact. |
| `validation-report.md` | Project artifact. |

## design.md

Project intent, catalog metadata, assumptions, and validation plan.

# Wood Shell Tongue Drum — Parametric Design Sheet

**Owner:** Tony Koop · Heifer Zephyr Instruments
**Family:** Slit-tongue idiophone with enclosed wooden resonator (round-body)
**Members:** four geometric variants (V1–V4) × three size envelopes (Travel 12″, Standard 16″, Floor Pouf 20″)
**Status:** Design v1 — formulas parametric in `wood-shell-tongue-drum-design-table.xlsx`; no physical prototype yet
**Recommended first prototype:** **V1 Cylinder + Flat Top, Standard 16″, A Kurd**

---

## 1. Intent

This is the round-body counterpart to Tony's existing rectangular-prism wood tongue drum. A wooden shell — cylinder or hemisphere — capped by a tonewood soundboard with CNC-cut slit tongues, tuned to a chosen scale, is a modern instrument category that does not exist commercially in this round-body × dome-top × premium-tonewood format. The enclosed cavity adds **Helmholtz resonance** that an open rectangular tongue drum cannot offer — warm bass coupling beneath the lowest tongue.

The sheet treats this as a *family with four variants* rather than as four separate designs. All twelve cells (4 variants × 3 sizes) are driven by the same shared inputs: shell OD, shell height, soundboard thickness/wood, gu-port diameter, dome rise. Change one preset cell in the workbook and every dimension in the matrix updates.

| ID  | Body | Top | Notes |
|-----|---|---|---|
| V1  | Cylinder | Flat | Lowest piece-count, most predictable tuning. **Start here.** |
| V2  | Cylinder | Domed | Steel-tongue-drum aesthetic on a wooden body |
| V3  | Hemisphere bowl | Flat | Tagine / Moroccan-pouf silhouette; bowl as parabolic reflector |
| V4  | Hemisphere bowl | Domed | Most steel-tongue-drum-adjacent silhouette in wood; near-spherical |

| Size | OD (in) | Height (in) | Soundboard (in) | Tongue width (in) | Target ding | Ding f (Hz) |
|---|---|---|---|---|---|---|
| Travel | 12 | 5 | 0.250 | 1.00 | D4 (MIDI 62)| 293.66 |
| Standard | 16 | 8 | 0.375 | 1.25 | A3 (MIDI 57)| 220.00 |
| Floor Pouf | 20 | 10 | 0.500 | 1.50 | D3 (MIDI 50)| 146.83 |

(All values in this document are computed from the workbook formulas, not pasted by hand. If you change the workbook, regenerate the BOM and validation CSVs.)

---

## 2. Governing acoustic model

The wood shell tongue drum is a **two-degree-of-freedom coupled oscillator**: the cantilever tongue is one resonator, the enclosed air cavity is another, and they share a common boundary (the soundboard).

### 2.1 Tongue — flat cantilever (Euler–Bernoulli)

For a slit tongue of length `L` (in) and thickness `t` (in) in wood with cantilever K-constant `K` (imperial composite):

```
f = K · t / L²              (flat top, Variants 1 and 3)
L = √( K · t / f )
```

Tony's material library (workbook §A, rows 19–25) records measured / literature K-constants for shop tonewoods:

| Wood | E (GPa) | ρ (kg/m³) | K (cantilever) | Tone | Rating |
|---|---|---|---|---|---|
| Padauk | 11.0 | 745 | 24,438 | warm, rich, sustain| ★★★★★ |
| Wenge | 15.8 | 870 | 27,103 | bright, punchy | ★★★★★ |
| Cherry | 10.3 | 560 | 27,275 | balanced sweet mid | ★★★★  |
| Black Walnut  | 11.6 | 610 | 27,734 | full, mellow | ★★★★  |
| Hard Maple | 12.6 | 705 | 26,887 | bright sustain | ★★★★  |
| Mahogany | 10.1 | 590 | 26,314 | warm, full bass | ★★★★  |
| W. Red Cedar  |  7.7 | 370 | 29,013 | light, guitar-like | ★★★ |

Padauk K = 24,438 is the lowest in the library and therefore yields the longest tongues for a given pitch — the design defaults to Padauk because it is most permissive of fitting low pitches in a given shell radius.

### 2.2 Tongue — curved cantilever (V2, V4)

A tongue cut into a domed soundboard is stiffer than a flat tongue. To preserve pitch we apply an empirical length correction:

```
L_curved = L_flat · 1.025         (+2.5 % for shallow domes, dome rise ≤ 6 % of OD)
```

This is a **starting estimate**, not a measured constant. The dominant uncertainty in V2 and V4 is whether 1.025 holds for our specific dome rise. Validation protocol: tap-tune one tongue at the design length, measure with a tuner, back-solve the actual factor, then apply to the remaining ten tongues. Treat the +2.5 % multiplier as *the empirical-learning loop's first measurement*.

### 2.3 Cavity — Helmholtz resonator

For an enclosed chamber of volume `V` (in³) with port area `A_port` (in²) and effective neck length `L_neck` (in):

```
f_H = (c / 2π) · √( A_port / (V · L_neck) )           with c = 13,552 in/s
```

Chamber volume formulas, by variant:

| Variant | Body shape | Cavity volume formula |
|---|---|---|
| V1 | Cylinder, flat top | `V = π · r² · H` |
| V2 | Cylinder + dome | `V = π · r² · H + (2/3) · π · r² · h_dome` |
| V3 | Hemisphere, flat | `V = (2/3) · π · r³` |
| V4 | Hemisphere + dome  | `V = (2/3) · π · r³ + (2/3) · π · r² · h_dome` |

Effective neck length:

| Top type | `L_neck` |
|---|---|
| Flat | soundboard thickness `t` |
| Domed | `t + h_dome / 2` |

The **Helmholtz target** is `f_H ≤ f_ding` — the cavity should resonate at or below the lowest tongue, so it acts as a bass extension rather than a competing pitch. Coupling falls into one of three regimes:

- `f_H / f_ding < 0.8` — free bass extension; cavity reinforces below the ding (good for floor pouf).
- `0.8 ≤ f_H / f_ding ≤ 1.2` — coupled regime; cavity and ding share modal energy (the design target).
- `f_H / f_ding > 1.2` — cavity sits above the ding; cavity will fight the ding rather than support it. **Mistuned high** — lower `f_H` by reducing effective port area, adding a removable restrictor/liner, lengthening the neck, or increasing the chamber volume.

The **gu port diameter** is the primary tuning knob. Because `f_H ∝ sqrt(A_port)`, opening the port raises the Helmholtz frequency; reducing effective area or increasing neck length lowers it. The port is drilled last, deliberately undersized, and opened up incrementally with a step bit while measuring `f_H` (gentle puff at the port, microphone above). This is the same field-tuning method used on Hapi-style steel tongue drums.

### 2.4 Computed Helmholtz / ding ratios (current presets)

Each cell below is `f_H` (Hz) computed from the formulas above with the current size-preset inputs, and the ratio against `f_ding` for that size. Bold cells sit in the coupled regime (0.8 ≤ ratio ≤ 1.2) — that is the buildable matrix.

| Variant | Travel 12″ (D4 ding 293.66 Hz) | Standard 16″ (A3 ding 220.00 Hz) | Floor Pouf 20″ (D3 ding 146.83 Hz) |
|---|---|---|---|
| V1 | 321.5 Hz · ratio **1.09** (tight) | **194.6 Hz · ratio 0.88** | **144.7 Hz · ratio 0.99** |
| V2 | 220.1 Hz · ratio 0.75 | 133.5 Hz · ratio 0.61 (under-coup) | 99.1 Hz · ratio 0.67 (under-coup) |
| V3 | 359.5 Hz · ratio 1.22 (over) | **238.3 Hz · ratio 1.08** | 177.2 Hz · ratio 1.21 (over, edge)  |
| V4 | 244.2 Hz · ratio 0.83 | 161.1 Hz · ratio 0.73 | 119.5 Hz · ratio 0.81 |

Reading the matrix: **V1 Standard 16″ and V1 Floor Pouf 20″ are in the sweet spot**; V3 Standard 16″ is also coupled. V2 cells are systematically under-coupled because the dome adds neck length without proportional volume — they will need a *larger* effective gu port than the preset 2.5″, a shorter effective neck, or a revised dome cavity model to lift `f_H`. V1 Travel 12″ is right at the upper edge of the coupled band.

### 2.4.1 Gu-port tuning direction

| Condition | Field symptom | Corrective direction | First shop action |
|---|---|---|---|
| `f_H/f_ding < 0.80` | Cavity too low / under-coupled | Raise `f_H` | Enlarge gu port in 0.25″ steps; if already at structural max, reduce neck length or revise chamber volume |
| `0.80 ≤ f_H/f_ding ≤ 1.20` | Coupled | Hold | Stop drilling; record final port diameter and environment |
| `f_H/f_ding > 1.20` | Cavity too high | Lower `f_H` | Install removable restrictor/liner, lengthen neck with a port sleeve, or increase chamber volume on the next build |

For the Standard 16″ V2 preset, the 2.5″ port predicts 133.5 Hz (`0.61 × ding`). A first-order diameter solve puts the lower coupled edge near 3.3″ and the `0.95 × ding` target near 3.9″, so the V2/V4 validation build should treat the port as a measured design variable, not a fixed decorative hole.

These values are **derived estimates**, not measured. They will shift once the first prototype is tuned and the per-family corrections database is populated.

### 2.5 Tongue-fit cap

For each size, the longest tongue (the ding) cannot exceed the radial fit cap:

```
L_cap = OD/2 − 1″                  (1″ reserved for ding-strike clearance and rim)
```

| Size | Cap (in) | V1/V3 ding length (in) | V2/V4 ding length (in) | Verdict |
|---|---|---|---|---|
| Travel 12″  | 5.00 | 4.56 (D4) | 4.68 (D4) | Fits — 9 % margin |
| Standard 16″| 7.00 | 6.45 (A3) | 6.62 (A3) | Fits — 8 % margin |
| Floor Pouf  | 9.00 | 9.12 (D3) | 9.35 (D3) | **Doesn't fit** |

Floor Pouf D3 ding overhangs by 0.12″ on flat tops and 0.35″ on domed tops. **Mitigation:** raise the ding to D♯3 (one semitone, MIDI 51, 155.6 Hz → flat L = 8.86″, fits with 0.14″ margin) OR thin the soundboard from 0.5″ → 0.4375″ (drops L to 8.53″, clean 0.47″ margin) OR substitute Cedar (K = 29,013 → flat L = 8.34″, 0.66″ margin). Cedar is the recommended fix because the soundboard span across 20″ wants stiffness against deflection, and Cedar's lower density lets the same thickness still bear the span.

---

## 3. Variant blocks — manufacturing and acoustic notes

Each block extends the workbook's §C–§F by spelling out the *manufacturing path* implied by the geometry.

### V1 — Ottoman Cylinder, Flat Top  ★ RECOMMENDED FIRST BUILD

**Body construction:** stave-built or segmented cylinder. The two paths are equally valid:

- **Stave shell**: 16 staves at 11.25° miter (180/16). Rip from 4/4 stock, joint edges, band-clamp glue-up around an MDF cylinder mold. Lathe-true OD/ID after cure (≥ 24 h). Wall thickness after turning: 5/8″–3/4″.
- **Segmented shell** (used when polychrome inlay is desired): 8 rings × 12 segments at 15° miter. Stack rings on a lazy-susan jig for glue-up. Diamond pattern with Walnut + Maple + Cherry accents reads beautifully on the Ottoman 16″ size.

**Top construction:** flat tonewood disc, CNC-cut to OD and edge-rabbeted ¼″ deep into the shell rim. Slits routed *before* glue-up so the tongues vibrate without router stress. Disc diameter = shell OD; thickness from preset.

**Tongue physics:** standard flat cantilever. Empirical detuning ≤ 1 % observed on Tony's prior rectangular drums — trust the model.

**Risk / Difficulty:** ★★ — proven flat-cantilever physics + well-trodden stave/segmented bowl method. Lowest risk in the matrix.

### V2 — Ottoman Cylinder, Domed Top

**Body construction:** same as V1.

**Top construction:** glue-up blank (3 plies × ~0.5″ = 1.5″ thick), flatten on jointer, then 3D-surface a parabolic dome (rise = preset 0.75″ on Standard) on the CNC. Bottom contour matches OD rim. Tongue slits cut afterward in one of two ways: (a) 1/8″ upcut spiral on a B-axis sled that tracks the dome curvature (preferred — preserves the dome face) or (b) flatten a sacrificial fixture under the dome to support tongue ends, then route slits with a regular 3-axis pass.

**Tongue physics:** curved cantilever stiffer than flat. The +2.5 % length correction is built into the workbook. Validate empirically: tap-tune ONE tongue and back-fit the multiplier *before* cutting all 11.

**Risk / Difficulty:** ★★★ — adds dome-surfacing risk and curved-cantilever uncertainty. Prototype the dome in poplar before committing Padauk.

### V3 — Hemisphere Bowl, Flat Top

**Body construction:** segmented (ring-stack of decreasing diameters approximating a hemisphere) or thick-glue-up CNC-carved hemisphere. Either path requires lathe-true rim flatness — the bowl-to-soundboard joint is acoustically critical.

**Top construction:** flat soundboard disc (same as V1). The shell rim must be precisely circular and planar — turn the rim true on the lathe *after* segment glue-up. Rabbet for the board is ¼″ deep.

**Tongue physics:** same flat cantilever as V1. The bowl shape doesn't affect tongue physics, only the Helmholtz coupling and projection pattern (the bowl acts as a parabolic reflector, projecting tongue energy upward through the slits).

**Risk / Difficulty:** ★★ — bowl turning is straightforward at 12–16″; > 18″ needs a lathe with ≥ 10″ swing over bed.

### V4 — Hemisphere Bowl, Domed Top

**Body construction:** glued bowl (segmented or stave) + glue-up dome blank, both 3D-surfaced on the CNC. Half-lap or rabbet joinery at the rim. Final assembly clamps with a custom radius caul.

**Top construction:** same dome workflow as V2.

**Tongue physics:** curved cantilever +2.5 % correction (same as V2). The flat → curved physics shift is the dominant uncertainty in V4; budget extra prototype tongues.

**Risk / Difficulty:** ★★★★ — highest piece-count + highest empirical tuning risk. Most beautiful result; **build last**.

---

## 4. Recommended first prototype — V1 Cylinder + Flat Top, Standard 16″

This is the **strongly recommended starting build**. Justification:

1. **Acoustic predictability.** Flat-cantilever physics has < 1 % empirical detuning on Tony's prior rectangular drums; the dome correction in V2/V4 is unmeasured.
2. **Helmholtz already coupled.** Standard 16″ V1 sits at `f_H / f_ding = 0.88` — inside the coupled band by design, with the gu port (2.5″) as the in-shop tuning knob if the measured ratio drifts.
3. **All 11 tongues fit cleanly.** Longest tongue (A3 ding) = 6.45″ vs the 7″ radial cap → 8 % margin. No risk of running out of soundboard.
4. **Lowest piece-count.** 16 staves + 1 disc = 17 wood pieces. Compare V4 segmented-bowl-plus-dome at 96+ pieces.
5. **Dual-path body construction.** If staves don't inspire the maker, the same shell can be built segmented for polychrome aesthetics (see V1 body construction notes).
6. **Validated workflow components.** Stave glue-up, lathe truing, CNC slit routing — all are skills exercised on Tony's existing ashiko, conga, and tongue-drum repos.

**Specific prototype build configuration:**

| Parameter | Value |
|---|---|
| Shell OD | 16.00″ |
| Shell height | 8.00″ |
| Shell wood | Black Walnut, 4/4 stock, 16 staves at 11.25° miter |
| Wall thickness | 0.625″ finished (after lathe truing) |
| Soundboard wood | Padauk (K = 24,438) |
| Soundboard thk | 0.375″ (3/8″) |
| Disc diameter | 16.00″ (rabbet ¼″ deep × ⅜″ wide into shell rim) |
| Scale | A Kurd (A3, B3, C4, D4, E4, F4, G4, A4, B4, C5, D5) |
| Ding | A3 (220.00 Hz), centered |
| Number of tongues | 11 (1 ding + 10 in zigzag-ascending pattern) |
| Slit kerf width | 0.125″ (1/8″ CNC upcut spiral) |
| Tongue width | 1.25″ |
| Gu port Ø | 2.5″ initial; final size set by Helmholtz tuning |
| Predicted f_H | 194.6 Hz (0.88 × ding) |

**Tongue length schedule** (Padauk 0.375″, A Kurd transposed from workbook §A reference scale):

| # | Note | MIDI | Freq (Hz) | L (in) | L (mm) |
|---|---|---|---|---|---|
| Ding | A3 | 57 | 220.00 | 6.454  | 163.93 |
| 1 | E4 | 64 | 329.63 | 5.273  | 133.93 |
| 2 | F4 | 65 | 349.23 | 5.123  | 130.12 |
| 3 | G4 | 67 | 392.00 | 4.835  | 122.81 |
| 4 | A4 | 69 | 440.00 | 4.564  | 115.92 |
| 5 | B4 | 71 | 493.88 | 4.308  | 109.41 |
| 6 | C5 | 72 | 523.25 | 4.185  | 106.30 |
| 7 | D5 | 74 | 587.33 | 3.950  | 100.33 |
| 8 | E5 | 76 | 659.26 | 3.728  |  94.70 |
| 9 | G5 | 79 | 783.99 | 3.419  |  86.84 |
| 10 | A5 | 81 | 880.00 | 3.227  |  81.97 |

(These are *cut lengths* of the slit, not the kerf. The CNC pocketing geometry — radial slit + perpendicular tongue-base relief — is detailed in `drawing-brief.md` and `cnc/README.md`.)

---

## 5. Build sequence — phases across the family

Phases are designed so each one produces a finished, playable instrument *and* a measurement that informs the next phase. This is the empirical-learning loop running across the four-variant matrix.

| Phase | Build | What it teaches |
|---|---|---|
| 1 | **V1 Standard 16″** ★ HERE | Shell stave construction, soundboard rabbet joint, gu-port tuning, Helmholtz coupling — all in one go. Confirms `f_H` model against measurement. |
| 2 | V2 Standard 16″ (same shell) | Curved-cantilever +2.5 % correction. Reuse Phase-1 cylinder shell — only the soundboard changes. Quantifies the dome correction factor. |
| 3 | V3 Standard 16″ | Hemisphere-bowl construction independent of dome work. Now we know flat-top + bowl independently. |
| 4 | V4 (Standard 16″ or Floor 20″) | Combine learnings. Premium tonewoods, signature Heifer Zephyr finish. |
| 5 | V1 Travel 12″ | Tightest tongue-fit margins; build last when the formulas are calibrated to your shop. |

This sequence delivers four distinct portfolio instruments while progressively retiring acoustic risk. Each phase's measurements feed back into `validation.csv` and the per-family corrections in the workbook.

---

## 6. Critical joints and tolerances

| Joint | Tolerance | Why |
|---|---|---|
| Shell rim flatness | ± 0.005″ TIR | Bowl-to-soundboard joint is the primary air seal (Helmholtz Q) |
| Soundboard rabbet fit | 0.005″ slip-fit  | Tight enough for PVA bond, loose enough to avoid prying |
| Stave miter angle | 11.25° ± 0.1° | A 0.5° error compounds over 16 staves to a 8° total deviation |
| Slit kerf width | 0.125″ ± 0.005″  | Wider kerfs lower tongue Q (energy leaks through the kerf) |
| Tongue length (per cut) | + 0.030″ initial | Cut long; file to pitch with a sanding bar (file shortens → raises pitch) |
| Gu port concentricity | ± 0.025″ | Off-center port shifts effective neck length and `f_H` |
| Wall thickness uniformity  | ± 0.030″ | A wedge-shaped wall makes the cavity asymmetric — kills bass |

---

## 7. Open questions and assumptions (red-team flagged in `risks.md`)

The design table is parametric, but the following are **derived estimates** that need first-prototype measurements to harden:

- **Padauk K = 24,438** is from the workbook's material library, derived from textbook E and ρ values. Not measured on Tony's specific stock.
- **Curved-cantilever +2.5 %** correction is a starting estimate from cylinder-shell theory at small radii. The actual factor for our specific dome rise (0.75″ on Standard) is unmeasured.
- **Wall thickness** of 0.625″ is conventional but un-tuned — Helmholtz Q depends on wall stiffness.
- **Bowl-top joint type.** Three options compete (rabbet flush, lap step, cork gasket). Rabbet flush is the working assumption; the others are validation B/C plans if the rabbet leaks.
- **Slit kerf cap of 50 % of soundboard area** is a structural rule of thumb, not a measured failure threshold.
- **Effective neck length on V1 = soundboard thickness alone.** This ignores the air "plug" oscillating just below the slit. The end correction is small for tongue-drum kerfs (kerfs are slits, not circular ports), and we're absorbing the error into the 0.88-ratio safety margin. If `f_H` measures 5–10 % low on first prototype, this is the likely cause.

---

## 8. Cross-references

- **Workbook**: [`wood-shell-tongue-drum-design-table.xlsx`](wood-shell-tongue-drum-design-table.xlsx) — single sheet, 249 rows, 190 formulas. Blue cells are inputs; everything else recomputes.
- **Concept sheet**: [`concepts/round-body-variants_concept-sheet.png`](concepts/round-body-variants_concept-sheet.png) — visual layout of all twelve cells.
- **BOM, sourcing, cut list, validation**: see the four CSVs at repo root.
- **Risks**: see [`risks.md`](risks.md) for the red-team pass with verification tests attached.
- **Wolfram exploration**: see [`wolfram-starter.wl`](wolfram-starter.wl) for the 3-DOF coupled oscillator (tongue + shell + air cavity) starter.
- **Sister repos**: [`tongue-drum/`](https://github.com/tonykoop/tongue-drum) (rectangular-prism precursor) · [`steel-tongue-drum/`](https://github.com/tonykoop/steel-tongue-drum) (steel cantilever cousin) · [`ceramic-tongue-drum/`](https://github.com/tonykoop/ceramic-tongue-drum) (slip-cast cousin) · [`ashiko-drum-workshop/`](https://github.com/tonykoop/ashiko-drum-workshop) (segmented bowl reference) · [`conga/`](https://github.com/tonykoop/conga) (stave & segmented shell reference).
- **Catalog**: [`tonykoop/instrument-maker`](https://github.com/tonykoop/instrument-maker) — orchestrating skill and Master Catalog.

## bom.csv

Starter bill of materials with part categories, quantities, drawing refs, and notes.

| part_id | description | variant | size | quantity | unit | unit_cost_usd | extended_cost_usd | critical | notes |
| --- | --- | --- | --- | --- | --- | --- | --- | --- | --- |
| SHELL-STAVE-WALNUT-T | Black Walnut stave, 4/4 stock, 6.5in length | V1+V2 | Travel 12in | 16 | each | 3.00 | 48.00 | Y | Rip from 4/4; bevel 11.25 deg both edges; sand inside to 220 |
| SHELL-STAVE-WALNUT-S | Black Walnut stave, 4/4 stock, 9.5in length | V1+V2 | Standard 16in | 16 | each | 4.50 | 72.00 | Y | Rip from 4/4; bevel 11.25 deg both edges. Recommended first prototype. |
| SHELL-STAVE-WALNUT-F | Black Walnut stave, 4/4 stock, 11.5in length | V1+V2 | Floor Pouf 20in | 16 | each | 5.50 | 88.00 | Y | Rip from 4/4; bevel 11.25 deg both edges |
| SHELL-SEG-WALNUT-T | Black Walnut segment blank, 4/4 stock, 4 in piece | V1+V2 (alt) | Travel 12in | 96 | each | 0.50 | 48.00 | N | Alt body: 8 rings x 12 segments, 15 deg miter. Skip if building stave. |
| SHELL-SEG-WALNUT-S | Black Walnut segment blank, 4/4 stock, 5 in piece | V1+V2 (alt) | Standard 16in | 96 | each | 0.65 | 62.40 | N | Alt body: 8 rings x 12 segments. Skip if building stave. |
| SHELL-SEG-WALNUT-F | Black Walnut segment blank, 4/4 stock, 6 in piece | V1+V2 (alt) | Floor Pouf 20in | 96 | each | 0.80 | 76.80 | N | Alt body: 10 rings x 12 segments. Skip if building stave. |
| BOWL-SEG-WALNUT-T | Black Walnut segment blank, 4/4 stock (graduated rings) | V3+V4 | Travel 12in | 72 | each | 0.55 | 39.60 | N | 6 rings of decreasing dia for hemisphere |
| BOWL-SEG-WALNUT-S | Black Walnut segment blank, 4/4 stock (graduated rings) | V3+V4 | Standard 16in | 96 | each | 0.65 | 62.40 | N | 8 rings of decreasing dia for hemisphere |
| BOWL-SEG-WALNUT-F | Black Walnut segment blank, 4/4 stock (graduated rings) | V3+V4 | Floor Pouf 20in | 120 | each | 0.80 | 96.00 | N | 10 rings of decreasing dia for hemisphere |
| BOWL-BLANK-WALNUT-T | Black Walnut glue-up blank for CNC bowl, 13x13x4 in | V3+V4 (alt) | Travel 12in | 1 | each | 85.00 | 85.00 | N | Alt body: 4x 1in plies. CNC 3D-surface inside and outside. |
| BOWL-BLANK-WALNUT-S | Black Walnut glue-up blank for CNC bowl, 17x17x5 in | V3+V4 (alt) | Standard 16in | 1 | each | 140.00 | 140.00 | N | Alt body: 5x 1in plies. CNC 3D-surface inside and outside. |
| BOWL-BLANK-WALNUT-F | Black Walnut glue-up blank for CNC bowl, 21x21x6 in | V3+V4 (alt) | Floor Pouf 20in | 1 | each | 210.00 | 210.00 | N | Alt body: 6x 1in plies. CNC 3D-surface inside and outside. |
| SOUNDBOARD-PADAUK-T | Padauk soundboard disc, 12.25 in OD, 0.25 in | V1+V3 | Travel 12in | 1 | each | 42.00 | 42.00 | Y | CNC-cut to OD. Slits routed before glue-up. |
| SOUNDBOARD-PADAUK-S | Padauk soundboard disc, 16.25 in OD, 0.375 in | V1+V3 | Standard 16in | 1 | each | 68.00 | 68.00 | Y | CNC-cut to OD. Slits routed before glue-up. Recommended first prototype. |
| SOUNDBOARD-PADAUK-F | Padauk soundboard disc, 20.25 in OD, 0.5 in | V1+V3 | Floor Pouf 20in | 1 | each | 98.00 | 98.00 | Y | CNC-cut to OD. Slits routed before glue-up. Consider Cedar substitute for D3 fit margin. |
| SOUNDBOARD-CEDAR-F-ALT | Western Red Cedar soundboard disc, 20.25 in OD, 0.5 in | V1+V3 alt | Floor Pouf 20in | 1 | each | 55.00 | 55.00 | N | Alternate to Padauk for tight D3 ding fit (K=29013 shortens tongues) |
| DOMEBLANK-PADAUK-T | Padauk dome glue-up blank, 13x13 in, 1.5 in thick (3 plies x 0.5) | V2+V4 | Travel 12in | 1 | each | 75.00 | 75.00 | Y | 3D-surface 0.5 in dome rise on CNC; +2.5% tongue length correction |
| DOMEBLANK-PADAUK-S | Padauk dome glue-up blank, 17x17 in, 1.5 in thick (3 plies x 0.5) | V2+V4 | Standard 16in | 1 | each | 125.00 | 125.00 | Y | 3D-surface 0.75 in dome rise on CNC; +2.5% tongue length correction |
| DOMEBLANK-PADAUK-F | Padauk dome glue-up blank, 21x21 in, 1.5 in thick (3 plies x 0.5) | V2+V4 | Floor Pouf 20in | 1 | each | 180.00 | 180.00 | Y | 3D-surface 1 in dome rise on CNC; +2.5% tongue length correction |
| DOMEBLANK-POPLAR-S | Poplar dome blank for prototype validation, 17x17 in, 1.5 in | V2+V4 proto | Standard 16in | 1 | each | 32.00 | 32.00 | N | Cheap test blank to dial in dome surfacing before Padauk |
| GUE-TITEBOND3 | Titebond III wood glue, 16oz | All | All | 2 | bottle | 18.00 | 36.00 | Y | Waterproof; 4000 psi shear. Rated for tongue-drum service. |
| RABBET-BIT-RBR | Rabbeting router bit set with bearing kit, 1/4 in shank | V1+V3 build | All | 1 | set | 42.00 | 42.00 | N | For shell rim rabbet. One-time tooling buy. |
| SLIT-BIT-UPCUT-1-8 | Solid carbide upcut spiral bit, 1/8 in, 1/4 in shank | All | All | 3 | each | 16.00 | 48.00 | Y | For tongue slits. Buy 3 (one breaks per shell). 1/4 in shank for CNC router collet. |
| BALLEND-3-4 | Ball-end mill, 3/4 in, 1/2 in shank | V2+V4 | All | 1 | each | 38.00 | 38.00 | Y | For dome 3D-surfacing on CNC |
| GU-STEPBIT-3 | Step drill bit, 1/4 to 3 in, 1/4 in increments | All | All | 1 | each | 28.00 | 28.00 | Y | For incremental gu-port enlargement during Helmholtz tuning |
| ORING-RUBBER-25 | Rubber O-ring, 2.5 in ID, 1/8 in cross-section | V1+V3 | Standard 16in | 1 | each | 2.50 | 2.50 | N | Optional gu-port lining for cleaner tone (Hapi-style) |
| ORING-RUBBER-30 | Rubber O-ring, 3 in ID, 1/8 in cross-section | V1+V3 | Floor Pouf 20in | 1 | each | 3.00 | 3.00 | N | Optional gu-port lining |
| ORING-RUBBER-20 | Rubber O-ring, 2 in ID, 1/8 in cross-section | V1+V3 | Travel 12in | 1 | each | 2.00 | 2.00 | N | Optional gu-port lining |
| FELT-FOOT-PADS | Adhesive felt floor-protection pads, 1 in dia | All | All | 4 | each | 0.50 | 2.00 | N | Mount under bowl/cylinder bottom edge |
| HANDLE-ROPE-S | Hemp rope, 0.5 in, for carry handle | All | Standard 16in+ | 4 | ft | 2.50 | 10.00 | N | Pass through two 0.5 in holes drilled in bowl side; knot inside |
| FINISH-DANISH-OIL | Watco Danish Oil, natural, qt | All | All | 1 | each | 28.00 | 28.00 | N | 3 coats, 24h between |
| FINISH-WAX-CARNAUBA | Renaissance Wax, 65ml | All | All | 1 | each | 18.00 | 18.00 | N | Final coat on shell exterior |
| SANDPAPER-SET | Sandpaper assortment 80/120/220/320/400/600 grit | All | All | 1 | set | 32.00 | 32.00 | N |  |
| TUNER-KORG-OT120 | Korg OT-120 wide-range tuner | All | All | 1 | each | 180.00 | 180.00 | N | Shop tool. Already owned in Tony's shop. Listed for cost transparency. |
| MALLET-SET | Tongue drum mallets, soft rubber heads, pair | All | All | 1 | set | 18.00 | 18.00 | N | Player accessory, included with finished drum |

## sourcing.csv

Supplier/search tracker with specs, price/date fields, lead time, substitutes, and risks.

| part_id | supplier | supplier_url | sku_or_search | lead_time_days | moq | verified_price_date | price_volatility | required_spec | search_terms | notes |
| --- | --- | --- | --- | --- | --- | --- | --- | --- | --- | --- |
| SHELL-STAVE-WALNUT-S | Bell Forest Products | bellforestproducts.com | black walnut 4/4 S2S FAS | 5 | 1 BdFt | 2026-05-07 | low | 4/4 S2S FAS black walnut, edge-jointable | black walnut 4/4 turning blanks | Recommended supplier for shell stock |
| SHELL-STAVE-WALNUT-T | Bell Forest Products | bellforestproducts.com | black walnut 4/4 S2S FAS | 5 | 1 BdFt | 2026-05-07 | low | 4/4 S2S FAS black walnut | black walnut 4/4 |  |
| SHELL-STAVE-WALNUT-F | Bell Forest Products | bellforestproducts.com | black walnut 4/4 S2S FAS | 5 | 1 BdFt | 2026-05-07 | low | 4/4 S2S FAS black walnut | black walnut 4/4 |  |
| SHELL-SEG-WALNUT-S | Cook Woods | cookwoods.com | black walnut 4/4 turning blanks | 4 | 1 | 2026-05-07 | low | Bulk segment-grade walnut blanks | walnut turning blanks 4/4 | Alt source for segmented body |
| BOWL-SEG-WALNUT-S | Cook Woods | cookwoods.com | black walnut 4/4 turning blanks | 4 | 1 | 2026-05-07 | low | Graduated-diameter ring blanks | walnut turning blanks 4/4 |  |
| BOWL-BLANK-WALNUT-S | Cook Woods | cookwoods.com | black walnut 8/4 thick stock | 10 | 1 | 2026-05-07 | medium | 5x 1in plies for CNC bowl glue-up | walnut 8/4 thick | CNC bowl alt path; verify thickness availability |
| SOUNDBOARD-PADAUK-S | Bell Forest Products | bellforestproducts.com | padauk 3/8 figured S4S | 5 | 1 BdFt | 2026-05-07 | medium | Padauk 3/8 in thickness, FAS, edge-quartersawn preferred | padauk 4/4 S4S | Critical: thickness controls tongue length. Verify 3/8 in. Quartersawn improves bend stability. |
| SOUNDBOARD-PADAUK-T | Bell Forest Products | bellforestproducts.com | padauk 1/4 S4S | 5 | 1 BdFt | 2026-05-07 | medium | Padauk 1/4 in thickness, FAS | padauk thin stock |  |
| SOUNDBOARD-PADAUK-F | Bell Forest Products | bellforestproducts.com | padauk 1/2 S4S | 5 | 1 BdFt | 2026-05-07 | medium | Padauk 1/2 in thickness, FAS | padauk 1/2 in |  |
| SOUNDBOARD-CEDAR-F-ALT | Old Growth Music | oldgrowthmusic.com | western red cedar soundboard 1/2 quartersawn | 7 | 1 | 2026-05-07 | medium | WRC 1/2 in quartersawn, A grade | western red cedar soundboard 1/2 | Alt for D3 ding fit on Floor Pouf |
| DOMEBLANK-PADAUK-S | Bell Forest Products | bellforestproducts.com | padauk 4/4 boards (3 boards required) | 5 | 1 BdFt | 2026-05-07 | medium | 3x 1/2in boards, edge-jointable | padauk 4/4 S4S | Glue 3 plies to make dome blank thicker than 1.5 in |
| DOMEBLANK-POPLAR-S | Lowe's | lowes.com | poplar 1x12 board (3 boards) | 1 | 1 | 2026-05-07 | low | 3x poplar boards 1x12x18in | poplar 1x12 | Cheap test stock for dome surfacing rehearsal |
| GUE-TITEBOND3 | Rockler | rockler.com | Titebond III 16oz | 2 | 1 | 2026-05-07 | low | PVA wood glue, waterproof, 4000 psi shear | Titebond III |  |
| RABBET-BIT-RBR | Rockler | rockler.com | rabbeting router bit set with bearing kit | 2 | 1 | 2026-05-07 | low | 1/4 in shank, multi-bearing rabbet kit | rabbeting bit set |  |
| SLIT-BIT-UPCUT-1-8 | Amana Tool | amanatool.com | 46202 1/8in upcut spiral | 3 | 1 | 2026-05-07 | low | Solid carbide, 1/8 in, 1/4 in shank, upcut spiral | Amana 46202 1/8 upcut |  |
| BALLEND-3-4 | Amana Tool | amanatool.com | 46377 3/4 ball nose | 3 | 1 | 2026-05-07 | low | 3/4 in ball nose, 1/2 in shank, solid carbide | Amana 46377 3/4 ball nose |  |
| GU-STEPBIT-3 | Amazon | amazon.com | Irwin Unibit step drill 1/4 to 3 in | 2 | 1 | 2026-05-07 | low | Step bit covering 0.25 to 3 in in 1/4 in increments | step drill bit 1/4 to 3 in |  |
| ORING-RUBBER-25 | McMaster-Carr | mcmaster.com | 9452K42 Buna-N O-ring 2-1/2 ID 1/8 thick | 2 | 1 | 2026-05-07 | low | Buna-N O-ring 2.5 ID, 1/8 cross | O-ring 2.5 in ID 1/8 |  |
| ORING-RUBBER-20 | McMaster-Carr | mcmaster.com | 9452K38 Buna-N O-ring 2 ID 1/8 thick | 2 | 1 | 2026-05-07 | low | Buna-N O-ring 2 ID, 1/8 cross | O-ring 2 in ID 1/8 |  |
| ORING-RUBBER-30 | McMaster-Carr | mcmaster.com | 9452K46 Buna-N O-ring 3 ID 1/8 thick | 2 | 1 | 2026-05-07 | low | Buna-N O-ring 3 ID, 1/8 cross | O-ring 3 in ID 1/8 |  |
| HANDLE-ROPE-S | Knot and Rope Supply | knotandrope.com | hemp rope 1/2 in 25 ft hank | 3 | 1 | 2026-05-07 | low | Natural hemp rope, 1/2 in dia | hemp rope 1/2 in |  |
| FELT-FOOT-PADS | Hardware store | local | felt floor-protection pads | 1 | 1 | 2026-05-07 | low | Adhesive 1 in felt circles | felt furniture pads 1 in |  |
| FINISH-DANISH-OIL | Rockler | rockler.com | Watco Danish Oil natural quart | 2 | 1 | 2026-05-07 | low | Penetrating oil finish, natural color | Watco Danish Oil natural quart |  |
| FINISH-WAX-CARNAUBA | Rockler | rockler.com | Renaissance Wax 65ml | 2 | 1 | 2026-05-07 | low | Microcrystalline wax for final finish | Renaissance Wax |  |
| SANDPAPER-SET | Hardware store | local | sandpaper assortment 80-600 grit | 1 | 1 | 2026-05-07 | low | Mixed grits 80/120/220/320/400/600 | sandpaper assortment |  |
| MALLET-SET | Hapi Drum | hapidrum.com | silicone tongue drum mallet pair | 5 | 1 | 2026-05-07 | low | Soft rubber/silicone heads, 8 in shaft | tongue drum mallets pair |  |

## cut-list.csv

Rough/final stock sizes, material, grain/orientation, operations, yield, and offcuts.

| variant | size | operation_id | description | stock_id | qty | length_in | width_in | thickness_in | rough_dimensions_in | final_dimensions_in | total_bdft | notes |
| --- | --- | --- | --- | --- | --- | --- | --- | --- | --- | --- | --- | --- |
| V1+V2 | Standard 16in | S-STAVE-01 | Stave blank rough cut from 4/4 walnut | SHELL-STAVE-WALNUT-S | 16 | 9.5 | 3.5 | 0.875 | 9.5 x 3.5 x 0.875 | 9.0 x 3.25 x 0.625 | 3.06 | Allows trim to final 8 in shell + 1 in waste |
| V1+V2 | Travel 12in | T-STAVE-01 | Stave blank rough cut from 4/4 walnut | SHELL-STAVE-WALNUT-T | 16 | 6.5 | 2.7 | 0.875 | 6.5 x 2.7 x 0.875 | 6.0 x 2.45 x 0.625 | 1.62 | Allows trim to final 5 in shell + 1 in waste |
| V1+V2 | Floor Pouf 20in | F-STAVE-01 | Stave blank rough cut from 4/4 walnut | SHELL-STAVE-WALNUT-F | 16 | 11.5 | 4.4 | 0.875 | 11.5 x 4.4 x 0.875 | 11.0 x 4.1 x 0.625 | 4.50 | Allows trim to final 10 in shell + 1 in waste |
| V1+V2 | All | STAVE-EDGE | Stave miter bevel both edges 11.25 deg | N/A | 16 | N/A | N/A | N/A | N/A | N/A | N/A | Tilting-arbor jig referenced off stave centerline. 11.25 deg per edge. |
| V1+V3 | Standard 16in | S-DISC-01 | Padauk soundboard disc CNC cut | SOUNDBOARD-PADAUK-S | 1 | 16.25 | 16.25 | 0.375 | 16.25 x 16.25 x 0.375 | 16.00 dia x 0.375 | 0.69 | Disc dia = shell OD. Rabbet edge 1/4 deep x 3/8 wide on inside face. CRITICAL: cut slits BEFORE rabbet. |
| V1+V3 | Travel 12in | T-DISC-01 | Padauk soundboard disc CNC cut | SOUNDBOARD-PADAUK-T | 1 | 12.25 | 12.25 | 0.25 | 12.25 x 12.25 x 0.25 | 12.00 dia x 0.25 | 0.34 |  |
| V1+V3 | Floor Pouf 20in | F-DISC-01 | Padauk soundboard disc CNC cut | SOUNDBOARD-PADAUK-F | 1 | 20.25 | 20.25 | 0.5 | 20.25 x 20.25 x 0.5 | 20.00 dia x 0.5 | 1.41 | Consider Cedar substitute for D3 fit margin |
| V2+V4 | Standard 16in | S-DOME-BLANK | Padauk dome blank glue-up 3 plies | DOMEBLANK-PADAUK-S | 3 | 17 | 17 | 0.5 | 17 x 17 x 1.5 (after glue-up) | 17 x 17 x 1.5 | 6.02 | Glue 3 plies. Cure 24 h. Flatten on jointer/planer to 1.5 in true. |
| V2+V4 | Standard 16in | S-DOME-CNC | 3D-surface dome rise 0.75 in | N/A | 1 | N/A | N/A | N/A | 17x17 blank | 16.0 dia x 1.5 max thickness, 0.75 in dome rise | N/A | 3/4 in ball-end, 0.05 in stepover. Convex top + concave underside in flip-jig. 32 microinch finish. |
| V2+V4 | Standard 16in | S-DOME-CNC-PROTO | 3D-surface dome on POPLAR test blank first | DOMEBLANK-POPLAR-S | 1 | 17 | 17 | 1.5 | 17x17x1.5 | 16.0 dia, 0.75 dome rise | N/A | De-risk dome surfacing on cheap stock before Padauk |
| V3+V4 | Standard 16in | S-BOWL-RING-01 | Hemisphere bowl ring 1 (largest, foot) | BOWL-SEG-WALNUT-S | 12 | 2.5 | 1.7 | 0.875 | 2.5 x 1.7 x 0.875 | stack height 0.75 | N/A | 15 deg miter, 12 segments per ring. Outer dia 16 in. |
| V3+V4 | Standard 16in | S-BOWL-RING-02 | Hemisphere bowl ring 2 | BOWL-SEG-WALNUT-S | 12 | 2.4 | 1.7 | 0.875 | 2.4 x 1.7 x 0.875 | stack height 0.75 cumulative 1.5 | N/A | Outer dia ~14.7 in |
| V3+V4 | Standard 16in | S-BOWL-RING-03 | Hemisphere bowl ring 3 | BOWL-SEG-WALNUT-S | 12 | 2.3 | 1.7 | 0.875 | 2.3 x 1.7 x 0.875 | stack height 0.75 cumulative 2.25 | N/A | Outer dia ~13.0 in |
| V3+V4 | Standard 16in | S-BOWL-RING-04 | Hemisphere bowl ring 4 | BOWL-SEG-WALNUT-S | 12 | 2.0 | 1.7 | 0.875 | 2.0 x 1.7 x 0.875 | stack height 0.75 cumulative 3.0 | N/A | Outer dia ~11.0 in |
| V3+V4 | Standard 16in | S-BOWL-RING-05 | Hemisphere bowl ring 5 | BOWL-SEG-WALNUT-S | 12 | 1.7 | 1.7 | 0.875 | 1.7 x 1.7 x 0.875 | stack height 0.75 cumulative 3.75 | N/A | Outer dia ~9.0 in |
| V3+V4 | Standard 16in | S-BOWL-RING-06 | Hemisphere bowl ring 6 | BOWL-SEG-WALNUT-S | 12 | 1.4 | 1.4 | 0.875 | 1.4 x 1.4 x 0.875 | stack height 0.75 cumulative 4.5 | N/A | Outer dia ~7.0 in |
| V3+V4 | Standard 16in | S-BOWL-RING-07 | Hemisphere bowl ring 7 | BOWL-SEG-WALNUT-S | 12 | 1.1 | 1.1 | 0.875 | 1.1 x 1.1 x 0.875 | stack height 0.75 cumulative 5.25 | N/A | Outer dia ~5.0 in |
| V3+V4 | Standard 16in | S-BOWL-RING-08 | Hemisphere bowl ring 8 (apex) | BOWL-SEG-WALNUT-S | 12 | 0.8 | 0.8 | 0.875 | 0.8 x 0.8 x 0.875 | stack height 0.75 cumulative 6.0 | N/A | Outer dia ~3.0 in. Cap with single disc if preferred. |
| V3+V4 | Standard 16in | S-BOWL-BASE | Hemisphere bowl base disc (alternative apex) | BOWL-SEG-WALNUT-S | 1 | 3 | 3 | 0.875 | 3 x 3 x 0.875 | 2.75 dia x 0.875 | N/A | Substitutes for ring 8 if desired |
| V1+V2 | Standard 16in | S-SHELL-LATHE | Lathe true OD/ID after stave glue-up | N/A | 1 | N/A | N/A | N/A | OD 16.5 ID 14.5 | OD 16.0 ID 14.75 | N/A | Wall thickness 0.625 in finished. Plus 1/4 deep rabbet at top rim. |
| V1+V3 | Standard 16in | S-SLITS-CNC | CNC tongue slits in soundboard | N/A | 11 | N/A | N/A | N/A | see drawing-brief | 11 slits per radial layout, 1/8 kerf | N/A | Cut from inside face of disc. Tongue lengths from design.md s4 schedule. Cut LONG by 0.030 in for tuning margin. |
| V2+V4 | Standard 16in | S-SLITS-DOME | CNC tongue slits in domed soundboard | N/A | 11 | N/A | N/A | N/A | see drawing-brief | 11 slits, 1/8 kerf | N/A | Slits cut AFTER 3D surfacing. B-axis sled OR flatten dome on sacrificial fixture. +2.5% length correction. |
| All | All | GU-PORT | Drill gu port through bowl/shell bottom | GU-STEPBIT-3 | 1 | N/A | N/A | N/A | start 0.25 in pilot | step up 0.25 in increments to 2.0/2.5/3.0 (per size) | N/A | Tune Helmholtz f_H to ~0.88 of ding f. Take f_H measurement at each step. |
| All | All | SAND | Progressive sand 80-600 grit | SANDPAPER-SET | 1 | N/A | N/A | N/A | N/A | N/A | N/A | Inside and outside. Critical: do not break tongue slit edges (chip damage = pitch shift) |
| All | All | FINISH-OIL | Apply Watco Danish Oil | FINISH-DANISH-OIL | 3 | N/A | N/A | N/A | N/A | N/A | N/A | 3 coats, 24 h between. Soundboard top only. Inside cavity unfinished (kills bass to seal). |
| All | Standard 16in+ | HANDLE-DRILL | Drill handle holes | N/A | 2 | N/A | N/A | N/A | 0.5 in dia | 0.5 in through-holes, 4 in apart | N/A | Optional. Skip on Travel size. |

## drawing-brief.md

Manufacturing drawing and technical product sketch brief.

# Drawing Brief — Wood Shell Tongue Drum

The `drawings/` folder ships dimensioned SVGs for the matrix. Each SVG follows Heifer Zephyr's standard title block (lower-right) with: drawing name, sheet number, scale, units, project (Wood Shell Tongue Drum), date, revision, drafter (Tony Koop). All dimensions in inches unless noted; metric equivalents in brackets where helpful.

## Required drawings

| File | Sheet | Title | Notes |
|---|---|---|---|
| `01-variant-matrix.svg` | 1/9 | Variant Matrix V1–V4 × Three Sizes (top-down + side profiles) | Twelve-cell layout matching `concepts/round-body-variants_concept-sheet.png` with overlaid critical dims |
| `02-v1-standard-side-section.svg` | 2/9 | V1 Standard 16″ — Side Section A-A | Recommended first prototype. Shell, soundboard, rabbet joint, cavity, gu port |
| `03-v1-standard-tongue-layout.svg` | 3/9 | V1 Standard 16″ — Tongue Field (A Kurd 11-note) | Top-down soundboard view. Slit centerlines, lengths, position numbering |
| `04-shell-stave-template.svg` | 4/9 | Stave Template — All Sizes (full-size cutting layout) | One stave per size; bevel callouts at 11.25°; centerline marked |
| `05-shell-segment-template.svg` | 5/9 | Segment Template — All Sizes (alt body construction) | 15° miter, 12-per-ring; 8 rings on Std, 6 on Travel, 10 on Floor |
| `06-rabbet-joint-detail.svg` | 6/9 | Bowl-Top Rabbet Joint — Section B-B (3× scale) | ¼″ × ⅜″ rabbet; soundboard slip-fit; glue line; air-seal callout |
| `07-dome-toolpath.svg` | 7/9 | V2/V4 Dome Surfacing — CNC Toolpath Schematic | Convex top + concave bottom; 0.05″ stepover; flip-jig datum pins |
| `08-bowl-segment-stack.svg` | 8/9 | V3/V4 Hemisphere Bowl — Ring Stack Section | 8 rings of decreasing dia; lathe-true profile overlay |
| `09-gu-port-tuning-progression.svg` | 9/9 | Gu Port Tuning — Step-Drill Progression | 0.25″ pilot → step increments → final size; f_H expected at each step |

## Drawing conventions

- **Datums:** shell bottom plane = primary horizontal datum (Z=0); axis of revolution = primary vertical datum.
- **Tolerances:** ± 0.020″ default; tighter where called out (rim flatness ± 0.005″, slit kerf width ± 0.005″, miter angle ± 0.1°).
- **Cross-section hatching:** oak-grain pattern at 45° for wood; cross-hatch at 90° for void/cavity.
- **Title block size:** 4″ × 1.5″ at 1:1 scale.
- **Critical dimensions:** bold, with leader lines pointing to the dimensioned feature. Helmholtz-driving dimensions (cavity volume parameters) are double-boxed.
- **Material color cues** (when polychrome): Walnut = warm brown fill, Maple = pale cream, Cherry = pink-brown, Padauk = orange-red. Used in sheet 5 segment-stack diagrams for the diamond pattern.

## Critical dimensions (must appear on the drawings)

| Dimension | Drawing | Value (Standard 16″ V1) | Tolerance |
|---|---|---|---|
| Shell OD | 02 | 16.000″ | ± 0.020″ |
| Shell ID | 02 | 14.750″ | ± 0.030″ |
| Shell wall thickness | 02 | 0.625″ | ± 0.030″ |
| Shell height | 02 | 8.000″ | ± 0.030″ |
| Soundboard OD | 02, 03  | 16.000″ | ± 0.010″ |
| Soundboard thickness | 02, 03  | 0.375″ | ± 0.005″ |
| Rabbet depth | 02, 06  | 0.250″ | ± 0.005″ |
| Rabbet width | 02, 06  | 0.375″ | ± 0.005″ |
| Tongue length (ding A3) | 03 | 6.454″ | + 0.030″ initial |
| Tongue width | 03 | 1.250″ | ± 0.020″ |
| Slit kerf width | 03 | 0.125″ | ± 0.005″ |
| Gu port diameter (final) | 02, 09  | 2.500″ nominal | tuned in shop |
| Stave miter angle | 04 | 11.25° | ± 0.1° |

## Sheet 03 — tongue layout details

The 11-tongue A Kurd field uses a **zigzag-ascending** pattern: ding centered, then tongues 1, 2, 3, … alternating left and right at progressively greater radii from the ding. This matches steel-tongue-drum convention and gives the player an ergonomic two-handed reach.

Position grid (radial coords, ding = origin):

| # | Note | r (in from ding centerline) | θ (deg) | length (in) |
|---|---|---|---|---|
| Ding | A3 | 0 | — | 6.454 |
| 1 | E4 | 4.0 | 60 | 5.273 |
| 2 | F4 | 4.0 | -60 | 5.123 |
| 3 | G4 | 5.5 | 90 | 4.835 |
| 4 | A4 | 5.5 | -90 | 4.564 |
| 5 | B4 | 6.5 | 120 | 4.308 |
| 6 | C5 | 6.5 | -120 | 4.185 |
| 7 | D5 | 6.0 | 30 | 3.950 |
| 8 | E5 | 6.0 | -30 | 3.728 |
| 9 | G5 | 6.5 | 150 | 3.419 |
| 10 | A5 | 6.5 | -150 | 3.227 |

(These radial coords are derived estimates for the layout drawing; SolidWorks parametric placement against shell radius will refine them. The radii are kept ≤ 6.5″ to leave wall clearance ≥ 1.0″ on the 16″ shell.)

## Status

These SVG files are listed in this brief as the *intended* drawing set. The repo currently ships the brief and the source workbook; SVGs are emitted by `scripts/generate_drawings.py` (in the parent `instrument-maker` skill) reading the workbook as its parametric source. Per the v4 deliverable list, drawings are auto-generated and refreshed when the workbook changes — they are not hand-drawn artifacts.

A placeholder hero drawing — `drawings/00-hero-v1-standard.svg` — ships in this repo at first commit so cross-references resolve. It is replaced in production by sheet 02 above.

## assembly-manual.md

Shop-facing sequence, tools, fixtures, safety, tuning, finishing, and maintenance notes.

# Wood Shell Tongue Drum — Assembly Manual

Covers all four manufacturing variants (V1, V2, V3, V4) across three sizes (Travel 12″, Standard 16″, Floor Pouf 20″). Steps shared across variants are written once with branching notes where they diverge. Read `design.md` first — this manual assumes you have the parametric workbook open for size-specific dimensions and the recommended first prototype is **V1 Cylinder + Flat Top, Standard 16″, A Kurd**.

---

## Phase 0 — Shop preparation

1. Acclimate stock 2 weeks in the shop (60–70 °F, 40–55 % RH). Padauk and Black Walnut both move with seasonal humidity; soundboard cup or warp will scrap a tongue field that was previously in tune.
2. Joint and plane stock to nominal dimensions ± 0.005″.
3. Verify your saw kerf width with a test cut. The cut-list assumes a known kerf — measure yours before sizing rough stock.
4. Check the lathe — main spindle runout < 0.003″ TIR, tailstock alignment within 0.005″. A round shell amplifies any mounting wobble.
5. Verify CNC router calibration: a stock-thickness probe and tool-length probe both within ± 0.002″. Tongue slits depend on consistent depth.

---

## Phase 1A — Cylinder shell (V1, V2)

The cylinder is the *recommended* body for the first prototype. Two construction paths share Phases 1A.4 onward.

### 1A.1 Stave path (preferred for first build)

1. Rough-cut 16 staves to outline + 1/8″ on each side. Stock dimensions per `cut-list.csv` (Standard 16″: 9.5″ × 3.5″ × 0.875″).
2. Bevel both edges to 11.25° using a tilting-arbor jig referenced off the stave centerline (NOT off either edge — the stave is symmetric only when freshly ripped). Test on a sacrificial board first; verify the assembled circle closes by dry-clamping 4 staves and checking the included angle.
3. Sand the inside face to 220 grit. The inside is permanent and not turnable after glue-up.

### 1A.2 Segmented path (alternative for polychrome aesthetic)

1. Rough-cut 96 segments (8 rings × 12 segments) at 15° miter on a table-saw miter sled.
2. Stack rings on a lazy-susan jig for sequential glue-up. Each ring closes independently before stacking.
3. Diamond / 5-10-5 species patterns (Walnut + Maple + Cherry) read beautifully on 16″ Ottoman size — see `drawing-brief.md` §08 for layout templates.

### 1A.3 Stave glue-up (path A)

1. Lay all 16 staves flat on a tarp, edges touching, in their final order. Tape across all joints with strong masking tape.
2. Roll the assembly into a tube. Apply a thin even bead of Titebond III to every edge.
3. Re-roll, close to a full cylinder.
4. Wrap with three nylon ratchet straps OR run two large hose clamps. Do not over-tighten — squeeze-out should bead, not gush.
5. Stand the tube on a flat plate (¾″ MDF works) and check for end-square with a framing square. Adjust strap tension to pull any out-of-round into round.
6. Cure 24 hours.

### 1A.4 Lathe truing (both paths converge)

1. Mount a faceplate to a 3″ waste block. Glue the waste block to a ¼″ ply disk slightly larger than the shell ID.
2. Slide the shell over the disk; insert a soft-rubber expansion plug at the open end with the tailstock for support.
3. Turn the OD true to the design diameter (e.g., 16.00″ for Standard). Wall thickness target: 0.625″ finished.
4. Reverse-mount and turn the rim end. The rim must be planar (± 0.005″ TIR) — this is the airtight bond surface for the soundboard.
5. Cut a ¼″-deep × ⅜″-wide rabbet in the inside of the rim, sized to receive the soundboard disc (see `cut-list.csv` row S-DISC-01 for the disc dimensions).

---

## Phase 1B — Hemisphere bowl (V3, V4)

Pick one of two construction paths. Segmented is recommended for the first hemisphere build.

### 1B.1 Segmented bowl path

1. Rough-cut graduated rings per `cut-list.csv` rows S-BOWL-RING-01 through S-BOWL-RING-08 (Standard 16″: 8 rings of decreasing diameter from 16″ at the rim to ~3″ at the apex).
2. Glue each ring closed on the lazy-susan jig before stacking.
3. Stack rings with a centering jig (a vertical dowel through ring centers) and glue with Titebond III. Cure 24 h between layers.
4. Mount the assembled bowl on a faceplate with a thick waste block.
5. Lathe-true the outside to a parabolic profile (within 1/16″ of true sphere is acceptable — the lathe finishes any micro-step). Lathe-true the rim flat (± 0.005″ TIR).

### 1B.2 CNC-carved bowl path (alternative; high material waste)

1. Glue up a thick blank: 5 plies of 1″ Black Walnut for Standard 16″.
2. CNC 3D-surface the outside convex profile with a ¾″ ball-end bit; 0.05″ stepover for ≤ 32 µin surface finish.
3. Flip-jig the blank with datum pins; 3D-surface the inside concave profile.
4. Trim rim flat on a router table or lathe; verify ± 0.005″ TIR.

---

## Phase 2 — Soundboard (variant-dependent)

### 2A — Flat soundboard (V1, V3)

1. Cut Padauk disc to OD per `cut-list.csv` (Standard 16″: 16.25″ rough → 16.00″ final).
2. Mark the tongue layout on the *inside* face of the disc. Use the layout template in `cnc/README.md`.
3. CNC-route the tongue slits with a 1/8″ upcut spiral. Cut from inside face. Tongue lengths from `design.md` §4 — cut LONG by 0.030″ for tuning margin.
4. Sand the soundboard to 320 grit. **Do not break the slit edges** — chip damage causes pitch shifts that are difficult to recover.
5. Apply Watco Danish Oil to the *outside* face only. Three coats, 24 h between. Inside cavity stays unfinished (sealing the cavity damps the bass).

### 2B — Domed soundboard (V2, V4)

1. Glue up a 3-ply blank per `cut-list.csv` row S-DOME-BLANK (Standard 16″: 3 × 0.5″ Padauk = 1.5″ thick × 17″ × 17″).
2. **Rehearse on poplar first.** Cut a poplar test blank with the same dome profile (S-DOME-CNC-PROTO). Verify the toolpath produces a clean parabolic surface with no scallop steps before committing the Padauk blank.
3. 3D-surface the convex top with a ¾″ ball-end bit, 0.05″ stepover. Dome rise per size preset (Standard: 0.75″).
4. Flip the blank into a flip-jig with datum pins. 3D-surface the concave underside (matches OD rim for clean rabbet seat).
5. **Validate the curved cantilever multiplier.** Cut ONE tongue at the predicted length × 1.025 multiplier. Tap-test, measure pitch with a Korg OT-120. Back-solve the actual multiplier (`L_measured² × f / (K × t)` returns the new multiplier). Apply this measured multiplier to the remaining 10 tongue layouts before any further cutting.
6. Cut the remaining 10 tongues with the validated multiplier. Cut LONG by 0.030″ for tuning margin.
7. Sand and finish per Phase 2A steps 4–5.

---

## Phase 3 — Bowl-top assembly

The bowl-to-soundboard joint is **acoustically critical**: an air leak here destroys the Helmholtz Q. Any of three joint geometries can work; the rabbet is the working assumption.

### 3.1 Rabbet joint (preferred)

1. Verify the shell rim rabbet (cut in Phase 1A.4 / 1B): ¼″ deep × ⅜″ wide, ± 0.005″.
2. Verify the soundboard slip-fits into the rabbet with 0.005″ clearance — tight enough for a PVA bond, loose enough that you don't pry the rim apart on insertion.
3. Apply a uniform thin bead of Titebond III in the rabbet. Drop the soundboard in flush.
4. Apply two cauls (top and bottom) with band clamps OR a vacuum bag. Cure 24 h.

### 3.2 Lap step joint (backup)

If the rabbet leaks under puff-test (Phase 6), step-lap a thin (1/16″) Padauk veneer overlapping the rabbet seam from inside. Glue with Titebond III.

### 3.3 Cork gasket (last-resort backup)

If both rabbet and lap-step leak, install a 1/16″ cork ring in the rabbet under the soundboard. Compresses for an airtight seal but adds compliance that may damp the Helmholtz Q.

---

## Phase 4 — Gu-port tuning

The gu port is your primary Helmholtz tuning knob. It is drilled **last** and **deliberately undersized**, then opened up incrementally while measuring `f_H`. Opening the port raises `f_H`; adding a restrictor/liner or lengthening the port neck lowers `f_H`.

1. Drill a ¼″ pilot hole through the shell/bowl bottom, centered (verify ± 0.025″).
2. Place a small microphone above the port. Puff gently across the port edge (like blowing across a bottle top). Record the resonance frequency in REW or Spectroid.
3. Use a step-drill to enlarge the port in ¼″ increments. Re-measure `f_H` at each step. Stop when `f_H ≈ 0.88 × f_ding` (Standard 16″ V1: target ≈ 195 Hz).
4. **If the cavity is high** (ratio > 1.2 before the port reaches the target diameter): stop drilling. Lower `f_H` with a removable restrictor, port sleeve, longer effective neck, or revised chamber volume on the next build.
5. **If the cavity is low** (ratio < 0.8 even at the maximum safe port diameter): the chamber/neck model is under-predicting the port area required. Document the measured curve, do not keep enlarging into the rim margin, and re-evaluate the V2/V4 cavity model.

Optional: install a Buna-N O-ring in the finished port (BOM rows ORING-RUBBER-*) for a Hapi-style cleaner tone. Not required.

---

## Phase 5 — Tongue tuning

Tongues are cut LONG. Each one is tuned by filing the tongue tip (which shortens the effective length, *raising* the pitch). You cannot lower a tongue's pitch by filing — if a tongue measures sharp of target by more than 50 cents at first cut, that tongue is scrap.

1. Set up the drum on a soft surface (foam, blanket).
2. Strike each tongue at its tip with a soft mallet. Record pitch with a Korg OT-120 (or a phone tuner with cents resolution).
3. Compare to `validation.csv` predicted column.
4. For tongues > 5 cents flat: do nothing yet (let the tongue settle for 48 h after cutting before tuning).
5. For tongues > 5 cents sharp: file the tongue tip with a flat sanding bar (320 grit). Test pitch every 3–4 strokes. Each 0.030″ removed from the tip raises pitch by ~10–15 cents.
6. For tongues > 30 cents flat after 48 h settling: file the *underside* of the tongue at the base (thinning the cantilever lowers stiffness, which lowers pitch). This is a recovery move; ideally tongues are cut long enough to never need it.
7. Final tuning: ± 5 cents of target on all 11 tongues.
8. Document final measurements in `validation.csv`.

---

## Phase 6 — Validation and acceptance

Run the full validation loop before declaring the build complete:

| Check | Tool | Acceptance band |
|---|---|---|
| All 11 tongues to target | Korg OT-120 | ± 5 cents per tongue |
| Helmholtz coupling ratio | mic + spectrum | 0.80 ≤ f_H/f_ding ≤ 1.20 |
| Bowl-top airtight seal | smoke or vacuum test | no visible leakage at rabbet |
| Bearing-edge planarity | dial indicator | ± 0.005″ TIR |
| Wall thickness uniformity | calipers, 8 points | ± 0.030″ from nominal |
| Soundboard thickness uniformity| calipers, 9-pt grid | ± 0.005″ |
| Slit kerf width | feeler gauge, 5-pt | 0.125″ ± 0.005″ |
| Sustain T60 | REW software | 1.5 s ≤ T60 ≤ 4.0 s |
| A4 = 440.0 Hz sanity | tongue 4 measurement | within 5 cents of 440 Hz |

Record measured values in `validation.csv`. If A4 measures off > 5 cents, back-compute the actual K-constant of your specific stock (`K_actual = f × L² / t`) and update the per-family corrections database.

---

## Phase 7 — Finish and presentation

1. Apply 3 coats Watco Danish Oil to the shell exterior (24 h between coats).
2. Apply Renaissance Wax to the shell exterior (final coat, buffed).
3. Apply 3 coats Watco Danish Oil to the soundboard *outside* face only.
4. Adhere felt foot pads to the shell bottom (4 pads at 90° spacing).
5. Optional: install hemp carry handle (Standard size and above).
6. Photograph per `photo-shotlist.md`.
7. Tag the drum with maker plate (interior) and update the catalog entry in the master workbook.

---

## Branching summary

| Phase | V1 (Cyl + Flat) | V2 (Cyl + Dome) | V3 (Hemi + Flat) | V4 (Hemi + Dome) |
|---|---|---|---|---|
| 1 | 1A — cylinder | 1A — cylinder | 1B — bowl | 1B — bowl |
| 2 | 2A — flat | 2B — dome | 2A — flat | 2B — dome |
| 3 | 3.1 rabbet | 3.1 rabbet | 3.1 rabbet | 3.1 rabbet |
| 4 | 2.5″ port | larger measured port or sleeve experiment | 2.5″ port | larger measured port or sleeve experiment |
| 5 | flat tuning | flat + dome correction | flat tuning | flat + dome correction |
| 6 | full validation | full validation + dome multiplier check | full validation | full validation + dome multiplier check |
| 7 | standard finish | standard finish | standard finish  | standard finish  |

## validation.csv

Target/measured values, tolerance, environment, result, and tuning/build action log.

| size | variant | target | parameter | predicted_value | measured_value | unit | cents_error | measurement_date | instrument | notes |
| --- | --- | --- | --- | --- | --- | --- | --- | --- | --- | --- |
| Standard 16in | V1 | ding fundamental | frequency | 220.00 |  | Hz |  |  | Korg OT-120 | A3 ding (MIDI 57). Tunable band A3 +/- 30 cents. Recommended first prototype. |
| Standard 16in | V1 | tongue 1 (E4) | frequency | 329.63 |  | Hz |  |  | Korg OT-120 | E4 tongue. Cut 0.030 in long; file to pitch. |
| Standard 16in | V1 | tongue 2 (F4) | frequency | 349.23 |  | Hz |  |  | Korg OT-120 |  |
| Standard 16in | V1 | tongue 3 (G4) | frequency | 392.00 |  | Hz |  |  | Korg OT-120 |  |
| Standard 16in | V1 | tongue 4 (A4) | frequency | 440.00 |  | Hz |  |  | Korg OT-120 | Reference pitch — should land dead-on without filing |
| Standard 16in | V1 | tongue 5 (B4) | frequency | 493.88 |  | Hz |  |  | Korg OT-120 |  |
| Standard 16in | V1 | tongue 6 (C5) | frequency | 523.25 |  | Hz |  |  | Korg OT-120 |  |
| Standard 16in | V1 | tongue 7 (D5) | frequency | 587.33 |  | Hz |  |  | Korg OT-120 |  |
| Standard 16in | V1 | tongue 8 (E5) | frequency | 659.26 |  | Hz |  |  | Korg OT-120 |  |
| Standard 16in | V1 | tongue 9 (G5) | frequency | 783.99 |  | Hz |  |  | Korg OT-120 |  |
| Standard 16in | V1 | tongue 10 (A5) | frequency | 880.00 |  | Hz |  |  | Korg OT-120 |  |
| Standard 16in | V1 | Helmholtz cavity | frequency | 194.57 |  | Hz |  |  | microphone + spectrum | Cavity port puff test. Target 0.88 x ding. If measures > 230 Hz, port too large; < 175 Hz, port too small. |
| Standard 16in | V1 | coupling ratio | f_H/f_ding | 0.88 |  | ratio |  |  | computed | Acceptance band 0.80-1.20 for coupled regime |
| Standard 16in | V1 | sustain T60 | RT decay -60dB | 2.5 |  | seconds |  |  | REW software | Acceptance 1.5-4.0 s. Wood tongue drums typically more sustained than rectangular due to Helmholtz. |
| Standard 16in | V1 | bearing-edge planarity | TIR | 0.005 |  | inches |  |  | dial indicator | Lathe-tested. Acceptance +/- 0.005 in. |
| Standard 16in | V1 | wall thickness uniformity | 8 points around shell | 0.625 |  | inches |  |  | calipers | +/- 0.030 in acceptance. Wedge-shaped wall = asymmetric cavity = killed bass. |
| Standard 16in | V1 | soundboard thickness uniformity | 9-pt grid | 0.375 |  | inches |  |  | calipers | +/- 0.005 in acceptance. Affects tongue pitch via sqrt(t). |
| Standard 16in | V1 | slit kerf width | 5-point sample | 0.125 |  | inches |  |  | feeler gauge | +/- 0.005 in. Wider kerfs = lower Q. |
| Standard 16in | V1 | gu-port concentricity | distance from bowl center | 0 |  | inches |  |  | calipers | +/- 0.025 in. Off-center port shifts effective neck length. |
| Standard 16in | V1 | bowl-top airtight seal | pressurization test | pass |  | pass/fail |  |  | vacuum test or smoke | No air leakage at the rabbet joint. Critical for Helmholtz Q. |
| Standard 16in | V1 | glue-line shear (24h cure) | destructive sample test | 4000 |  | psi |  |  | test fixture | Titebond III rated 4000 psi. Test on a sacrificial sample stave joint, not the drum itself. |
| Travel 12in | V1 | ding fundamental | frequency | 293.66 |  | Hz |  |  | Korg OT-120 | D4 ding (MIDI 62). Build last after Standard is dialed in. |
| Travel 12in | V1 | Helmholtz cavity | frequency | 321.53 |  | Hz |  |  | microphone + spectrum | Predicted ratio 1.09 — at upper edge of coupled band. If measurement rises above 1.20 x ding, lower f_H with a restrictor/liner or smaller effective port on the next template. |
| Travel 12in | V1 | coupling ratio | f_H/f_ding | 1.09 |  | ratio |  |  | computed | Tight; acceptance 0.80-1.20. Watch the Helmholtz tuning carefully. |
| Floor Pouf 20in | V1 | ding fundamental | frequency | 146.83 |  | Hz |  |  | Korg OT-120 | D3 ding. WARNING: ding tongue length (9.12 in) exceeds 9 in cap by 0.12 in. Use Cedar (8.34 in fits) or raise ding to D#3. |
| Floor Pouf 20in | V1 | Helmholtz cavity | frequency | 144.69 |  | Hz |  |  | microphone + spectrum | Predicted ratio 0.99 — perfectly coupled. |
| Floor Pouf 20in | V1 | coupling ratio | f_H/f_ding | 0.99 |  | ratio |  |  | computed | Sweet spot. |
| Standard 16in | V2 | ding fundamental | frequency | 220.00 |  | Hz |  |  | Korg OT-120 | A3 ding. Domed top requires +2.5% tongue length correction. |
| Standard 16in | V2 | curved-cantilever correction | measured/predicted ratio | 1.025 |  | multiplier |  |  | Korg OT-120 | VALIDATE EMPIRICALLY: tap one tongue at L = sqrt(K*t/f)*1.025, measure pitch, back-solve actual factor before cutting all 11. |
| Standard 16in | V2 | Helmholtz cavity | frequency | 133.48 |  | Hz |  |  | microphone + spectrum | Predicted ratio 0.61 — UNDER-COUPLED. Larger port area raises f_H; estimated lower coupled edge is near 3.3 in, with 0.95 x ding near 3.9 in. Validate before committing Padauk. |
| Standard 16in | V3 | ding fundamental | frequency | 220.00 |  | Hz |  |  | Korg OT-120 | A3 ding, hemisphere bowl, flat top. |
| Standard 16in | V3 | Helmholtz cavity | frequency | 238.30 |  | Hz |  |  | microphone + spectrum | Predicted ratio 1.08 — coupled. Hemisphere has smaller volume than cylinder so f_H higher. |
| Standard 16in | V3 | coupling ratio | f_H/f_ding | 1.08 |  | ratio |  |  | computed | Coupled. |
| Standard 16in | V4 | ding fundamental | frequency | 220.00 |  | Hz |  |  | Korg OT-120 |  |
| Standard 16in | V4 | Helmholtz cavity | frequency | 161.12 |  | Hz |  |  | microphone + spectrum | Predicted ratio 0.73 — UNDER-COUPLED. Combine V2 + V3 effects. |
| All | All | A4 = 440 Hz sanity | reference pitch | 440.00 |  | Hz |  |  | Korg OT-120 | Sanity check: tongue 4 (A4) is reference pitch — should land dead-on. If off > 5 cents, K-constant of stock differs from library. |
| All | All | Padauk K calibration | measured K constant | 24438 |  | K imperial |  |  | back-computed from tongue measurement | After tuning, back-compute K = f * L^2 / t. Update library if measured value differs > 5% from 24438. |
| All | V2+V4 | curved cantilever K-effective | measured/predicted ratio | 1.025 |  | multiplier |  |  | first dome prototype | Per-family corrections database entry. Will propagate to V2/V4 sibling packets. |

## supplier-rfq.md

Supplier email/request-for-quote starter.

# Supplier RFQ — Wood Shell Tongue Drum (Q2 2026 batch)

Heifer Zephyr Instruments is producing a wood shell tongue drum series across four manufacturing variants (V1–V4) and three sizes (Travel 12″, Standard 16″, Floor Pouf 20″). The recommended first prototype is **V1 Cylinder + Flat Top, Standard 16″** — that build is the priority for this RFQ. Variants V2–V4 are queued for sequential phases and should be quoted alongside but not necessarily shipped together.

Verified pricing date for all line items: **2026-05-07**. All prices are starting-point estimates; supplier confirmation requested before commit.

## Lumber

| Need | Quantity (per drum) | Specification |
|---|---|---|
| Black Walnut, 4/4, S2S, FAS | ~3 BdFt (Standard 16″) | Edge-jointable for stave glue-up; clear grain |
| Black Walnut, 4/4, S2S, FAS | ~5 BdFt (segmented bowl) | Bulk segment grade; 12-segment ring stack |
| Padauk, 4/4 or 1/2, S4S | ~1 BdFt | Soundboard thickness controls tongue length — hold 3/8″ ± 1/64″ on Standard. Quartersawn preferred for bend stability. |
| Padauk, 4/4 boards (3 ea, glue-up) | ~3 BdFt (V2/V4 dome only)  | For glue-laminated dome blank; 1.5″ total thickness |
| Western Red Cedar, 1/2 quartersawn | ~1 BdFt (Floor Pouf alt) | Soundboard alternate for D3 ding fit on Floor Pouf 20″ |
| Poplar, 1× boards | ~3 BdFt (V2/V4 prototype)  | Cheap test stock for dome surfacing rehearsal |

**Preferred suppliers:** Bell Forest Products (primary), Cook Woods (segment blanks). Local pickup acceptable if equivalent grade.

## Tooling

For shop and CNC tooling. Most are one-time buys; the 1/8″ upcut spirals are consumables (one breaks per shell).

| Item | Qty | Source |
|---|-----|---|
| Solid carbide upcut spiral 1/8″ × 1/4″ shank | 3 | Amana 46202 (preferred) |
| Ball-end mill 3/4″ × 1/2″ shank (V2/V4 dome surfacing) | 1 | Amana 46377 |
| Rabbeting bit set with bearing kit, 1/4″ shank | 1 | Rockler |
| Step drill bit, 1/4″–3″ in 1/4″ increments | 1 | Irwin Unibit (Amazon) |

## Hardware and consumables

| Item | Qty (per drum) | Notes |
|---|---|---|
| Titebond III wood glue, 16 oz | 1 (shared 2 drums) | Waterproof; 4000 psi shear |
| Watco Danish Oil, natural, qt | 1 (shared 4 drums) | 3-coat finish |
| Renaissance Wax, 65 ml | 1 (shared 4 drums) | Final shell finish |
| Sandpaper assortment 80/120/220/320/400/600 grit | 1 set | Local hardware store |
| Buna-N O-ring (sized to gu port) | 1 | Optional Hapi-style port lining |
| Adhesive felt floor-protection pads, 1″ dia | 4 | Local hardware |
| Hemp rope, 1/2″, 4 ft | 1 (Std/Floor)  | Optional carry handle |

## Skin/heads

**N/A** — this is a slit-tongue idiophone, not a membrane drum. No skins required. (Distinguishes this design from the conga and ashiko families which use mule or LP heads.)

## Acoustic test gear (one-time shop equipment)

These are workshop instruments, not per-drum consumables. Listed for budget transparency.

| Item | Qty | Notes |
|---|-----|---|
| Korg OT-120 wide-range chromatic tuner | 1 | Already owned |
| Microphone + REW software for Helmholtz | 1 | Phone + free Spectroid app acceptable |

## Lead-time summary

| Category | Typical lead time |
|---|---|
| Lumber (Bell Forest) | 5 days |
| Lumber (Cook Woods) | 4 days |
| Tooling (Amana, Rockler)| 2–3 days |
| Hardware (McMaster) | 2 days |
| Local hardware | same-day |

Critical path for first prototype: lumber + slit bits. Order both at start of Phase 1; tooling can be ordered immediately on project kickoff.

## Quote request

Please confirm:

1. Current per-board-foot price on Black Walnut 4/4 FAS (we want clear, edge-jointable stock — figured grade is *not* required for this design and adds cost without acoustic benefit).
2. Padauk availability in 3/8″ thickness *as a stock item*. If only 4/4 is stocked, we will glue / resaw — quote both options.
3. Lead-time guarantees for Q2 2026.
4. Volume-discount thresholds — we may run multiple drums (V1 first, V2 reuses the same shell) over the next 12 months.

Heifer Zephyr Instruments
Tony Koop
[github.com/tonykoop/wood-shell-tongue-drum](https://github.com/tonykoop/wood-shell-tongue-drum)

## visual-bom-brief.md

Art direction for an image-forward visual BOM.

# Visual BOM — Photo shotlist for the BOM hero plate

A Visual BOM lays out every part for one drum on a flat surface against a clean backdrop and labels the parts with quantities, IDs, and final cost. The result is a single hero-style photograph that serves as the cover image for the build-log site, the printable shop packet, and the recruiter-facing deck.

## Hero shot — V1 Standard 16″ (recommended first prototype)

**Frame:** top-down, 4:5 portrait orientation, shop-tabletop or seamless butcher-paper backdrop (warm neutral — kraft or off-white).

**Lighting:** one diffused softbox at 45° camera-left, slight bounce-fill from camera-right.

**Layout** (top-down grid, parts arranged left-to-right by build phase):

```
Row 1 — Body
  [16 stave blanks fanned in a circle]   [shell after lathe-turning, set on rim]   [rabbet detail close-up]

Row 2 — Soundboard
  [Padauk disc with slit pattern routed]  [1/8" upcut spiral bit]  [tongue length schedule card]

Row 3 — Tuning hardware (sparse)
  [step drill bit]  [Buna-N O-ring]  [Korg OT-120 tuner]

Row 4 — Finish + accessory
  [Watco Danish Oil]  [Renaissance Wax]  [pair of mallets]  [felt foot pads]
```

Caption: `Wood Shell Tongue Drum — V1 Cylinder + Flat Top, Standard 16″ — Heifer Zephyr Instruments — Total BOM ~$XXX`. Plug the actual rolled-up sum from `bom.csv` extended_cost column for V1+Standard rows.

## Detail shots — shared across variants

1. **Stave miter** — close-up of one stave edge showing 11.25° bevel against a digital protractor. Side-lit to emphasize the angle.
2. **Tongue slit** — extreme close-up of one slit-and-tongue, top-down, showing kerf width and the slit terminus geometry. Side-lit.
3. **Rabbet joint** — section view of the rabbet with the soundboard half-engaged. Highlights the air-seal surfaces.
4. **Gu port** — bottom view of the shell with the step-drilled port; ruler in frame for scale.
5. **Bowl ring stack** (V3/V4 only) — one of the graduated rings photographed flat against the backdrop, showing 12-segment construction with the 15° miters.
6. **Domed soundboard** (V2/V4 only) — 3/4 angle showing the dome rise on the Padauk blank after CNC surfacing; light raking across the curve to show the parabolic profile.

## Variant comparison shot (after Phases 1–4)

After all four variants are built, one final group shot:

- V1, V2, V3, V4 in a row at Standard 16″ size, soundboards facing camera, 3:2 landscape orientation.
- Backdrop: dark-gray seamless or wood floor.
- Lighting: two softboxes at 45° each side, slightly above eye level.
- Caption: `Heifer Zephyr Wood Shell Tongue Drum — V1 → V4 Family — All Standard 16″, A Kurd`.

This becomes the hero on the build-log site (`site/index.html`) once all four variants ship.

## Process / progression montage

A 4 × 2 grid of in-shop process shots illustrating the build sequence:

1. Stave glue-up under ratchet straps
2. Lathe-truing the OD
3. CNC routing the tongue slits in Padauk soundboard
4. Rabbet joint assembly with cauls
5. Gu-port step-drilling with mic + tuner in frame
6. Tongue tuning with sanding bar and Korg
7. Final finish — Danish Oil application
8. Hero shot of the finished V1 Standard

This montage anchors the build-log site mid-page and serves as the printable packet's "build workflow" foldout.

## Constraints

- All photographs must show **the actual instrument and parts**, not concept renders. The concept sheet in `concepts/` is for ideation; the BOM hero is for documentation.
- Dimensions in caption text must match `bom.csv` and `cut-list.csv` exactly. Any drift is a packet-validation failure.
- No props that aren't part of the BOM. Parts should look like a clean inventory, not a styled lifestyle shot.
- Shot list updates: as builds complete, replace each Required cell with a real path (`images/IMG-XXXX.jpg`) and mark Status = Captured.

## wolfram-starter.wl

Wolfram starter for physics, optimization, visualization, and validation.

```wolfram
(* ::Package:: *)

(* Wood Shell Tongue Drum — Acoustic Physics Starter
   Heifer Zephyr Instruments — Tony Koop
   Open in Wolfram Desktop or Wolfram Cloud.

   This notebook implements the 3-DOF coupled-oscillator picture for a
   slit-tongue idiophone with an enclosed Helmholtz cavity. The three
   oscillators are:

     1. The tongue (flat or curved cantilever, Euler-Bernoulli).
     2. The shell wall (cylindrical or hemispherical).
     3. The enclosed air cavity (Helmholtz resonator).

   The tongue couples to the shell through the rabbet boundary; the
   shell couples to the air cavity through wall compliance; the air
   cavity couples back to the tongue through pressure on the
   underside of the slit field. The eigenvalue split predicts how much
   the wood shell adds sustain compared to a rigid-walled tongue drum.
*)

(* === 1. Inputs (edit me) === *)

(* All dimensions in inches; conversions to SI happen below. *)

(* Recommended first prototype: V1 Standard 16in *)
shellOD       = 16.0;          (* shell outer diameter *)
shellHeight   = 8.0;           (* cylinder body height *)
shellThk      = 0.625;         (* wall thickness, finished *)
sbThk         = 0.375;         (* soundboard thickness (Padauk) *)
sbWood        = "Padauk";      (* one of Padauk, Cherry, Walnut, Maple, Cedar *)
shellWood     = "BlackWalnut"; (* shell material *)
guPortDia     = 2.5;           (* gu port diameter, initial preset *)
domeRise      = 0.0;           (* 0 for flat top, 0.75 for V2 Std *)

dingMidi      = 57;            (* A3 *)
nTongues      = 11;
tongueWidth   = 1.25;
slitKerf      = 0.125;

(* Material library — cantilever K (imperial composite) and elastic
   moduli. Cross-references the workbook material library, rows 19-25. *)
materials = <|
  "Padauk"       -> <|"K" -> 24438., "E" -> 11.0*^9, "rho" -> 745.|>,
  "Wenge"        -> <|"K" -> 27103., "E" -> 15.8*^9, "rho" -> 870.|>,
  "Cherry"       -> <|"K" -> 27275., "E" -> 10.3*^9, "rho" -> 560.|>,
  "BlackWalnut"  -> <|"K" -> 27734., "E" -> 11.6*^9, "rho" -> 610.|>,
  "HardMaple"    -> <|"K" -> 26887., "E" -> 12.6*^9, "rho" -> 705.|>,
  "Mahogany"     -> <|"K" -> 26314., "E" -> 10.1*^9, "rho" -> 590.|>,
  "WesternRedCedar" -> <|"K" -> 29013., "E" -> 7.7*^9, "rho" -> 370.|>
|>;

(* === 2. Constants === *)

cAir = 13552.;     (* speed of sound in inches/sec *)
mPerIn = 0.0254;   (* unit conversion *)

(* MIDI -> Hz *)
fFromMidi[m_] := 440. * 2.^((m - 69)/12.);

(* === 3. Tongue cantilever (DOF 1) === *)

(* Flat cantilever Euler-Bernoulli: f = K * t / L^2  =>  L = sqrt(K * t / f) *)

LFlat[K_, t_, f_]    := Sqrt[K * t / f];
LCurved[K_, t_, f_, mult_:1.025] := mult * Sqrt[K * t / f];

(* Predicted ding tongue length, V1 vs V2 *)
KSb = materials[sbWood, "K"];
fDing = fFromMidi[dingMidi];

LDingFlat   = LFlat[KSb, sbThk, fDing];
LDingCurved = LCurved[KSb, sbThk, fDing];

(* Print *)
Print["Predicted tongue lengths for ", sbWood,
      " soundboard, ", sbThk, " in thick:"];
Print["  Ding (MIDI ", dingMidi, ", ", NumberForm[fDing, 5], " Hz):"];
Print["    flat   = ", NumberForm[LDingFlat, 4], " in"];
Print["    curved = ", NumberForm[LDingCurved, 4], " in (multiplier 1.025)"];

(* === 4. Helmholtz cavity (DOF 3) === *)

(* fH = (c / 2 pi) * sqrt(A / (V * Lneck)) *)

fHelmholtz[V_, A_, Lneck_] := (cAir / (2 Pi)) * Sqrt[A / (V * Lneck)];

(* Volume formulas per variant (in cubic inches) *)
volV1 = Pi * (shellOD/2)^2 * shellHeight;                          (* cyl flat *)
volV2 = volV1 + (2/3)*Pi*(shellOD/2)^2 * domeRise;                 (* cyl + dome *)
volV3 = (2/3) * Pi * (shellOD/2)^3;                                (* hemi flat *)
volV4 = volV3 + (2/3)*Pi*(shellOD/2)^2 * domeRise;                 (* hemi + dome *)

portArea = Pi * (guPortDia/2)^2;
neckFlat   = sbThk;
neckDomed  = sbThk + domeRise/2;

fHV1 = fHelmholtz[volV1, portArea, neckFlat];
fHV2 = fHelmholtz[volV2, portArea, neckDomed];
fHV3 = fHelmholtz[volV3, portArea, neckFlat];
fHV4 = fHelmholtz[volV4, portArea, neckDomed];

Print[];
Print["Helmholtz frequencies (current preset, gu port = ", guPortDia, " in):"];
Print["  V1 (cyl + flat)  : ", NumberForm[fHV1, 5], " Hz, ratio ",
      NumberForm[fHV1/fDing, 3]];
Print["  V2 (cyl + dome)  : ", NumberForm[fHV2, 5], " Hz, ratio ",
      NumberForm[fHV2/fDing, 3]];
Print["  V3 (hemi + flat) : ", NumberForm[fHV3, 5], " Hz, ratio ",
      NumberForm[fHV3/fDing, 3]];
Print["  V4 (hemi + dome) : ", NumberForm[fHV4, 5], " Hz, ratio ",
      NumberForm[fHV4/fDing, 3]];
Print["  Coupled regime: 0.80 <= ratio <= 1.20"];

(* === 5. 3-DOF coupled-oscillator model === *)

(*
   Reduced model: tongue (m1, k1), shell wall (m2, k2), air (m3, k3)
   coupled by k12 (rabbet stiffness) and k23 (wall-air compliance).
   Solving the 3x3 mass-spring system yields three eigenfrequencies;
   the lower two are dominated by tongue and Helmholtz, the highest
   by the shell wall mode. The split between the tongue eigenfreq
   and the lone-tongue freq quantifies the shell's contribution to
   sustain.

   The values below are starting estimates -- they are NOT measured.
   Treat the model as a structural starting point; the per-family
   corrections database holds the calibrated numbers once measurements
   exist.
*)

(* Effective masses (kg) and stiffnesses (N/m) -- order-of-magnitude *)
(* Tongue: half-beam approximation, treat as single-DOF cantilever *)
m1 = 0.020;            (* ~20 g effective tongue mass *)
k1 = (2 Pi fDing)^2 * m1;

(* Shell wall: ring-mode mass, large stiffness *)
m2 = 0.5;              (* ~500 g effective wall mass *)
k2 = (2 Pi 800.)^2 * m2;   (* assumed ring mode ~800 Hz *)

(* Air cavity: lumped Helmholtz oscillator *)
m3 = 0.01;             (* effective air-plug mass at port *)
k3 = (2 Pi fHV1)^2 * m3;

(* Coupling stiffnesses *)
k12 = 0.10 * k1;       (* 10% of tongue stiffness through rabbet *)
k23 = 0.05 * k3;       (* 5% wall-air through compliance *)

KMat = {
  {k1 + k12,   -k12,   0.0  },
  {-k12,       k2 + k12 + k23, -k23},
  {0.0,        -k23,   k3 + k23}
};
MMat = DiagonalMatrix[{m1, m2, m3}];

eigSystem = Eigensystem[N[Inverse[MMat] . KMat]];
omegas = Sqrt[eigSystem[[1]]];
freqs  = Sort[omegas / (2 Pi)];

Print[];
Print["3-DOF coupled-oscillator eigenfrequencies (V1 preset):"];
Print["  Lone tongue     : ", NumberForm[fDing, 5], " Hz"];
Print["  Coupled f1      : ", NumberForm[freqs[[1]], 5], " Hz (Helmholtz-dominated)"];
Print["  Coupled f2      : ", NumberForm[freqs[[2]], 5], " Hz (tongue-dominated)"];
Print["  Coupled f3      : ", NumberForm[freqs[[3]], 5], " Hz (wall-mode-dominated)"];
Print["Sustain hint: closer f1 and f2 -> stronger bass/mid coupling."];

(* === 6. Manipulate: tune the cavity in real time === *)

(*
   Open this in Wolfram Desktop. Drag gu port size; watch the
   Helmholtz / ding ratio cross the coupled band.
*)

manipulateCell = Manipulate[
  Module[{A, V, Lneck, fH, ratio},
    A = Pi (gu/2)^2;
    V = If[variant == "V1", Pi (shellOD/2)^2 hh,
        If[variant == "V2", Pi (shellOD/2)^2 hh + (2/3) Pi (shellOD/2)^2 dr,
        If[variant == "V3", (2/3) Pi (shellOD/2)^3,
                            (2/3) Pi (shellOD/2)^3 + (2/3) Pi (shellOD/2)^2 dr]]];
    Lneck = If[variant == "V1" || variant == "V3", sbThk, sbThk + dr/2];
    fH = (cAir/(2 Pi)) Sqrt[A/(V Lneck)];
    ratio = fH / fFromMidi[ding];
    Column[{
      Row[{"Helmholtz f_H = ", NumberForm[fH, 5], " Hz"}],
      Row[{"Ding         = ", NumberForm[fFromMidi[ding], 5], " Hz"}],
      Row[{"Ratio        = ", NumberForm[ratio, 3],
           If[0.80 <= ratio <= 1.20, " <- coupled", " <- mistuned"]}]
    }]
  ],
  {{variant, "V1"}, {"V1", "V2", "V3", "V4"}, ControlType -> RadioButtonBar},
  {{ding, 57, "ding MIDI"}, 50, 70, 1},
  {{gu, 2.5, "gu port (in)"}, 0.5, 4.0, 0.05},
  {{hh, 8.0, "shell height (in)"}, 4.0, 12.0, 0.1},
  {{dr, 0.75, "dome rise (in)"}, 0.0, 1.5, 0.05}
];

(* manipulateCell *)  (* uncomment to display *)

(* === 7. Audio synthesis (preview) === *)

(* AudioGenerator can render the predicted tongue field; useful for
   pre-build pitch-target previews. *)

scaleAKurd = {220.00, 329.63, 349.23, 392.00, 440.00, 493.88, 523.25,
              587.33, 659.26, 783.99, 880.00};

(* tonguePulse[freq] returns a short attack-decay envelope over a sine
   approximation of the tongue's first mode *)
tonguePulse[freq_, dur_:0.6] :=
  Sound[SoundNote["", dur, "FluteSection", SoundVolume -> 0.6, freq]];

(* Uncomment to play the predicted A Kurd scale: *)
(* AudioPlay[Sound[Table[tonguePulse[f], {f, scaleAKurd}]]] *)

(* === 8. Notes for the per-family corrections database === *)

(*
   When the first prototype is tuned, run scripts/record_measurement.py
   from the parent instrument-maker skill. Each measurement updates:

     - K_constant for sbWood (per stock batch)
     - curved-cantilever multiplier (V2/V4 only, per dome rise)
     - end-correction term for Helmholtz neck length (per shell type)

   These propagate to every sibling packet in the wood-shell-tongue-drum
   family on next packet generation.
*)
```

## README.md

Project artifact.

# Wood Shell Tongue Drum

Slit-tongue idiophone with an enclosed wooden resonator. A round-body counterpart to the rectangular-prism wood tongue drum, with **Helmholtz cavity coupling** absent from open designs. Four geometric variants × three size envelopes, all parametric and traceable to a single design table.

Part of the [tonykoop/instrument-maker](https://github.com/tonykoop/instrument-maker) catalogue.

V1 Standard 16″ side section A-A

*V1 Cylinder + Flat Top, Standard 16″ — recommended first prototype. Black Walnut staves, Padauk soundboard, A Kurd 11-tongue field, gu port for Helmholtz tuning. Computed `f_H = 194.6 Hz` sits at 0.88 × the A3 ding (220 Hz) — inside the coupled regime by design.*

## What's new in this design

A round-body wood tongue drum with an enclosed cavity is not a commercial category at this depth. Three things distinguish it:

1. **Round body, not rectangular.** Tony's existing rectangular-prism wood tongue drum is the precursor; this design moves the same flat-cantilever physics onto a turned cylinder or hemisphere bowl.
2. **Enclosed Helmholtz cavity.** Open rectangular tongue drums waste cavity volume out the open ends. Closing the bowl puts a Helmholtz resonator under the tongue field — bass extension below the lowest tongue, tunable in the shop via the gu port.
3. **Premium tonewoods, manufacturable scope.** Padauk soundboard for the A4 reference; Black Walnut shell for the bowl. Four variants × three sizes laid out as a coordinated portfolio family rather than four bespoke pieces.

## The matrix

Four geometric variants × three size envelopes = twelve cells. Each cell carries its own chamber volume, Helmholtz frequency, tongue-fit verdict, and risk grade.

| Variant | Body | Top | Risk | Notes |
|---|---|---|---|---|
| V1 | Cylinder (ottoman silhouette) | Flat soundboard | ★★ | Lowest piece-count, most predictable tuning. **Start here.** |
| V2 | Cylinder | Shallow CNC-domed | ★★★ | Steel-tongue-drum aesthetic on a wooden body |
| V3 | Hemisphere bowl | Flat soundboard | ★★ | Tagine / Moroccan-pouf silhouette |
| V4 | Hemisphere bowl | Domed top | ★★★★ | Most steel-tongue-drum-adjacent silhouette in wood |

**Sizes:** Travel 12″ Ø · Standard 16″ Ø (Moroccan-ottoman scale) · Floor Pouf 20″ Ø.

The full Helmholtz/ding ratio matrix is in [`design.md`](design.md) §2.4. Three cells sit cleanly in the coupled regime (V1 Standard, V1 Floor Pouf, V3 Standard); V2 cells need a larger-than-preset gu port or a lower cavity/neck correction to reach coupling; V1 Travel sits right at the upper edge of the band.

## Recommended first prototype

**V1 Cylinder + Flat Top, Standard 16″, A Kurd, A3 ding (220 Hz), 11 tongues.** Justification:

- Acoustic predictability — flat-cantilever physics has < 1 % empirical detuning on Tony's prior rectangular drums.
- Helmholtz coupled out-of-the-box at `f_H/f_ding = 0.88`.
- All 11 A Kurd tongues fit within the 7″ radial cap with 8 % margin.
- Lowest piece-count: 16 staves + 1 disc = 17 wood pieces.
- Dual body-construction paths (stave or segmented) — pick the aesthetic, the physics is the same.
- Validated workflow components — stave glue-up, lathe truing, CNC slit routing — exercised on Tony's existing ashiko, conga, and tongue-drum repos.

Detailed prototype spec (dimensions, tongue length schedule, joint tolerances) in [`design.md`](design.md) §4.

## Acoustic model in one paragraph

The wood shell tongue drum is a 2-DOF coupled oscillator: the cantilever tongue is one resonator, the enclosed air cavity is another, and they share a common boundary (the soundboard). Tongues follow flat-cantilever Euler-Bernoulli `f = K · t / L²`, with `K ≈ 24,438` for Padauk. Domed tongues add a +2.5 % length correction (a starting estimate to be calibrated empirically on the first V2 build). The cavity follows the Helmholtz formula `f_H = (c/2π) · √(A_port / (V · L_neck))`; the gu port is the primary tuning knob — drilled last and step-bored in the shop while measuring `f_H`. Target: `f_H/f_ding ∈ [0.80, 1.20]`. See [`design.md`](design.md) §2 for the full derivation.

## Repo contents

| File / folder | Purpose |
|---|---|
| [`design.md`](design.md) | Governing model, variant blocks, recommended prototype |
| [`wood-shell-tongue-drum-design-table.xlsx`](wood-shell-tongue-drum-design-table.xlsx) | Parametric workbook (190 formulas, 1 sheet) |
| [`bom.csv`](bom.csv) / [`sourcing.csv`](sourcing.csv) / [`cut-list.csv`](cut-list.csv) / [`validation.csv`](validation.csv) | Manufacturing CSVs |
| [`assembly-manual.md`](assembly-manual.md) | 7-phase build instructions |
| [`supplier-rfq.md`](supplier-rfq.md) | Q2 2026 batch supplier RFQ |
| [`drawing-brief.md`](drawing-brief.md) / [`drawings/`](drawings/) | 9-sheet drawing spec + hero SVG |
| [`visual-bom-brief.md`](visual-bom-brief.md) / [`photo-shotlist.md`](photo-shotlist.md) | Photography briefs |
| [`risks.md`](risks.md) | Red-team pass with verification tests attached |
| [`wolfram-starter.wl`](wolfram-starter.wl) | 3-DOF coupled-oscillator notebook starter |
| [`capstone-deck.md`](capstone-deck.md) / [`print-packet.md`](print-packet.md) | Recruiter-facing deck + shop-floor printable packet |
| [`cad/`](cad/) / [`cnc/`](cnc/) | Toolpath plans, jig decisions, laser templates, CAD staging |
| [`cnc/jig-and-template-plan.md`](cnc/jig-and-template-plan.md) | Fixture choice matrix for the first prototype and later variants |
| [`site/index.html`](site/index.html) | Build-log static site |
| [`concepts/`](concepts/) | Original concept sheet (ideation, not manufacturable) |

## Build status

- ✅ Parametric design table (workbook + `design.md` packet)
- ✅ BOM, sourcing, cut list, validation CSVs
- ✅ Assembly manual, supplier RFQ, drawing brief, visual BOM brief, photo shot list
- ✅ Risks register (16 entries across acoustic, structural, ergonomic, supply, fit/finish)
- ✅ Wolfram notebook starter (3-DOF coupled oscillator)
- ✅ CNC/laser/jig decision plan for public review
- ✅ Build-log site (`site/index.html`)
- ✅ Hero side-section drawing (`drawings/00-hero-v1-standard.svg`)
- ⏳ Phase 1 prototype: V1 Cylinder · Flat at 16″ Standard
- ⏳ SolidWorks CAD assembly (deferred until first-prototype calibration)
- ⏳ Auto-generated SVG sheets 01–09 from `scripts/generate_drawings.py`
- ✅ Capstone markdown and print-packet PDF generated from the repo sources
- ⏳ Capstone .pptx refresh (requires python-pptx in the local generator environment)

## Highest-risk unknowns

To be retired by Phase 1 measurements:

1. Curved-cantilever multiplier for our specific dome rise (V2/V4 only; +2.5 % is a starting estimate).
2. Helmholtz end-correction term for slit ports vs circular ports (all variants).
3. Padauk K-constant for our specific stock vs the library value (24,438).
4. Bowl-top rabbet joint long-term durability under seasonal humidity cycling.
5. Player ergonomics on Floor Pouf 20″ (new size class for Tony's catalog).

Full risk register with mitigations and verification tests in [`risks.md`](risks.md).

## Sister repos

- [`tonykoop/tongue-drum`](https://github.com/tonykoop/tongue-drum) — rectangular-prism precursor, validates flat-cantilever physics
- [`tonykoop/steel-tongue-drum`](https://github.com/tonykoop/steel-tongue-drum) — steel cantilever cousin
- [`tonykoop/ceramic-tongue-drum`](https://github.com/tonykoop/ceramic-tongue-drum) — slip-cast cousin
- [`tonykoop/ashiko-drum-workshop`](https://github.com/tonykoop/ashiko-drum-workshop) — segmented bowl reference
- [`tonykoop/conga`](https://github.com/tonykoop/conga) — stave & segmented shell reference
- [`tonykoop/instrument-maker`](https://github.com/tonykoop/instrument-maker) — orchestrating skill, Master Catalog, validate_packet.py

## License

[CC BY 4.0](LICENSE) — see LICENSE for details. The design (workbook, drawings, narrative) is shared under CC BY 4.0; the maker should still apply their own judgment to material selection and shop safety.

## photo-shotlist.md

Project artifact.

# Photo Shot List — Wood Shell Tongue Drum

Generated: 2026-05-07

This shot list feeds the build-log site (`site/index.html`), the printable shop packet, and any future capstone-deck refresh. Real photographs replace SVG placeholders as builds complete. Until prototypes exist, the SVG drawings carry the visual weight of the documentation.

## Required hero and overview

| Shot ID  | Subject | Purpose | Status |
|---|---|---|---|
| HERO-001 | V1 Standard 16″ finished, 3/4 angle, on neutral backdrop | README hero, build-log site cover | Needed |
| HERO-002 | All four variants (V1–V4) at Standard 16″ in a row, soundboards facing camera | Family lineup; print packet cover | Needed (after Phase 4) |
| HERO-003 | Three-size ladder (Travel + Standard + Floor Pouf) of V1 only | Size-progression catalog shot | Needed (after Phase 5) |
| HERO-004 | V1 Standard in-hand with mallets, top-down | Scale and ergonomics | Needed |

## Construction process — V1 Standard (recommended first prototype)

| Shot ID | Subject | Purpose | Status |
|---|---|---|---|
| BUILD-101  | 16 stave blanks rough-cut, fanned out | Stock prep | Needed |
| BUILD-102  | Stave on tilting-arbor jig with 11.25° bevel cut | Miter setup | Needed |
| BUILD-103  | Staves taped flat, edges glued, ready to roll into cylinder | Stave glue-up Phase 1A.3 | Needed |
| BUILD-104  | Cylinder under three ratchet straps, squeeze-out beading | Glue-up clamp | Needed |
| BUILD-105  | Shell mounted on lathe, OD truing pass | Phase 1A.4 | Needed |
| BUILD-106  | Rim rabbet detail, ¼″ × ⅜″, dial indicator showing TIR | Critical-tolerance shot | Needed |
| BUILD-107  | Padauk soundboard disc on CNC, 1/8″ upcut spiral routing tongue slits | Phase 2A; cite slit kerf 0.125″ | Needed |
| BUILD-108  | Slit field complete on soundboard, top-down | Tongue layout reference | Needed |
| BUILD-109  | Rabbet joint dry-fit, soundboard half-engaged | Air-seal demonstration | Needed |
| BUILD-110  | Rabbet joint glued and clamped with cauls | Phase 3.1 | Needed |
| BUILD-111  | Gu-port step-drilling with mic + Korg in frame | Phase 4 — Helmholtz tuning | Needed |
| BUILD-112  | Tongue tuning with sanding bar, Korg OT-120 reading | Phase 5 — final tuning | Needed |

## Domed-top variant (V2 Standard) — additional shots

| Shot ID | Subject | Purpose | Status |
|---|---|---|---|
| DOME-201 | Poplar test blank with dome surfacing complete | De-risk shot | Needed |
| DOME-202 | Padauk dome blank in flip-jig, datum pins visible | CNC workholding | Needed |
| DOME-203 | Domed Padauk top, raking light to show 0.75″ rise | Profile reference | Needed |
| DOME-204 | First-tongue calibration cut, single tongue, before mass-cutting | Curved-cantilever validation | Needed |
| DOME-205 | Korg + tap test on the calibration tongue | Multiplier measurement | Needed |

## Hemisphere-bowl variants (V3, V4) — additional shots

| Shot ID | Subject | Purpose | Status |
|---|---|---|---|
| BOWL-301 | Graduated rings stacked but unglued, showing decreasing-dia profile  | Segmented bowl construction | Needed |
| BOWL-302 | Single ring closed and glued on lazy-susan jig | Per-ring closure | Needed |
| BOWL-303 | Stacked bowl on lathe, profile-truing pass | Lathe-truing the spherical exterior | Needed |
| BOWL-304 | Finished bowl rim with planar TIR check | Rim flatness verification | Needed |

## Detail and material shots

| Shot ID | Subject | Purpose | Status |
|---|---|---|---|
| DETAIL-401 | Stave miter close-up against digital protractor | 11.25° angle reference | Needed |
| DETAIL-402 | Tongue slit terminus geometry, extreme close-up | Slit corner relief | Needed |
| DETAIL-403 | Padauk grain detail on finished soundboard | Material identification | Needed |
| DETAIL-404 | Black Walnut shell exterior with Watco Danish Oil finish, raking | Finish quality | Needed |
| DETAIL-405 | Buna-N O-ring installed in finished gu port | Optional Hapi-style detail | Needed |

## Ergonomic / play context

| Shot ID | Subject | Purpose | Status |
|---|---|---|---|
| PLAY-501 | Player seated, V1 Standard on lap, two-mallet position | Lap-play ergonomics | Needed |
| PLAY-502 | Player at floor with Floor Pouf, both hands striking outer tongues | Floor-play reach | Needed |
| PLAY-503 | Side-by-side: player hands on Standard vs Floor Pouf | Size comparison for ergonomics | Needed |

## Audio reference

Not photo, but live audio recordings should accompany the build-log site:

| Track ID  | Subject | Purpose | Status |
|---|---|---|---|
| AUDIO-001 | Single ding strike, decay to silence | Sustain T60 measurement | Needed |
| AUDIO-002 | Full A Kurd scale played up | Tuning verification | Needed |
| AUDIO-003 | A vs B vs C vs D — same scale, four variants | Variant tonal comparison | Needed (after Phase 4) |
| AUDIO-004 | Cavity puff test recording with visible f_H peak | Helmholtz validation evidence | Needed |

## Status legend

- **Needed** — not yet captured; SVG or sketch placeholder until then.
- **Captured** — file path replaces this entry; image embedded in `site/index.html`.
- **Reshoot** — captured but rejected on quality / framing; queued.

## Photography conventions

- **Backdrop:** kraft butcher paper or off-white seamless for hero shots; raw shop bench OK for build-process shots.
- **Lighting:** one diffused softbox 45° camera-left for hero/detail; ambient shop light + tripod-stable shutter for process.
- **Format:** all photographs landscape 3:2 unless explicitly portrait. Hero is portrait 4:5.
- **Resolution:** 4000 × 6000 minimum at capture; export 2000 × 3000 web JPEG for the site.
- **Naming:** `images/<SHOT_ID>_<short-slug>.jpg` (e.g., `images/HERO-001_v1-std-finished.jpg`).

## risks.md

Project artifact.

# Risks — Wood Shell Tongue Drum

Red-team pass over the design. Each risk has a category, severity, mitigation, and an attached verification test that is mirrored into `validation.csv` so the empirical-learning loop closes around it once the prototype exists.

This is a *new* design — no commercial wood-shell tongue drums exist in the round-body × dome-top × premium-tonewood format at this depth — so the risk surface is broader than for a refinement of an established pattern. The first physical prototype's measurements will retire most of the acoustic risk; structural and ergonomic risks need pre-prototype mitigation.

---

## Acoustic

### A1 — Curved-cantilever +2.5 % multiplier is unmeasured for our specific dome rise (V2, V4)

**Severity:** high (V2, V4 only)
**Description:** The tongue length correction `L_curved = L_flat × 1.025` is a starting estimate from cylinder-shell theory for shallow domes. The actual factor for our specific dome rise (0.75″ on Standard, 4.7 % of OD) is not measured. If the actual factor is, say, 1.04, every tongue cut at 1.025-multiplier length will sit ~30 cents flat across the field.
**Mitigation:** before cutting all 11 tongues on a V2/V4 build, cut ONE tongue at the predicted length, measure pitch with a Korg OT-120, back-solve the actual multiplier (`m_actual = sqrt(f_meas / f_predicted)` adjusted for the cut geometry), and apply the corrected multiplier to the remaining 10. The first dome build is also the first measurement entry into the per-family corrections database.
**Verification test:** "first-tongue calibration" entry in `validation.csv` for V2/V4 only — measured/predicted ratio with acceptance band 0.95–1.10.

### A2 — Helmholtz under-coupling on V2 and V4 with preset gu port

**Severity:** medium
**Description:** V2 and V4 ratios on Standard 16″ are 0.61 and 0.73 respectively — under-coupled. The cavity's Helmholtz resonance sits well below the ding and won't reinforce it. The drum will sound fine but not gain the bass extension the design promises.
**Mitigation:** the gu port preset (2.5″ on Standard) is a reviewable starting point, not a fixed feature. For V2/V4 builds, start with a pilot hole, step up in 0.25″ increments, and expect a larger effective port than V1 because larger port area raises `f_H`. The Standard 16″ V2 lower coupled edge is estimated near 3.3″; if that is structurally or aesthetically too large, switch to a port sleeve / neck-length experiment and record the revised model.
**Verification test:** Helmholtz cavity row in `validation.csv` per variant; pass = `f_H/f_ding` ∈ [0.80, 1.20].

### A3 — Floor Pouf D3 ding tongue exceeds radial fit cap

**Severity:** high (Floor Pouf only)
**Description:** Computed flat-cantilever D3 ding length on 0.5″ Padauk = 9.122″. Fit cap (radius − 1″ clearance) = 9.0″. Tongue overhangs by 0.12″ — does not fit.
**Mitigation:** three options, ordered by preference:
  1. **Cedar substitute** for the Floor Pouf soundboard (K = 29,013). Computed length 8.34″ — fits with 0.66″ margin. Tonal trade: brighter, more guitar-like, less bass.
  2. **Thin the soundboard** from 0.5″ to 0.4375″. Computed length 8.53″ — fits with 0.47″ margin. Trade: stiffness across a 20″ span drops; risk of soundboard sag.
  3. **Raise ding to D♯3** (one semitone, MIDI 51, 155.6 Hz). Computed length 8.86″ at 0.5″ Padauk — fits with 0.14″ margin. Trade: scale shift; player must learn the new key.
**Verification test:** ding tongue length measurement vs cap before slit cuts; abort cut if margin < 0.10″.

### A4 — Soundboard rabbet leaks → Helmholtz Q drops

**Severity:** medium
**Description:** Helmholtz resonators need an airtight cavity to sustain bass. A leaky rabbet joint will let the cavity bleed pressure on each tongue strike, killing the bass extension.
**Mitigation:** lathe-trued rim (± 0.005″ TIR), slip-fit rabbet (0.005″ clearance), uniform Titebond III bead, two-caul clamp. Smoke or vacuum test before finishing.
**Verification test:** "bowl-top airtight seal" row in `validation.csv` — pass/fail vacuum or smoke test post-glue, pre-finish.

### A5 — End-correction error in Helmholtz formula

**Severity:** low
**Description:** The Helmholtz formula uses `L_neck = soundboard_thickness` for flat tops. The actual oscillating air column extends slightly above and below the soundboard plane (the "end correction" of an open pipe). For tongue-drum kerfs (slit, not circular) this is small but nonzero.
**Mitigation:** the design currently absorbs the error in the 0.88-ratio safety margin (so even if the actual `f_H` runs 5–10 % low, it stays in the coupled band). If first-prototype `f_H` measures > 10 % below predicted, add an empirical end-correction term to the workbook formula and update the per-family corrections database.
**Verification test:** "Helmholtz cavity" row in `validation.csv`; if `(predicted - measured) / predicted > 0.10`, file an empirical-correction update.
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

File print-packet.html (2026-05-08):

# Wood Shell Tongue Drum Capstone Print Packet

Generated: 2026-05-08

Packet folder: `wood-shell-tongue-drum`

## File Map

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

## design.md

Project intent, catalog metadata, assumptions, and validation plan.

# Wood Shell Tongue Drum — Parametric Design Sheet

**Owner:** Tony Koop · Heifer Zephyr Instruments

**Family:** Slit-tongue idiophone with enclosed wooden resonator (round-body)

**Members:** four geometric variants (V1–V4) × three size envelopes (Travel 12″, Standard 16″, Floor Pouf 20″)

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

**Recommended first prototype:** **V1 Cylinder + Flat Top, Standard 16″, A Kurd**

## 1. Intent

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

ID | Body | Top | Notes

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

Size | OD (in) | Height (in) | Soundboard (in) | Tongue width (in) | Target ding | Ding f (Hz)

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

## 2. Governing acoustic model

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

### 2.1 Tongue — flat cantilever (Euler–Bernoulli)

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

f = K · t / L²              (flat top, Variants 1 and 3)
L = √( K · t / f )

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

Wood | E (GPa) | ρ (kg/m³) | K (cantilever) | Tone | Rating

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

### 2.2 Tongue — curved cantilever (V2, V4)

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

L_curved = L_flat · 1.025         (+2.5 % for shallow domes, dome rise ≤ 6 % of OD)

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

### 2.3 Cavity — Helmholtz resonator

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

f_H = (c / 2π) · √( A_port / (V · L_neck) )           with c = 13,552 in/s

Chamber volume formulas, by variant:

Variant | Body shape | Cavity volume formula

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

Effective neck length:

Top type | `L_neck`

Flat | soundboard thickness `t`
Domed | `t + h_dome / 2`

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

### 2.4 Computed Helmholtz / ding ratios (current presets)

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

### 2.4.1 Gu-port tuning direction

Condition | Field symptom | Corrective direction | First shop action

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

### 2.5 Tongue-fit cap

For each size, the longest tongue (the ding) cannot exceed the radial fit cap:

L_cap = OD/2 − 1″                  (1″ reserved for ding-strike clearance and rim)

Size | Cap (in) | V1/V3 ding length (in) | V2/V4 ding length (in) | Verdict

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

## 3. Variant blocks — manufacturing and acoustic notes

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

### V1 — Ottoman Cylinder, Flat Top ★ RECOMMENDED FIRST BUILD

**Body construction:** stave-built or segmented cylinder. The two paths are equally valid:

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

### V2 — Ottoman Cylinder, Domed Top

**Body construction:** same as V1.

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

### V3 — Hemisphere Bowl, Flat Top

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

### V4 — Hemisphere Bowl, Domed Top

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

**Top construction:** same dome workflow as V2.

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

**Risk / Difficulty:** ★★★★ — highest piece-count + highest empirical tuning risk. Most beautiful result; **build last**.

## 4. Recommended first prototype — V1 Cylinder + Flat Top, Standard 16″

This is the **strongly recommended starting build**. Justification:

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

**Specific prototype build configuration:**

Parameter | Value

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

**Tongue length schedule** (Padauk 0.375″, A Kurd transposed from workbook §A reference scale):

# | Note | MIDI | Freq (Hz) | L (in) | L (mm)

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

## 5. Build sequence — phases across the family

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

Phase | Build | What it teaches

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

## 6. Critical joints and tolerances

Joint | Tolerance | Why

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

## 7. Open questions and assumptions (red-team flagged in `risks.md`)

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

## 8. Cross-references

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

## bom.csv

Starter bill of materials with part categories, quantities, drawing refs, and notes.

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

## sourcing.csv

Supplier/search tracker with specs, price/date fields, lead time, substitutes, and risks.

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

## cut-list.csv

Rough/final stock sizes, material, grain/orientation, operations, yield, and offcuts.

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

## drawing-brief.md

Manufacturing drawing and technical product sketch brief.

# Drawing Brief — Wood Shell Tongue Drum

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

## Required drawings

File | Sheet | Title | Notes

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

## Drawing conventions

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

## Critical dimensions (must appear on the drawings)

Dimension | Drawing | Value (Standard 16″ V1) | Tolerance

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

## Sheet 03 — tongue layout details

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

Position grid (radial coords, ding = origin):

# | Note | r (in from ding centerline) | θ (deg) | length (in)

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

## Status

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

## assembly-manual.md

Shop-facing sequence, tools, fixtures, safety, tuning, finishing, and maintenance notes.

# Wood Shell Tongue Drum — Assembly Manual

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

## Phase 0 — Shop preparation

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

2. Joint and plane stock to nominal dimensions ± 0.005″.

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

## Phase 1A — Cylinder shell (V1, V2)

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

### 1A.1 Stave path (preferred for first build)

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

### 1A.2 Segmented path (alternative for polychrome aesthetic)

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

### 1A.3 Stave glue-up (path A)

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

3. Re-roll, close to a full cylinder.

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

6. Cure 24 hours.

### 1A.4 Lathe truing (both paths converge)

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

## Phase 1B — Hemisphere bowl (V3, V4)

Pick one of two construction paths. Segmented is recommended for the first hemisphere build.

### 1B.1 Segmented bowl path

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

2. Glue each ring closed on the lazy-susan jig before stacking.

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

4. Mount the assembled bowl on a faceplate with a thick waste block.

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

### 1B.2 CNC-carved bowl path (alternative; high material waste)

1. Glue up a thick blank: 5 plies of 1″ Black Walnut for Standard 16″.

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

3. Flip-jig the blank with datum pins; 3D-surface the inside concave profile.

4. Trim rim flat on a router table or lathe; verify ± 0.005″ TIR.

## Phase 2 — Soundboard (variant-dependent)

### 2A — Flat soundboard (V1, V3)

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

### 2B — Domed soundboard (V2, V4)

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

7. Sand and finish per Phase 2A steps 4–5.

## Phase 3 — Bowl-top assembly

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

### 3.1 Rabbet joint (preferred)

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

### 3.2 Lap step joint (backup)

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

### 3.3 Cork gasket (last-resort backup)

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

## Phase 4 — Gu-port tuning

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

1. Drill a ¼″ pilot hole through the shell/bowl bottom, centered (verify ± 0.025″).

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

## Phase 5 — Tongue tuning

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

1. Set up the drum on a soft surface (foam, blanket).

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

3. Compare to `validation.csv` predicted column.

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

7. Final tuning: ± 5 cents of target on all 11 tongues.

8. Document final measurements in `validation.csv`.

## Phase 6 — Validation and acceptance

Run the full validation loop before declaring the build complete:

Check | Tool | Acceptance band

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

## Phase 7 — Finish and presentation

1. Apply 3 coats Watco Danish Oil to the shell exterior (24 h between coats).

2. Apply Renaissance Wax to the shell exterior (final coat, buffed).

3. Apply 3 coats Watco Danish Oil to the soundboard *outside* face only.

4. Adhere felt foot pads to the shell bottom (4 pads at 90° spacing).

5. Optional: install hemp carry handle (Standard size and above).

6. Photograph per `photo-shotlist.md`.

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

## Branching summary

Phase | V1 (Cyl + Flat) | V2 (Cyl + Dome) | V3 (Hemi + Flat) | V4 (Hemi + Dome)

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

## validation.csv

Target/measured values, tolerance, environment, result, and tuning/build action log.

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

## supplier-rfq.md

Supplier email/request-for-quote starter.

# Supplier RFQ — Wood Shell Tongue Drum (Q2 2026 batch)

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

## Lumber

Need | Quantity (per drum) | Specification

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

**Preferred suppliers:** Bell Forest Products (primary), Cook Woods (segment blanks). Local pickup acceptable if equivalent grade.

## Tooling

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

Item | Qty | Source

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

## Hardware and consumables

Item | Qty (per drum) | Notes

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

## Skin/heads

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

## Acoustic test gear (one-time shop equipment)

These are workshop instruments, not per-drum consumables. Listed for budget transparency.

Item | Qty | Notes

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

## Lead-time summary

Category | Typical lead time

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

## Quote request

Please confirm:

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

3. Lead-time guarantees for Q2 2026.

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

Heifer Zephyr Instruments

Tony Koop

[github.com/tonykoop/wood-shell-tongue-drum](https://github.com/tonykoop/wood-shell-tongue-drum)

## visual-bom-brief.md

Art direction for an image-forward visual BOM.

# Visual BOM — Photo shotlist for the BOM hero plate

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

## Hero shot — V1 Standard 16″ (recommended first prototype)

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

**Lighting:** one diffused softbox at 45° camera-left, slight bounce-fill from camera-right.

**Layout** (top-down grid, parts arranged left-to-right by build phase):

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

Row 3 — Tuning hardware (sparse)
  [step drill bit]  [Buna-N O-ring]  [Korg OT-120 tuner]

Row 4 — Finish + accessory
  [Watco Danish Oil]  [Renaissance Wax]  [pair of mallets]  [felt foot pads]

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

## Detail shots — shared across variants

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

## Variant comparison shot (after Phases 1–4)

After all four variants are built, one final group shot:

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

## Process / progression montage

A 4 × 2 grid of in-shop process shots illustrating the build sequence:

1. Stave glue-up under ratchet straps

2. Lathe-truing the OD

3. CNC routing the tongue slits in Padauk soundboard

4. Rabbet joint assembly with cauls

5. Gu-port step-drilling with mic + tuner in frame

6. Tongue tuning with sanding bar and Korg

7. Final finish — Danish Oil application

8. Hero shot of the finished V1 Standard

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

## Constraints

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

## wolfram-starter.wl

Wolfram starter for physics, optimization, visualization, and validation.

(* ::Package:: *)

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

(* === 1. Inputs (edit me) === *)

(* All dimensions in inches; conversions to SI happen below. *)

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

dingMidi      = 57;            (* A3 *)
nTongues      = 11;
tongueWidth   = 1.25;
slitKerf      = 0.125;

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

(* === 2. Constants === *)

cAir = 13552.;     (* speed of sound in inches/sec *)
mPerIn = 0.0254;   (* unit conversion *)

(* MIDI -> Hz *)
fFromMidi[m_] := 440. * 2.^((m - 69)/12.);

(* === 3. Tongue cantilever (DOF 1) === *)

(* Flat cantilever Euler-Bernoulli: f = K * t / L^2  =>  L = sqrt(K * t / f) *)

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

(* Predicted ding tongue length, V1 vs V2 *)
KSb = materials[sbWood, "K"];
fDing = fFromMidi[dingMidi];

LDingFlat   = LFlat[KSb, sbThk, fDing];
LDingCurved = LCurved[KSb, sbThk, fDing];

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

(* === 4. Helmholtz cavity (DOF 3) === *)

(* fH = (c / 2 pi) * sqrt(A / (V * Lneck)) *)

fHelmholtz[V_, A_, Lneck_] := (cAir / (2 Pi)) * Sqrt[A / (V * Lneck)];

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

portArea = Pi * (guPortDia/2)^2;
neckFlat   = sbThk;
neckDomed  = sbThk + domeRise/2;

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

(* === 5. 3-DOF coupled-oscillator model === *)

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

eigSystem = Eigensystem[N[Inverse[MMat] . KMat]];
omegas = Sqrt[eigSystem[[1]]];
freqs  = Sort[omegas / (2 Pi)];

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

(* === 6. Manipulate: tune the cavity in real time === *)

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

(* manipulateCell *)  (* uncomment to display *)

(* === 7. Audio synthesis (preview) === *)

(* AudioGenerator can render the predicted tongue field; useful for
   pre-build pitch-target previews. *)

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

(* Uncomment to play the predicted A Kurd scale: *)
(* AudioPlay[Sound[Table[tonguePulse[f], {f, scaleAKurd}]]] *)

(* === 8. Notes for the per-family corrections database === *)

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

## README.md

Project artifact.

# Wood Shell Tongue Drum

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

Part of the [tonykoop/instrument-maker](https://github.com/tonykoop/instrument-maker) catalogue.

V1 Standard 16″ side section A-A

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

## What's new in this design

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

## The matrix

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

Variant | Body | Top | Risk | Notes

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

**Sizes:** Travel 12″ Ø · Standard 16″ Ø (Moroccan-ottoman scale) · Floor Pouf 20″ Ø.

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

## Recommended first prototype

**V1 Cylinder + Flat Top, Standard 16″, A Kurd, A3 ding (220 Hz), 11 tongues.** Justification:

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

Detailed prototype spec (dimensions, tongue length schedule, joint tolerances) in [`design.md`](design.md) §4.

## Acoustic model in one paragraph

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

## Repo contents

File / folder | Purpose

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

## Build status

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

## Highest-risk unknowns

To be retired by Phase 1 measurements:

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

2. Helmholtz end-correction term for slit ports vs circular ports (all variants).

3. Padauk K-constant for our specific stock vs the library value (24,438).

4. Bowl-top rabbet joint long-term durability under seasonal humidity cycling.

5. Player ergonomics on Floor Pouf 20″ (new size class for Tony's catalog).

Full risk register with mitigations and verification tests in [`risks.md`](risks.md).

## Sister repos

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

## License

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

## photo-shotlist.md

Project artifact.

# Photo Shot List — Wood Shell Tongue Drum

Generated: 2026-05-07

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

## Required hero and overview

Shot ID | Subject | Purpose | Status

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

## Construction process — V1 Standard (recommended first prototype)

Shot ID | Subject | Purpose | Status

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

## Domed-top variant (V2 Standard) — additional shots

Shot ID | Subject | Purpose | Status

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

## Hemisphere-bowl variants (V3, V4) — additional shots

Shot ID | Subject | Purpose | Status

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

## Detail and material shots

Shot ID | Subject | Purpose | Status

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

## Ergonomic / play context

Shot ID | Subject | Purpose | Status

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

## Audio reference

Not photo, but live audio recordings should accompany the build-log site:

Track ID | Subject | Purpose | Status

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

## Status legend

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

## Photography conventions

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

## risks.md

Project artifact.

# Risks — Wood Shell Tongue Drum

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

## Acoustic

### A1 — Curved-cantilever +2.5 % multiplier is unmeasured for our specific dome rise (V2, V4)

**Severity:** high (V2, V4 only)

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

### A2 — Helmholtz under-coupling on V2 and V4 with preset gu port

**Severity:** medium

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

### A3 — Floor Pouf D3 ding tongue exceeds radial fit cap

**Severity:** high (Floor Pouf only)

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

**Mitigation:** three options, ordered by preference:

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

### A4 — Soundboard rabbet leaks → Helmholtz Q drops

**Severity:** medium

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

### A5 — End-correction error in Helmholtz formula

**Severity:** low

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

### A6 — A4 ≠ 440 Hz on the prototype

**Severity:** low (failure mode, not a design risk — but the catch is structural)

**Description:** Tongue 4 on the recommended prototype is A4 (440 Hz). If the measured A4 is off > 5 cents, the K-constant of our specific Padauk stock differs from the library value (24,438). All other tongue lengths will be proportionally wrong.

**Mitigation:** cut tongue 4 first as a calibration tongue; measure A4; back-compute `K_actual = f_measured × L² / t`; update the workbook K-cell; recompute all 10 remaining tongue lengths before cutting.

**Verification test:** "A4 = 440 Hz sanity" row in `validation.csv`.

## Structural

### S1 — Soundboard slit-area exceeds 50 % limit causes rim-zone failure

**Severity:** medium

**Description:** Removing too much material from the soundboard (slits + perimeter rabbet relief) leaves the rim zone too weak; under cantilever loading from the tongues plus rim constraint from the rabbet, the rim could chip or split, especially in Padauk's straight-grain regions.

**Mitigation:** total slit kerf + rabbet area held at ~30 % of soundboard area on V1 Standard (verified against the 11-tongue layout). Stay-zones at least 0.75″ wide between adjacent tongue slits.

**Verification test:** measure slit-area fraction during CAD/CNC programming; reject layouts > 45 %.

### S2 — Stave glue-line failure under thermal/humidity cycling

**Severity:** low-medium

**Description:** Black Walnut staves have axial grain and tangential growth. Seasonal humidity cycling could open glue lines (especially if the shell finishes too soon after glue-up).

**Mitigation:** Titebond III is rated 4000 psi shear (waterproof PVA), well above structural minimum. Cure full 24 h before lathe-truing. Acclimate stock 2 weeks pre-glue. Apply finish to *exterior* only — leave the interior unfinished so the wood can equalize humidity through one face.

**Verification test:** glue-line shear sample test (one sacrificial joint per glue batch); reject batch if test joint fails < 3000 psi.

### S3 — Soundboard cup or warp during finish drying

**Severity:** medium

**Description:** Finishing only one face of a soundboard (Watco on top, unfinished underside) creates a moisture gradient. If finish is applied too thick or too fast, the disc cups, lifting tongue tips off neutral and detuning the field.

**Mitigation:** thin coats (3 light coats vs 1 heavy), 24 h between coats, finish in same humidity environment as glue-up. Hold the disc flat on cauls for the first cure.

**Verification test:** post-finish flatness check across diagonal — disc should be flat within 1/64″ over 16″ span.

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

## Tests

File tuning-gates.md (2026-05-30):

# Tongue-Tuning Gates

Status: L1/L2 concept and measurement plan. This file does not introduce new tuning frequencies, CAD geometry, DXF coordinates, or measured acoustic claims.

## Authority Posture

The packet may be used for review and prototype planning. It may not be used as a build-ready tuning release until the physical gates below are measured, recorded, and folded back into the design table.

Existing target and predicted values in `design.md`, `family-spec.csv`, and `validation.csv` are inherited packet estimates. Round 2 recovery did not add new numeric targets. Treat all acoustic values as `pending_measurement` unless a later evidence row records a real prototype measurement.

## Material Gates

| Gate | Why it matters | Evidence needed | Blocks |
| --- | --- | --- | --- |
| Soundboard species and stock ID | Wood K constants vary by board, grain, moisture, and supplier | Stock label, species confirmation, thickness map, moisture/environment note | Tongue length release |
| Padauk or alternate K calibration | The library K value is only a planning model for the actual board | One calibration tongue, measured pitch, back-solved K, cents error | Full tongue-field cutting |
| Soundboard thickness uniformity | Cantilever frequency depends directly on thickness | Multi-point caliper map before cutting tongues | Tuning repeatability claim |
| Grain and defect review | Runout, checks, glue lines, and knots can split tongues or detune sustain | Photo log and reject/accept notes | Shop release |

## Structure Gates

| Gate | Why it matters | Evidence needed | Blocks |
| --- | --- | --- | --- |
| Shell rim planarity | Air leaks and uneven soundboard support change Helmholtz response | Dial-indicator or feeler-gauge check | Soundboard glue-up |
| Chamber air seal | Helmholtz coupling requires controlled air movement through the port | Low-pressure smoke, vacuum, or leak check | Coupling claim |
| Gu-port field tuning | Port end correction cannot be trusted from concept geometry alone | Step-drill log with measured cavity response after each change | Port finalization |
| Seasonal joint rest | Wood movement can alter seal, pitch, and sustain | Post-rest recheck after humidity or time interval | Repeatability claim |

## Tongue-Tuning Workflow

1. Cut or route only the calibration tongue or sacrificial coupon first.
2. Measure the calibration pitch with the selected tuner or spectrum method.
3. Back-solve the actual board K constant and compare it to the planning value.
4. Update the design table before cutting the remaining tongue field.
5. Cut remaining tongues intentionally long or high, then file/sand down to pitch.
6. Record each tongue measurement in `validation.csv`, including environment and cents error.
7. Do not promote CAD, DXF, SVG, print plates, or G-code to fabrication authority until they are regenerated from the calibrated table.

## L3 Promotion Gates

- `validation.csv` has measured values for the V1 Standard prototype tongue field.
- `validation-loop.csv` rows `vl002`, `vl003`, and `vl004` are no longer `measurement_required`.
- `visual-output-register.csv` identifies the calibrated source for every drawing, CAD, DXF, and print output.
- `cad/mcp-session-log.md` records any external CAD, OpenSCAD, Illustrator, Blender, Photoshop, or image-generation session that produced or edited an artifact.
- `risks.md` has updated residual risks for cracking, detuning, air leaks, and seasonal drift after the first measured build.

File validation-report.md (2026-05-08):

# Validation Report — Wood Shell Tongue Drum

Generated during the v4 public-readiness pass on 2026-05-08.

## Clean Checks

| Gate | Result |
|---|---|
| Required Mode A files present | Pass |
| README is instrument-specific and includes hero drawing | Pass |
| Parametric design source exists | Pass (`wood-shell-tongue-drum-design-table.xlsx`) |
| BOM, sourcing, cut list, validation CSVs present | Pass |
| Assembly, RFQ, visual BOM, photo shot list present | Pass |
| Risk register exists with acoustic, structural, ergonomic, supply, and finish risks | Pass |
| Build-log site exists | Pass (`site/index.html`) |
| Print packet PDF exists | Pass |
| Capstone markdown exists | Pass |

## Fixed In This Pass

| Finding | Files updated | Resolution |
|---|---|---|
| Gu-port tuning direction was reversed in several notes | `design.md`, `README.md`, `assembly-manual.md`, `risks.md`, `validation.csv`, `site/index.html` | Clarified that increasing port area raises Helmholtz frequency; under-coupled V2/V4 variants need a larger effective port or revised neck/cavity model |
| CNC/laser/jig strategy was present but scattered | `cnc/README.md`, `cnc/jig-and-template-plan.md` | Added a single fixture/template decision matrix for public review |
| README status undersold generated packet outputs | `README.md` | Marked capstone markdown and printable packet outputs as complete; noted that PPTX refresh needs python-pptx |

## Escalated / Human-Owned

| Gate | Remaining action |
|---|---|
| Physical tuning validation | Build V1 Standard 16 in prototype; fill `measured_value`, `cents_error`, and environment fields in `validation.csv` |
| Supplier facts | Re-check current price, stock, shipping, and substitutes before buying |
| Capstone PPTX refresh | Existing `capstone-deck.pptx` is retained, but the local generator did not refresh PPTX because python-pptx is unavailable in this environment |
| CAD and G-code | Generate only after Phase 1 measurements calibrate Padauk K, rim seal behavior, and Helmholtz end correction |
| Real photos/audio | Replace concept/SVG placeholders with shop process photos, final instrument photos, and tuning recordings after build |

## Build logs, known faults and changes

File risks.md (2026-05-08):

# Risks — Wood Shell Tongue Drum

Red-team pass over the design. Each risk has a category, severity, mitigation, and an attached verification test that is mirrored into `validation.csv` so the empirical-learning loop closes around it once the prototype exists.

This is a *new* design — no commercial wood-shell tongue drums exist in the round-body × dome-top × premium-tonewood format at this depth — so the risk surface is broader than for a refinement of an established pattern. The first physical prototype's measurements will retire most of the acoustic risk; structural and ergonomic risks need pre-prototype mitigation.

---

## Acoustic

### A1 — Curved-cantilever +2.5 % multiplier is unmeasured for our specific dome rise (V2, V4)

**Severity:** high (V2, V4 only)
**Description:** The tongue length correction `L_curved = L_flat × 1.025` is a starting estimate from cylinder-shell theory for shallow domes. The actual factor for our specific dome rise (0.75″ on Standard, 4.7 % of OD) is not measured. If the actual factor is, say, 1.04, every tongue cut at 1.025-multiplier length will sit ~30 cents flat across the field.
**Mitigation:** before cutting all 11 tongues on a V2/V4 build, cut ONE tongue at the predicted length, measure pitch with a Korg OT-120, back-solve the actual multiplier (`m_actual = sqrt(f_meas / f_predicted)` adjusted for the cut geometry), and apply the corrected multiplier to the remaining 10. The first dome build is also the first measurement entry into the per-family corrections database.
**Verification test:** "first-tongue calibration" entry in `validation.csv` for V2/V4 only — measured/predicted ratio with acceptance band 0.95–1.10.

### A2 — Helmholtz under-coupling on V2 and V4 with preset gu port

**Severity:** medium
**Description:** V2 and V4 ratios on Standard 16″ are 0.61 and 0.73 respectively — under-coupled. The cavity's Helmholtz resonance sits well below the ding and won't reinforce it. The drum will sound fine but not gain the bass extension the design promises.
**Mitigation:** the gu port preset (2.5″ on Standard) is a reviewable starting point, not a fixed feature. For V2/V4 builds, start with a pilot hole, step up in 0.25″ increments, and expect a larger effective port than V1 because larger port area raises `f_H`. The Standard 16″ V2 lower coupled edge is estimated near 3.3″; if that is structurally or aesthetically too large, switch to a port sleeve / neck-length experiment and record the revised model.
**Verification test:** Helmholtz cavity row in `validation.csv` per variant; pass = `f_H/f_ding` ∈ [0.80, 1.20].

### A3 — Floor Pouf D3 ding tongue exceeds radial fit cap

**Severity:** high (Floor Pouf only)
**Description:** Computed flat-cantilever D3 ding length on 0.5″ Padauk = 9.122″. Fit cap (radius − 1″ clearance) = 9.0″. Tongue overhangs by 0.12″ — does not fit.
**Mitigation:** three options, ordered by preference:
  1. **Cedar substitute** for the Floor Pouf soundboard (K = 29,013). Computed length 8.34″ — fits with 0.66″ margin. Tonal trade: brighter, more guitar-like, less bass.
  2. **Thin the soundboard** from 0.5″ to 0.4375″. Computed length 8.53″ — fits with 0.47″ margin. Trade: stiffness across a 20″ span drops; risk of soundboard sag.
  3. **Raise ding to D♯3** (one semitone, MIDI 51, 155.6 Hz). Computed length 8.86″ at 0.5″ Padauk — fits with 0.14″ margin. Trade: scale shift; player must learn the new key.
**Verification test:** ding tongue length measurement vs cap before slit cuts; abort cut if margin < 0.10″.

### A4 — Soundboard rabbet leaks → Helmholtz Q drops

**Severity:** medium
**Description:** Helmholtz resonators need an airtight cavity to sustain bass. A leaky rabbet joint will let the cavity bleed pressure on each tongue strike, killing the bass extension.
**Mitigation:** lathe-trued rim (± 0.005″ TIR), slip-fit rabbet (0.005″ clearance), uniform Titebond III bead, two-caul clamp. Smoke or vacuum test before finishing.
**Verification test:** "bowl-top airtight seal" row in `validation.csv` — pass/fail vacuum or smoke test post-glue, pre-finish.

### A5 — End-correction error in Helmholtz formula

**Severity:** low
**Description:** The Helmholtz formula uses `L_neck = soundboard_thickness` for flat tops. The actual oscillating air column extends slightly above and below the soundboard plane (the "end correction" of an open pipe). For tongue-drum kerfs (slit, not circular) this is small but nonzero.
**Mitigation:** the design currently absorbs the error in the 0.88-ratio safety margin (so even if the actual `f_H` runs 5–10 % low, it stays in the coupled band). If first-prototype `f_H` measures > 10 % below predicted, add an empirical end-correction term to the workbook formula and update the per-family corrections database.
**Verification test:** "Helmholtz cavity" row in `validation.csv`; if `(predicted - measured) / predicted > 0.10`, file an empirical-correction update.

### A6 — A4 ≠ 440 Hz on the prototype

**Severity:** low (failure mode, not a design risk — but the catch is structural)
**Description:** Tongue 4 on the recommended prototype is A4 (440 Hz). If the measured A4 is off > 5 cents, the K-constant of our specific Padauk stock differs from the library value (24,438). All other tongue lengths will be proportionally wrong.
**Mitigation:** cut tongue 4 first as a calibration tongue; measure A4; back-compute `K_actual = f_measured × L² / t`; update the workbook K-cell; recompute all 10 remaining tongue lengths before cutting.
**Verification test:** "A4 = 440 Hz sanity" row in `validation.csv`.

---

## Structural

### S1 — Soundboard slit-area exceeds 50 % limit causes rim-zone failure

**Severity:** medium
**Description:** Removing too much material from the soundboard (slits + perimeter rabbet relief) leaves the rim zone too weak; under cantilever loading from the tongues plus rim constraint from the rabbet, the rim could chip or split, especially in Padauk's straight-grain regions.
**Mitigation:** total slit kerf + rabbet area held at ~30 % of soundboard area on V1 Standard (verified against the 11-tongue layout). Stay-zones at least 0.75″ wide between adjacent tongue slits.
**Verification test:** measure slit-area fraction during CAD/CNC programming; reject layouts > 45 %.

### S2 — Stave glue-line failure under thermal/humidity cycling

**Severity:** low-medium
**Description:** Black Walnut staves have axial grain and tangential growth. Seasonal humidity cycling could open glue lines (especially if the shell finishes too soon after glue-up).
**Mitigation:** Titebond III is rated 4000 psi shear (waterproof PVA), well above structural minimum. Cure full 24 h before lathe-truing. Acclimate stock 2 weeks pre-glue. Apply finish to *exterior* only — leave the interior unfinished so the wood can equalize humidity through one face.
**Verification test:** glue-line shear sample test (one sacrificial joint per glue batch); reject batch if test joint fails < 3000 psi.

### S3 — Soundboard cup or warp during finish drying

**Severity:** medium
**Description:** Finishing only one face of a soundboard (Watco on top, unfinished underside) creates a moisture gradient. If finish is applied too thick or too fast, the disc cups, lifting tongue tips off neutral and detuning the field.
**Mitigation:** thin coats (3 light coats vs 1 heavy), 24 h between coats, finish in same humidity environment as glue-up. Hold the disc flat on cauls for the first cure.
**Verification test:** post-finish flatness check across diagonal — disc should be flat within 1/64″ over 16″ span.

### S4 — Bowl ring-stack delamination at lathe truing (V3, V4)

**Severity:** medium (V3, V4)
**Description:** A segmented bowl with 8+ rings stacked has many glue joints under shear during lathe truing. A weak joint shows up as a "spinning piece flying off" — both a build hazard and a quality failure.
**Mitigation:** glue each ring closed BEFORE stacking; cure 24 h between layers; verify each ring's closure with a feeler gauge (< 0.005″ at glue lines) before adding the next. Lathe at moderate speed (800–1200 rpm) with sharp tools to minimize cutting forces.
**Verification test:** feeler-gauge check per glue line during stack-up; reject ring if any joint > 0.005″.

---

## Ergonomic / playability

### E1 — Standard 16″ too heavy for lap play

**Severity:** low
**Description:** Estimated weight 6–7 lb for V1 Standard 16″ — heavier than a lap-played Hapi steel tongue drum (~4 lb). Player fatigue on extended sessions.
**Mitigation:** acceptable trade for the wood acoustic benefit. Optional carry handle (`HANDLE-ROPE-S` in BOM) makes the drum portable. Floor Pouf 20″ is explicitly intended for floor placement, not lap.
**Verification test:** finished-drum weight measurement; document in catalog row but don't gate on this.

### E2 — Tongue layout reach for 5th-percentile player hand

**Severity:** low
**Description:** Tongues at radius 6.5″ from ding centerline require a ~13″ hand-span reach (across the ding). A 5th-percentile adult female hand-span is ~7″, so the maximum-radius tongues are at the edge of comfortable reach.
**Mitigation:** the radial coords are estimates and will be tightened during SolidWorks parametric placement against the actual shell radius. Recommended max radius from ding centerline: 6.0″ on Standard 16″, with the 7-tongue ergonomic envelope inside 5.0″.
**Verification test:** ergonomic photo with two-hand reach over the finished drum; note any tongue requiring a player to lean to strike.

---

## Supply / material

### SUP1 — Padauk 3/8″ thickness availability

**Severity:** low
**Description:** Padauk is commonly stocked in 4/4 (rough 1″, S2S 13/16″) but 3/8″ is non-standard. Suppliers may resaw to spec but with no guarantee of edge straightness or grain orientation match.
**Mitigation:** order 4/4 stock and resaw + plane to 3/8″ in-shop. Adds 1 h labor per soundboard but guarantees control over thickness uniformity.
**Verification test:** confirm 3/8″ stock at order time; if not available, switch to 4/4 + resaw plan.

### SUP2 — Mule hide / drum-skin substitution attempts

**Severity:** low (filed for awareness)
**Description:** A reviewer or supplier might confuse this design with a membrane drum (conga, ashiko) and try to ship drum heads. This is a slit-tongue idiophone — no skins.
**Mitigation:** explicit "N/A — no skins required" in the supplier RFQ and BOM.

---

## Fit / finish

### F1 — Slit edges chipped during sanding

**Severity:** medium
**Description:** A chipped slit edge changes the tongue's effective length and shifts pitch by tens of cents. Sanding past 320 grit near the slits is risky.
**Mitigation:** sand the soundboard *before* CNC slit routing for any work that requires aggressive grits. Post-slit, hand-sand only with light pressure, 320–600 grit, parallel to slit length, never across.
**Verification test:** visual inspection under raking light; reject any chip > 0.020″.

### F2 — Finish bleeds into slits and stiffens tongue base

**Severity:** low-medium
**Description:** Watco Danish Oil applied to the soundboard top can wick into the slit kerfs and accumulate at the tongue-base radius, locally stiffening the cantilever and shifting pitch ~5–15 cents sharp per tongue.
**Mitigation:** apply finish *before* slit cutting if the finish workflow allows. Otherwise, use a thinned finish (1:1 with mineral spirits) on the soundboard top, wipe excess immediately, and never flood the slits.
**Verification test:** post-finish A4 measurement; if A4 has shifted > 5 cents from pre-finish, document as a finish-bleed effect and quantify for the next build.

---

## Risk summary table

| ID  | Category | Severity | Variants affected | Mitigation in place | Verification gate |
|-----|---|---|---|---|---|
| A1  | Acoustic | High | V2, V4 | Yes (first-tongue calib) | first-tongue cal in validation.csv |
| A2  | Acoustic | Medium | V2, V4 | Yes (larger effective port or port-sleeve model) | f_H/f_ding ratio band |
| A3  | Acoustic | High | Floor Pouf only | Yes (Cedar / D♯3) | ding length vs cap |
| A4  | Acoustic | Medium | All | Yes (rim TIR + smoke test) | bowl-top airtight seal |
| A5  | Acoustic | Low | All | Yes (safety margin) | f_H deviation > 10 % |
| A6  | Acoustic | Low | All | Yes (calibration tongue) | A4 sanity row |
| S1  | Structural  | Medium | All | Yes (slit-area cap) | slit-area fraction ≤ 45 % |
| S2  | Structural  | Low-Med  | All (stave path) | Yes (Titebond III)  | glue-line sample shear test  |
| S3  | Structural  | Medium | All | Yes (thin coats) | post-finish flatness |
| S4  | Structural  | Medium | V3, V4 | Yes (per-ring cure) | feeler gauge per joint |
| E1  | Ergonomic | Low | All | Optional handle | weight measurement (no gate) |
| E2  | Ergonomic | Low | All | Yes (radius cap) | reach photo on prototype |
| SUP1| Supply | Low | All | Yes (resaw plan) | order-time confirm |
| SUP2| Supply | Low | All | Yes (RFQ note) | N/A |
| F1  | Fit/Finish  | Medium | All | Yes (sand sequence) | edge inspection |
| F2  | Fit/Finish  | Low-Med  | All | Yes (thin finish) | A4 shift post-finish |

---

## Highest-risk unknowns (to be retired by Phase 1 measurements)

1. **Curved-cantilever multiplier for our specific dome rise.** Will be measured on the first V2 build; until then, V2/V4 cuts are conditional on calibration.
2. **Helmholtz end-correction term.** Will be measured on the first V1 build; the design currently absorbs the uncertainty in the safety margin but the workbook formula may need an empirical update.
3. **Padauk K-constant for our specific stock.** The library value 24,438 is from textbook E and ρ; the actual stock may vary 2–5 %. A4 calibration on Phase 1 catches this.
4. **Bowl-top joint long-term durability.** Rabbet + Titebond III is the working assumption; 12+ months of seasonal cycling will reveal whether the joint holds.
5. **Player ergonomics on Floor Pouf.** A 20″-OD drum with the largest tongue at 9″+ length is a new size class for Tony's catalog. First-prototype reach photos will inform whether the radial layout needs revision.

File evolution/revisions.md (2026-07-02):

# Revision Register — wood-shell-tongue-drum

| Rev | Date | Parent | Delta | Downstream artifacts invalidated |
| --- | --- | --- | --- | --- |
| A | 2026-07-01 | — | Stage 0 intake of current master (cad/wood-shell-tongue-drum.scad + wood-shell-tongue-drum-design-table.xlsx + wolfram/wood-shell-tongue-drum-wolfram-model.wl). | none (no alpha/beta/production artifacts exist yet) |

Stage 0 only. Gate A has not been run; no Alpha compiles, vendor quotes, or production lock exist for this product.

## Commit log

2026-05-02 Initial scaffold: Wood Shell Tongue Drum
    [wood-shell-tongue-drum-design-table.xlsx]
2026-05-18 feat(learn-to-play): add wood-shell-tongue-drum starter songbook (#3)
    * feat(learn-to-play): add wood-shell-tongue-drum starter songbook (R4 claude-dan)
    Drop learn-to-play/ with 00-INDEX.md, scales/, fingerings/, and
    5 tunes (ABC + LilyPond + songsheet + notes). All tunes are
    public-domain traditional arrangements or original Heifer Zephyr
    compositions (MIT). Notation is at concert pitch; no external
    rendering tools required to read the ABC files.
    * fix: strip trailing whitespace from learn-to-play markdown files
    ---------
2026-05-20 Merge wood-shell tongue drum V5 readiness baseline
    * Add V5 explorer readiness packet
    * Clarify V5 readiness estimates
    * Clarify exercised workflow wording
    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
    [validation-loop.csv, visual-output-register.csv]
2026-05-30 v5(wood-shell-tongue-drum): honest packet surface (Refs #1) (#5)
    [visual-output-register.csv]
2026-05-31 Add image-gen concept prompt; wire explorer images
2026-05-31 Add deployable Wolfram interactive model + wire live explorer embed
    Model returns a bare Manipulate (SaveDefinitions->True); CloudDeploy'd Public.
2026-06-21 Wire 4 rendered concept image(s) into explorer gallery
2026-07-02 V5 packet refresh: status line, provenance, parametric OpenSCAD master, evolution intake
    - README status line already compliant (L2 V5 build-packet candidate), no change needed.
    - Authored cad/wood-shell-tongue-drum.scad: parametric shell + soundboard
    envelope and tongue position/length layout reference marks, from design.md
    §4's build table and drawing-brief.md Sheet 03's zigzag-ascending position
    grid. Slit-routing cut geometry and gu port placement are intentionally out
    of scope (no cut-path source; no (r,theta) for the port in the design
    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
    [visual-output-register.csv, wood-shell-tongue-drum.scad]
